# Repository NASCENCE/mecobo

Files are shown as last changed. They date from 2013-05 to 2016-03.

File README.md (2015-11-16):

# mecobo

Mecobo is an open source experimental platform made for the EU-funded NASCENCE project.

It consists of a custom produced PCB, communicating with a host computer using
a USB 2.0 interface. The host computer runs a Thrift Server that exposes the features of the board through a Thrift Interface.

### The most recent branch is Mecobo_v4.1.

What follows is a short description of each of the subfolders.

## host
This contains the implementation of the Thrift server that uses the board as
it's backend. Also contains makefile for linux based systems.

## fpga
This contains the HDL of the hardware that runs on the FPGA on the Mecobo
motherboard.

## uc 
This contains the firmware that runs on the microcontroller of the Mecobo
motherboard. This is the unit that exposes the USB interface to the host
computer.

## interface_hardware
This contains the Altium schematics and also preproduced Gerber files that you
can use to produce your own version of the board.

## winbuild
This contains a Visual Studio project which you can use to build the Thrift
server to run on a windows machine.

## EMServer
Contains a 'dummy' implementation of the Thrift server to be used for testing, and various support software to be used on the client side. 

# Misc

### specifications

Daughterboards has 16 pins. Each daughterboard has max 8 analogue inputs and 8
analogue outputs, along with potentially 16 digital channels througout the
entire stack.

With 1 daughterboard connected, there is a maximum samplerate of about 200K
samples/second output for each of the analoge output pins. For analogue input, a
maxium rate of 75K samples/second. These rates are divided by 8 for each
stacked daughterboard. Note that these are absolute maximum ratings that can be
achieved, and that these numbers depend highly on the usage pattern of the stack.

With no daughterboard connected, each IO pin controlled by the fpga can toggle
at rates > 10MHz.

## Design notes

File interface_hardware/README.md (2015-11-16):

# Hardware interface files

These directories contain ALTIUM project files and schematic files for
producing your own version of the NASCENCE interface hardware. 

### mecobo_motherboard

This is the "motherboard", which we call "mecobo". It can connect to the material directly.

### mixed_signal_daughterboard

This is the mixed signal daughterboard, which is a daughterboard that connects to the mecobo motherboard.

### crossbar_NI_PCB

This is a special board created for the project that acts as a break-out board
for a National  Instruments cable.

## Gerber files

The directories also contain the subdirectory generated/. This contains the
gerber and NC drill files you need to make a PCB without going through Altium.
You should be able to zip up these files and send them to your favorite PCB
manufacturer for production.

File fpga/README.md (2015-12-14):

# FPGA design

What follows are a few brief comments about how the FPGA design is done.

The system is composed of the modules "digital pincontroller", "adc controller", "dac controller" and some FIFOs that receieve commands from the microcontroller and pushes collected samples to the microcontroller.

The EBI bus connects these modules to the microcontroller interface.

## EBI bus and ebi interface
20 bit address, 16 bit data word Interface bus. The EBI interface module takes
care of all requests to the physical interface. The microcontroller can read the
status register from address 0 and write 80-bit commands on addresses 1 through
5. After address 5 has been written, the command is pushed to the 'command
   FIFO', whose outputs are read by the 'scheduler' unit. This unit looks at the
   timestamp (the topmost 32 bits of the command) to decide if the command is to
   be scheduled. This process is controlled by a 1MHz clock, effectively giving
   a 1us scheduling granularity.

## Digital pin controller
Numerically Controlled Oscillator with a 32 bit phase accumulator-based design.

## ADC controller
Forwards commands from the EBI bus and shifts them out serially to the ADC via the SPI interface.
Also continuously shifts in sampling data from the ADC. User sets sampling rate which effectively discards the unused samples by setting an overflow register that counts the number of cycles between each wanted sample that's ready for harvest.

## DAC controller
Shifts out data to the DAC serially.

## Sample collector 
Programmed by appending the channels to a list. The list is iterated round-robin, and if a unit (ADC/Digital pin controller) has a new sample ready (based on the user's sample rate selection of the ADC/PC) a new sample is pushed to a FIFO that can be read from the EBI interface.

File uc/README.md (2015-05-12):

# Firmware

This contains the firmware that runs on the microcontroller (an EFM32GG990F1024
at 48MHz) on the Mecobo motherboard.

## Building

Running build.sh will attempt to: 
- download the dependency Energy Micro / Silicon Labs libraries, and unzip them in the current directory.
- download the Linaro ARM GCC Toolchain and unzip it in the current directory (might want to install this properly)
- build the firmware

If something fails, it shouldn't be too hard to discern what needs to be done by peeking at build.sh.

# NOR Flash
This version of the board contains a 256Mb NOR flash that holds
bitfiles. The first 512 bytes is reserved for a file allocation table
that holds information about the rest of the chip. The region is divided
into 512/16=32 fields, where each field is laid out as follows:

0 -  7: File identifier
8 - 11: File size
12 -15: Byte-offset of file in chip.

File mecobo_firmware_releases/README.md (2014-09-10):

= Firmware releases =
This folder contains firmware binary files that we from time to time compile. It contains two FPGA bitfiles, one for daughterboard attached, and one without. It also contains the ELF binary for the microcontroller.

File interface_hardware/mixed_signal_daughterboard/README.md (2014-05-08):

-Mixed signal daughterboard-

This folder contains the ALTIUM schematic files for the mixed signal
daughterboard that is compatible with the mecobo motherboard.

In the generated/ subfolder you will find:
 - Gerber files (*.G..)
 - PDF of schematics and PCB (daughterboard.pdf)

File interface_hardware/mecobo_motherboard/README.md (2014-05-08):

= INTERFACE HARDWARE =

This directory contains the ALTIUM Schematic documents, and PCB files for
the Mecobo Interface hardware.

In the generated/ subfolder you will find Gerber files and NC drill files
which you can use to create a version of the board if you want to. You
will also find mecobo3.pdf, which is a PDF version of the schematics and
the PCB files.

- Technical details - 
8 layer PCB, copper plated top and bottom. 0.2mm minimum clearance.

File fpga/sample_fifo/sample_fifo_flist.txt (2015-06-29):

# Output products list for <sample_fifo>
sample_fifo/doc/fifo_generator_v9_3_readme.txt
sample_fifo/doc/fifo_generator_v9_3_vinfo.html
sample_fifo/doc/pg057-fifo-generator.pdf
sample_fifo/example_design/sample_fifo_exdes.ucf
sample_fifo/example_design/sample_fifo_exdes.vhd
sample_fifo/fifo_generator_v9_3_readme.txt
sample_fifo/implement/implement.bat
sample_fifo/implement/implement.sh
sample_fifo/implement/implement_synplify.bat
sample_fifo/implement/implement_synplify.sh
sample_fifo/implement/planAhead_ise.bat
sample_fifo/implement/planAhead_ise.sh
sample_fifo/implement/planAhead_ise.tcl
sample_fifo/implement/xst.prj
sample_fifo/implement/xst.scr
sample_fifo/simulation/functional/simulate_isim.bat
sample_fifo/simulation/functional/simulate_isim.sh
sample_fifo/simulation/functional/simulate_mti.bat
sample_fifo/simulation/functional/simulate_mti.do
sample_fifo/simulation/functional/simulate_mti.sh
sample_fifo/simulation/functional/simulate_ncsim.sh
sample_fifo/simulation/functional/simulate_vcs.sh
sample_fifo/simulation/functional/ucli_commands.key
sample_fifo/simulation/functional/vcs_session.tcl
sample_fifo/simulation/functional/wave_isim.tcl
sample_fifo/simulation/functional/wave_mti.do
sample_fifo/simulation/functional/wave_ncsim.sv
sample_fifo/simulation/sample_fifo_dgen.vhd
sample_fifo/simulation/sample_fifo_dverif.vhd
sample_fifo/simulation/sample_fifo_pctrl.vhd
sample_fifo/simulation/sample_fifo_pkg.vhd
sample_fifo/simulation/sample_fifo_rng.vhd
sample_fifo/simulation/sample_fifo_synth.vhd
sample_fifo/simulation/sample_fifo_tb.vhd
sample_fifo/simulation/timing/simulate_isim.bat
sample_fifo/simulation/timing/simulate_isim.sh
sample_fifo/simulation/timing/simulate_mti.bat
sample_fifo/simulation/timing/simulate_mti.do
sample_fifo/simulation/timing/simulate_mti.sh
sample_fifo/simulation/timing/simulate_ncsim.sh
sample_fifo/simulation/timing/simulate_vcs.sh
sample_fifo/simulation/timing/ucli_commands.key
sample_fifo/simulation/timing/vcs_session.tcl
sample_fifo/simulation/timing/wave_isim.tcl
sample_fifo/simulation/timing/wave_mti.do
sample_fifo/simulation/timing/wave_ncsim.sv
sample_fifo.asy
sample_fifo.gise
sample_fifo.ngc
sample_fifo.v
sample_fifo.veo
sample_fifo.xco
sample_fifo.xise
sample_fifo_flist.txt
sample_fifo_xmdf.tcl

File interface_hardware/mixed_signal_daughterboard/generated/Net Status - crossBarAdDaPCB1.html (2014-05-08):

Altium customize

# Net Status Report

Date | : | 03.03.2014
Time | : | 17:36:52
Elapsed Time | : | 00:00:00
Filename | : | C:\Users\gunnart\Dropbox\InterfaceHW\PCB\crossBarAdDa\PCB_Project1 (06-02-2014 15-46-04)\crossBarAdDaPCB1.PcbDoc
Units | : | mmmils

Nets | Layer | Length
-12V | Signal Layers Only | 128.0226mm
12V | Signal Layers Only | 114.0559mm
AGND | Signal Layers Only | 168.261mm
CONNECT_0 | Signal Layers Only | 79.0628mm
CONNECT_1 | Signal Layers Only | 78.3524mm
CONNECT_10 | Signal Layers Only | 90.4802mm
CONNECT_11 | Signal Layers Only | 90.0555mm
CONNECT_12 | Signal Layers Only | 91.4366mm
CONNECT_13 | Signal Layers Only | 93.5986mm
CONNECT_14 | Signal Layers Only | 95.1107mm
CONNECT_15 | Signal Layers Only | 106.7727mm
CONNECT_2 | Signal Layers Only | 78.8532mm
CONNECT_3 | Signal Layers Only | 79.8531mm
CONNECT_4 | Signal Layers Only | 80.936mm
CONNECT_5 | Signal Layers Only | 81.8458mm
CONNECT_6 | Signal Layers Only | 82.405mm
CONNECT_7 | Signal Layers Only | 85.9289mm
CONNECT_8 | Signal Layers Only | 88.9035mm
CONNECT_9 | Signal Layers Only | 90.154mm
DIO0 | Signal Layers Only | 173.5972mm
DIO1 | Signal Layers Only | 171.2606mm
DIO10 | Signal Layers Only | 161.2825mm
DIO11 | Signal Layers Only | 159.9802mm
DIO12 | Signal Layers Only | 158.9654mm
DIO13 | Signal Layers Only | 157.1153mm
DIO14 | Signal Layers Only | 157.6435mm
DIO15 | Signal Layers Only | 159.6454mm
DIO2 | Signal Layers Only | 168.2809mm
DIO3 | Signal Layers Only | 168.4141mm
DIO4 | Signal Layers Only | 170.8003mm
DIO5 | Signal Layers Only | 168.801mm
DIO6 | Signal Layers Only | 166.8415mm
DIO7 | Signal Layers Only | 165.5094mm
DIO8 | Signal Layers Only | 164.4435mm
DIO9 | Signal Layers Only | 163.1128mm
GND | Signal Layers Only | 37.7343mm
Net*1_15 | Signal Layers Only | 33.1769mm
Net*1_16 | Signal Layers Only | 70.4425mm
Net*1_17 | Signal Layers Only | 47.7717mm
Net*1_18 | Signal Layers Only | 72.7822mm
Net*1_19 | Signal Layers Only | 58.9861mm
Net*1_20 | Signal Layers Only | 95.6486mm
Net*1_21 | Signal Layers Only | 60.9213mm
Net*1_22 | Signal Layers Only | 88.7957mm
Net*1_23 | Signal Layers Only | 41.3441mm
Net*1_24 | Signal Layers Only | 43.1173mm
Net*1_25 | Signal Layers Only | 45.8432mm
Net*1_26 | Signal Layers Only | 46.4241mm
Net*1_27 | Signal Layers Only | 42.7648mm
Net*1_28 | Signal Layers Only | 45.9637mm
Net*1_29 | Signal Layers Only | 51.0543mm
Net*1_30 | Signal Layers Only | 56.0322mm
Net*1_44 | Signal Layers Only | 40.515mm
NetC51_1 | Signal Layers Only | 16.1984mm
NetC55_1 | Signal Layers Only | 2.7982mm
NetP1_1 | Signal Layers Only | 17.2157mm
NetP1_3 | Signal Layers Only | 18.7141mm
NetP1_5 | Signal Layers Only | 20.5357mm
NetP1_7 | Signal Layers Only | 21.6133mm
NetP2_1 | Signal Layers Only | 11.4443mm
NetP2_2 | Signal Layers Only | 50.101mm
NetP2_3 | Signal Layers Only | 15.9292mm
NetP2_5 | Signal Layers Only | 20.3396mm
NetP2_7 | Signal Layers Only | 25.0476mm
NetP3_1 | Signal Layers Only | 11.2249mm
NetP3_3 | Signal Layers Only | 13.6469mm
NetP3_5 | Signal Layers Only | 14.8117mm
NetP3_7 | Signal Layers Only | 16.6024mm
NetP4_1 | Signal Layers Only | 9.9421mm
NetP4_2 | Signal Layers Only | 40.558mm
NetP4_3 | Signal Layers Only | 12.7797mm
NetP4_5 | Signal Layers Only | 17.7109mm
NetP4_7 | Signal Layers Only | 21.7929mm
NetP5_1 | Signal Layers Only | 6.1794mm
NetP5_3 | Signal Layers Only | 9.4251mm
NetP5_5 | Signal Layers Only | 13.5379mm
NetP5_7 | Signal Layers Only | 19.3619mm
NetP6_1 | Signal Layers Only | 14.0768mm
NetP6_2 | Signal Layers Only | 21.4842mm
NetP6_3 | Signal Layers Only | 15.8728mm
NetP6_5 | Signal Layers Only | 21.7584mm
NetP6_7 | Signal Layers Only | 23.0773mm
NetP7_1 | Signal Layers Only | 12.9864mm
NetP7_2 | Signal Layers Only | 117.0562mm
NetP7_3 | Signal Layers Only | 15.8765mm
NetP7_5 | Signal Layers Only | 21.6006mm
NetP7_7 | Signal Layers Only | 22.6038mm
NetP8_1 | Signal Layers Only | 11.9794mm
NetP8_2 | Signal Layers Only | 122.0288mm
NetP8_3 | Signal Layers Only | 15.5917mm
NetP8_5 | Signal Layers Only | 20.1637mm
NetP8_7 | Signal Layers Only | 21.6006mm
NetP9_1 | Signal Layers Only | 10.8056mm
NetP9_2 | Signal Layers Only | 133.4299mm
NetP9_3 | Signal Layers Only | 13.9099mm
NetP9_5 | Signal Layers Only | 18.9028mm
NetP9_7 | Signal Layers Only | 20.5447mm
NetPnorth1_2 | Signal Layers Only | 73.8369mm
NetPnorth1_4 | Signal Layers Only | 78.8482mm
NetR10_1 | Signal Layers Only | 8.6112mm
NetR13_1 | Signal Layers Only | 8.2302mm
NetR14_1 | Signal Layers Only | 8.2828mm
NetR17_1 | Signal Layers Only | 8.1552mm
NetR1_1 | Signal Layers Only | 7.7829mm
NetR20_1 | Signal Layers Only | 8.2865mm
NetR22_1 | Signal Layers Only | 7.6281mm
NetR24_1 | Signal Layers Only | 8.2647mm
NetR27_2 | Signal Layers Only | 3.2607mm
NetR2_1 | Signal Layers Only | 8.252mm
NetR5_1 | Signal Layers Only | 8.4316mm
NetR6_1 | Signal Layers Only | 8.4316mm
NetR9_1 | Signal Layers Only | 7.6986mm
NetU1_1 | Signal Layers Only | 0mm
NetU1_3 | Signal Layers Only | 44.6679mm
NetU2_1 | Signal Layers Only | 0mm
NetU2_3 | Signal Layers Only | 38.7336mm
NetU3_1 | Signal Layers Only | 0mm
NetU3_3 | Signal Layers Only | 26.9793mm
NetU4_1 | Signal Layers Only | 0mm
NetU4_3 | Signal Layers Only | 38.0461mm
NetU5_1 | Signal Layers Only | 0mm
NetU5_3 | Signal Layers Only | 26.8062mm
NetU6_1 | Signal Layers Only | 0mm
NetU6_3 | Signal Layers Only | 21.6926mm
NetU7_1 | Signal Layers Only | 0mm
NetU7_3 | Signal Layers Only | 16.7116mm
NetU8_1 | Signal Layers Only | 0mm
NetU8_3 | Signal Layers Only | 26.9256mm
PCKL_XBAR | Signal Layers Only | 123.3795mm
SCLK_XBAR | Signal Layers Only | 205.1017mm
SDATA_FROM_XBAR | Signal Layers Only | 121.6941mm
SDATA_TO_XBAR | Signal Layers Only | 85.9763mm
VA5+ | Signal Layers Only | 234.7269mm
VA5- | Signal Layers Only | 111.3096mm
VADRIVE+ | Signal Layers Only | 264.5179mm
VADRIVE- | Signal Layers Only | 249.2073mm
VANEG | Signal Layers Only | 307.8802mm
VAPOS | Signal Layers Only | 301.2715mm
VCC | Signal Layers Only | 164.1396mm
VDIG | Signal Layers Only | 157.2368mm
VREFDA | Signal Layers Only | 145.7971mm
XGND | Signal Layers Only | 5.7882mm

Back to top

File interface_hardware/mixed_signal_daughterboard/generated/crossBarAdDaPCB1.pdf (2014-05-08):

Comment | Description | Designator | Footprint | LibRef | Quantity
AD5308BRUZ | Octal 8-Bit Voltage Output Digital-to-Analog Converter, 2.5 to 5.5 V, -40 to +125 degC, RU-16, Pb-Free, Tube | U14 | RU-16_N | AD5308BRUZ | 1
AD7327BRUZ | Octal 12-Bit True Bipolar Input Plus Sign Analog-to-Digital Converter with Serial, SPI Interface, Software-Selectable, 500KSPS, -40 to +85 degC, RU-20, Pb-Free, Tube | U15 | RU-20_N | AD7327BRUZ | 1
Header 18X2 | Header, 18-Pin, Dual row | P10 | HDR2X18 | Header 18X2 | 1
Header 3X2 | Header, 3-Pin, Dual row | P13 | HDR2X3 | Header 3X2 | 1
Header 6 | Header, 6-Pin | P12 | HDR1X6 | Header 6 | 1
LT3080EST | Adjustable 1.1 A Single Resistor Low Dropout Regulator, 0.3 mA Isupply, 3-pin SOT223 (ST-3), -40 to 125 degC | U13 | LT-ST-3-SOT-223_N | LT3080EST | 1
REF19x Serie | | *3 | SOIC127P600-8M | REF19x Serie | 1
AD75019 | crosspoint 16x16 | *1, *2 | PLCC-44AL | Component_ 1 | 2
Ferrit | Resistor | R19, R26 | AXIAL-0.4 | Res2 | 2
Header 30X2 | Header, 30-Pin, Dual row | Pnorth1, Pwest1 | HDR2X30 | Header 30X2 | 2
LT1963AEQ | 1.5 A, Low Noise, Fast Transient Response LDO Regulator, 2.1 to 20 V Vin, Adjustable Vout, 5-pin DPAK (Q-5), -40 to 125 degC | U9, U11 | LT-Q-5_N | LT1963AEQ | 2
LT3015EQ#TRPBF | 1.5 A, Low Noise, Negative Linear Regulator with Precision Current Limit, -1.8 to -30 V Vin, Adjustable Vout, 5-pin DPAK (Q-5), -40 to 125 degC, Pb-Free, Tape and Reel | U10, U12 | LT-Q-5_N | LT3015EQ#TR PBF | 2
AD820BR | Single-Supply, Rail-to-Rail Low-Power FET-Input Operational Amplifier | U1, U2, U3, U4, U5, U6, U7, U8 | R-8D_N | AD820BR | 8
Header 4X2 | Header, 4-Pin, Dual row | P1, P2, P3, P4, P5, P6, P7, P8, P9 | HDR2X4 | Header 4X2 | 9
Res3 | Resistor | R17, R18, R20, R21, R22, R23, R24, R25, R27 | 14-1210 | Res3 | 9
Res1 | Resistor | R1, R2, R3, R4, R5, R6, R7, R8, R9, R10, R11, R12, R13, R14, R15, R16 | C1206 | Res1 | 16
Cap Semi | Capacitor (Semiconductor SIM MoC1, C 2, C3, C4, C5, C6, | | 1206 | Cap S em i | 55

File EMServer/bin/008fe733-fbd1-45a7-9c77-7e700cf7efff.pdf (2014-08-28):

# PIN15

# PIN14

# PIN13

# PIN12

# PIN11

# PIN10

# PIN09

# PIN08

# PIN07

# PIN06

# PIN05

# PIN04

# PIN02

# PIN01

# PIN00

CONSTANT 1V

CONSTANT 1V

CONSTANT 1V

CONSTANT 1V

CONSTANT 1V

CONSTANT 1V

CONSTANT 1V

CONSTANT 1V

CONSTANT 1V

CONSTANT 1V

CONSTANT 1V

CONSTANT 1V

CONSTANT 1V

CONSTANT 1V

CONSTANT 1V

CONSTANT 1V

CONSTANT 1V

CONSTANT 1V

CONSTANT 1V

CONSTANT 1V

CONSTANT 1V

CONSTANT 1V

CONSTANT 1V

CONSTANT 1V

CONSTANT 1V

CONSTANT 1V

CONSTANT 1V

CONSTANT 1V

CONSTANT 1V

CONSTANT 1V

CONSTANT 16V

CONSTANT 16V

CONSTANT 16V

CONSTANT 16V

CONSTANT 16V

CONSTANT 16V

CONSTANT 16V

CONSTANT 16V

CONSTANT 16V

CONSTANT 16V

CONSTANT 16V

CONSTANT 16V

CONSTANT 16V

CONSTANT 16V

CONSTANT 16V

CONSTANT 20V

CONSTANT 20V

CONSTANT 20V

CONSTANT 20V

CONSTANT 20V

CONSTANT 20V

CONSTANT 20V

CONSTANT 20V

CONSTANT 20V

CONSTANT 20V

CONSTANT 20V

CONSTANT 20V

CONSTANT 20V

CONSTANT 20V

CONSTANT 20V

CONSTANT 168V

CONSTANT 168V

CONSTANT 168V

CONSTANT 168V

CONSTANT 168V

CONSTANT 168V

CONSTANT 168V

CONSTANT 168V

CONSTANT 168V

CONSTANT 168V

CONSTANT 168V

CONSTANT 168V

CONSTANT 168V

CONSTANT 168V

CONSTANT 168V

CONSTANT 110V

CONSTANT 110V

CONSTANT 110V

CONSTANT 110V

CONSTANT 110V

CONSTANT 110V

CONSTANT 110V

CONSTANT 110V

CONSTANT 110V

CONSTANT 110V

CONSTANT 110V

CONSTANT 110V

CONSTANT 110V

CONSTANT 110V

CONSTANT 110V

CONSTANT 9V

CONSTANT 9V

CONSTANT 9V

CONSTANT 9V

CONSTANT 9V

CONSTANT 9V

CONSTANT 9V

CONSTANT 9V

CONSTANT 9V

CONSTANT 9V

CONSTANT 9V

CONSTANT 9V

CONSTANT 9V

CONSTANT 9V

CONSTANT 9V

RECORD

RECORD

RECORD

RECORD

RECORD

RECORD

RECORD

RECORD

RECORD

RECORD

RECORD

RECORD

RECORD

RECORD

RECORD

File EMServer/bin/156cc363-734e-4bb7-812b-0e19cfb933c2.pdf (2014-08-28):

# PIN15

# PIN14

# PIN13

# PIN12

# PIN11

# PIN10

# PIN09

# PIN07

# PIN06

# PIN05

# PIN04

# PIN02

# PIN01

# PIN00

CONSTANT 255V

CONSTANT 255V

CONSTANT 255V

CONSTANT 255V

CONSTANT 255V

CONSTANT 255V

CONSTANT 255V

CONSTANT 255V

CONSTANT 255V

CONSTANT 255V

CONSTANT 255V

CONSTANT 255V

CONSTANT 255V

CONSTANT 255V

CONSTANT 255V

CONSTANT 255V

CONSTANT 255V

CONSTANT 255V

CONSTANT 255V

CONSTANT 255V

CONSTANT 255V

CONSTANT 255V

CONSTANT 255V

CONSTANT 255V

CONSTANT 255V

CONSTANT 255V

CONSTANT 153V

CONSTANT 153V

CONSTANT 153V

CONSTANT 153V

CONSTANT 153V

CONSTANT 153V

CONSTANT 153V

CONSTANT 153V

CONSTANT 153V

CONSTANT 153V

CONSTANT 153V

CONSTANT 153V

CONSTANT 153V

CONSTANT 90V

CONSTANT 90V

CONSTANT 90V

CONSTANT 90V

CONSTANT 90V

CONSTANT 90V

CONSTANT 90V

CONSTANT 90V

CONSTANT 90V

CONSTANT 90V

CONSTANT 90V

CONSTANT 90V

CONSTANT 90V

CONSTANT 203V

CONSTANT 203V

CONSTANT 203V

CONSTANT 203V

CONSTANT 203V

CONSTANT 203V

CONSTANT 203V

CONSTANT 203V

CONSTANT 203V

CONSTANT 203V

CONSTANT 203V

CONSTANT 203V

CONSTANT 203V

CONSTANT 218V

CONSTANT 218V

CONSTANT 218V

CONSTANT 218V

CONSTANT 218V

CONSTANT 218V

CONSTANT 218V

CONSTANT 218V

CONSTANT 218V

CONSTANT 218V

CONSTANT 218V

CONSTANT 218V

CONSTANT 218V

CONSTANT 17V

CONSTANT 17V

CONSTANT 17V

CONSTANT 17V

CONSTANT 17V

CONSTANT 17V

CONSTANT 17V

CONSTANT 17V

CONSTANT 17V

CONSTANT 17V

CONSTANT 17V

CONSTANT 17V

CONSTANT 17V

RECORD

RECORD

RECORD

RECORD

RECORD

RECORD

RECORD

RECORD

RECORD

RECORD

RECORD

RECORD

RECORD

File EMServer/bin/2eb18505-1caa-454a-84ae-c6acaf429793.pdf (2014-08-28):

# PIN15

# PIN14

# PIN13

# PIN12

# PIN11

# PIN10

# PIN09

# PIN08

# PIN07

# PIN06

# PIN05

# PIN04

# PIN02

# PIN01

# PIN00

CONSTANT 1V

CONSTANT 1V

CONSTANT 1V

CONSTANT 1V

CONSTANT 1V

CONSTANT 1V

CONSTANT 1V

CONSTANT 1V

CONSTANT 1V

CONSTANT 1V

CONSTANT 1V

CONSTANT 1V

CONSTANT 1V

CONSTANT 1V

CONSTANT 1V

CONSTANT 255V

CONSTANT 255V

CONSTANT 255V

CONSTANT 255V

CONSTANT 255V

CONSTANT 255V

CONSTANT 255V

CONSTANT 255V

CONSTANT 255V

CONSTANT 255V

CONSTANT 255V

CONSTANT 255V

CONSTANT 255V

CONSTANT 255V

CONSTANT 255V

CONSTANT 148V

CONSTANT 148V

CONSTANT 148V

CONSTANT 148V

CONSTANT 148V

CONSTANT 148V

CONSTANT 148V

CONSTANT 148V

CONSTANT 148V

CONSTANT 148V

CONSTANT 148V

CONSTANT 148V

CONSTANT 148V

CONSTANT 148V

CONSTANT 148V

CONSTANT 88V

CONSTANT 88V

CONSTANT 88V

CONSTANT 88V

CONSTANT 88V

CONSTANT 88V

CONSTANT 88V

CONSTANT 88V

CONSTANT 88V

CONSTANT 88V

CONSTANT 88V

CONSTANT 88V

CONSTANT 88V

CONSTANT 88V

CONSTANT 88V

CONSTANT 20V

CONSTANT 20V

CONSTANT 20V

CONSTANT 20V

CONSTANT 20V

CONSTANT 20V

CONSTANT 20V

CONSTANT 20V

CONSTANT 20V

CONSTANT 20V

CONSTANT 20V

CONSTANT 20V

CONSTANT 20V

CONSTANT 20V

CONSTANT 20V

CONSTANT 87V

CONSTANT 87V

CONSTANT 87V

CONSTANT 87V

CONSTANT 87V

CONSTANT 87V

CONSTANT 87V

CONSTANT 87V

CONSTANT 87V

CONSTANT 87V

CONSTANT 87V

CONSTANT 87V

CONSTANT 87V

CONSTANT 87V

CONSTANT 87V

CONSTANT 247V

CONSTANT 247V

CONSTANT 247V

CONSTANT 247V

CONSTANT 247V

CONSTANT 247V

CONSTANT 247V

CONSTANT 247V

CONSTANT 247V

CONSTANT 247V

CONSTANT 247V

CONSTANT 247V

CONSTANT 247V

CONSTANT 247V

CONSTANT 247V

RECORD

RECORD

RECORD

RECORD

RECORD

RECORD

RECORD

RECORD

RECORD

RECORD

RECORD

RECORD

RECORD

RECORD

RECORD

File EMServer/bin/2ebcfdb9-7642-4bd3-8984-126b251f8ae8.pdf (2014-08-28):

# PIN15

# PIN14

# PIN13

# PIN12

# PIN11

# PIN10

# PIN09

# PIN08

# PIN07

# PIN06

# PIN05

# PIN04

# PIN02

# PIN01

# PIN00

CONSTANT 255V

CONSTANT 255V

CONSTANT 255V

CONSTANT 255V

CONSTANT 255V

CONSTANT 255V

CONSTANT 255V

CONSTANT 255V

CONSTANT 255V

CONSTANT 255V

CONSTANT 255V

CONSTANT 255V

CONSTANT 255V

CONSTANT 255V

CONSTANT 255V

CONSTANT 255V

CONSTANT 255V

CONSTANT 255V

CONSTANT 255V

CONSTANT 255V

CONSTANT 255V

CONSTANT 255V

CONSTANT 255V

CONSTANT 255V

CONSTANT 255V

CONSTANT 255V

CONSTANT 255V

CONSTANT 255V

CONSTANT 255V

CONSTANT 255V

CONSTANT 60V

CONSTANT 60V

CONSTANT 60V

CONSTANT 60V

CONSTANT 60V

CONSTANT 60V

CONSTANT 60V

CONSTANT 60V

CONSTANT 60V

CONSTANT 60V

CONSTANT 60V

CONSTANT 60V

CONSTANT 60V

CONSTANT 60V

CONSTANT 60V

CONSTANT 26V

CONSTANT 26V

CONSTANT 26V

CONSTANT 26V

CONSTANT 26V

CONSTANT 26V

CONSTANT 26V

CONSTANT 26V

CONSTANT 26V

CONSTANT 26V

CONSTANT 26V

CONSTANT 26V

CONSTANT 26V

CONSTANT 26V

CONSTANT 26V

CONSTANT 208V

CONSTANT 208V

CONSTANT 208V

CONSTANT 208V

CONSTANT 208V

CONSTANT 208V

CONSTANT 208V

CONSTANT 208V

CONSTANT 208V

CONSTANT 208V

CONSTANT 208V

CONSTANT 208V

CONSTANT 208V

CONSTANT 208V

CONSTANT 208V

CONSTANT 122V

CONSTANT 122V

CONSTANT 122V

CONSTANT 122V

CONSTANT 122V

CONSTANT 122V

CONSTANT 122V

CONSTANT 122V

CONSTANT 122V

CONSTANT 122V

CONSTANT 122V

CONSTANT 122V

CONSTANT 122V

CONSTANT 122V

CONSTANT 122V

CONSTANT 103V

CONSTANT 103V

CONSTANT 103V

CONSTANT 103V

CONSTANT 103V

CONSTANT 103V

CONSTANT 103V

CONSTANT 103V

CONSTANT 103V

CONSTANT 103V

CONSTANT 103V

CONSTANT 103V

CONSTANT 103V

CONSTANT 103V

CONSTANT 103V

RECORD

RECORD

RECORD

RECORD

RECORD

RECORD

RECORD

RECORD

RECORD

RECORD

RECORD

RECORD

RECORD

RECORD

RECORD

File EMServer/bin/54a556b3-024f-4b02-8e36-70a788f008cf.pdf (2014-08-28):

# PIN15

# PIN14

# PIN13

# PIN12

# PIN11

# PIN10

# PIN09

# PIN08

# PIN07

# PIN06

# PIN05

# PIN02

# PIN01

# PIN00

CONSTANT 1V

CONSTANT 1V

CONSTANT 1V

CONSTANT 1V

CONSTANT 1V

CONSTANT 1V

CONSTANT 1V

CONSTANT 1V

CONSTANT 1V

CONSTANT 1V

CONSTANT 1V

CONSTANT 1V

CONSTANT 1V

CONSTANT 255V

CONSTANT 255V

CONSTANT 255V

CONSTANT 255V

CONSTANT 255V

CONSTANT 255V

CONSTANT 255V

CONSTANT 255V

CONSTANT 255V

CONSTANT 255V

CONSTANT 255V

CONSTANT 255V

CONSTANT 255V

CONSTANT 105V

CONSTANT 105V

CONSTANT 105V

CONSTANT 105V

CONSTANT 105V

CONSTANT 105V

CONSTANT 105V

CONSTANT 105V

CONSTANT 105V

CONSTANT 105V

CONSTANT 105V

CONSTANT 105V

CONSTANT 105V

CONSTANT 226V

CONSTANT 226V

CONSTANT 226V

CONSTANT 226V

CONSTANT 226V

CONSTANT 226V

CONSTANT 226V

CONSTANT 226V

CONSTANT 226V

CONSTANT 226V

CONSTANT 226V

CONSTANT 226V

CONSTANT 226V

CONSTANT 222V

CONSTANT 222V

CONSTANT 222V

CONSTANT 222V

CONSTANT 222V

CONSTANT 222V

CONSTANT 222V

CONSTANT 222V

CONSTANT 222V

CONSTANT 222V

CONSTANT 222V

CONSTANT 222V

CONSTANT 222V

CONSTANT 171V

CONSTANT 171V

CONSTANT 171V

CONSTANT 171V

CONSTANT 171V

CONSTANT 171V

CONSTANT 171V

CONSTANT 171V

CONSTANT 171V

CONSTANT 171V

CONSTANT 171V

CONSTANT 171V

CONSTANT 171V

CONSTANT 96V

CONSTANT 96V

CONSTANT 96V

CONSTANT 96V

CONSTANT 96V

CONSTANT 96V

CONSTANT 96V

CONSTANT 96V

CONSTANT 96V

CONSTANT 96V

CONSTANT 96V

CONSTANT 96V

CONSTANT 96V

RECORD

RECORD

RECORD

RECORD

RECORD

RECORD

RECORD

RECORD

RECORD

RECORD

RECORD

RECORD

RECORD

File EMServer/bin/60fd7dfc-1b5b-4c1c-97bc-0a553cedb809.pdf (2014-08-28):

# PIN15

# PIN14

# PIN13

# PIN12

# PIN11

# PIN10

# PIN09

# PIN08

# PIN07

# PIN06

# PIN05

# PIN04

# PIN02

# PIN01

# PIN00

CONSTANT 255V

CONSTANT 255V

CONSTANT 255V

CONSTANT 255V

CONSTANT 255V

CONSTANT 255V

CONSTANT 255V

CONSTANT 255V

CONSTANT 255V

CONSTANT 255V

CONSTANT 255V

CONSTANT 255V

CONSTANT 255V

CONSTANT 255V

CONSTANT 255V

CONSTANT 255V

CONSTANT 255V

CONSTANT 255V

CONSTANT 255V

CONSTANT 255V

CONSTANT 255V

CONSTANT 255V

CONSTANT 255V

CONSTANT 255V

CONSTANT 255V

CONSTANT 255V

CONSTANT 255V

CONSTANT 255V

CONSTANT 255V

CONSTANT 255V

CONSTANT 217V

CONSTANT 217V

CONSTANT 217V

CONSTANT 217V

CONSTANT 217V

CONSTANT 217V

CONSTANT 217V

CONSTANT 217V

CONSTANT 217V

CONSTANT 217V

CONSTANT 217V

CONSTANT 217V

CONSTANT 217V

CONSTANT 217V

CONSTANT 217V

CONSTANT 22V

CONSTANT 22V

CONSTANT 22V

CONSTANT 22V

CONSTANT 22V

CONSTANT 22V

CONSTANT 22V

CONSTANT 22V

CONSTANT 22V

CONSTANT 22V

CONSTANT 22V

CONSTANT 22V

CONSTANT 22V

CONSTANT 22V

CONSTANT 22V

CONSTANT 47V

CONSTANT 47V

CONSTANT 47V

CONSTANT 47V

CONSTANT 47V

CONSTANT 47V

CONSTANT 47V

CONSTANT 47V

CONSTANT 47V

CONSTANT 47V

CONSTANT 47V

CONSTANT 47V

CONSTANT 47V

CONSTANT 47V

CONSTANT 47V

CONSTANT 242V

CONSTANT 242V

CONSTANT 242V

CONSTANT 242V

CONSTANT 242V

CONSTANT 242V

CONSTANT 242V

CONSTANT 242V

CONSTANT 242V

CONSTANT 242V

CONSTANT 242V

CONSTANT 242V

CONSTANT 242V

CONSTANT 242V

CONSTANT 242V

CONSTANT 156V

CONSTANT 156V

CONSTANT 156V

CONSTANT 156V

CONSTANT 156V

CONSTANT 156V

CONSTANT 156V

CONSTANT 156V

CONSTANT 156V

CONSTANT 156V

CONSTANT 156V

CONSTANT 156V

CONSTANT 156V

CONSTANT 156V

CONSTANT 156V

RECORD

RECORD

RECORD

RECORD

RECORD

RECORD

RECORD

RECORD

RECORD

RECORD

RECORD

RECORD

RECORD

RECORD

RECORD

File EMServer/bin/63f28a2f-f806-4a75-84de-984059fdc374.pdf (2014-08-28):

# PIN13

# PIN12

# PIN11

# PIN10

# PIN04

# PIN03

# PIN02

# PIN00

CONSTANT 1V

CONSTANT 1V

CONSTANT 1V

CONSTANT 1V

CONSTANT 255V

CONSTANT 255V

CONSTANT 255V

CONSTANT 255V

CONSTANT 35V

CONSTANT 35V

CONSTANT 35V

CONSTANT 35V

CONSTANT 173V

CONSTANT 173V

CONSTANT 173V

CONSTANT 173V

CONSTANT 175V

CONSTANT 175V

CONSTANT 175V

CONSTANT 175V

CONSTANT 188V

CONSTANT 188V

CONSTANT 188V

CONSTANT 188V

CONSTANT 206V

CONSTANT 206V

CONSTANT 206V

CONSTANT 206V

RECORD

RECORD

RECORD

RECORD

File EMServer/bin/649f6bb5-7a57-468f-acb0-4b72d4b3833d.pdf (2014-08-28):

# PIN15

# PIN14

# PIN12

# PIN09

# PIN07

# PIN03

# PIN01

# PIN00

CONSTANT 1V

CONSTANT 1V

CONSTANT 1V

CONSTANT 1V

CONSTANT 1V

CONSTANT 1V

CONSTANT 1V

CONSTANT 1V

CONSTANT 13V

CONSTANT 13V

CONSTANT 13V

CONSTANT 13V

CONSTANT 11V

CONSTANT 11V

CONSTANT 11V

CONSTANT 11V

CONSTANT 201V

CONSTANT 201V

CONSTANT 201V

CONSTANT 201V

CONSTANT 178V

CONSTANT 178V

CONSTANT 178V

CONSTANT 178V

CONSTANT 24V

CONSTANT 24V

CONSTANT 24V

CONSTANT 24V

RECORD

RECORD

RECORD

RECORD

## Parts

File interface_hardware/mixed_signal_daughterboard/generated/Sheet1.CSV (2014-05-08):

Bill of Material for
On 13/01/2014 at 14:21:59
Comment | Pattern | Quantity | Components
AD5308BRUZ | RU-16_N | 1 | U? | Octal 8-Bit Voltage Output Digital-to-Analog Converter, 2.5 to 5.5 V, -40 to +125 degC, RU-16, Pb-Free, Tube
AD7327BRUZ | RU-20_N | 1 | U? | Octal 12-Bit True Bipolar Input Plus Sign Analog-to-Digital Converter with Serial, SPI Interface, Software-Selectable, 500KSPS, -40 to +85 degC, RU-20, Pb-Free, Tube
AD75019 | P-44A_L | 2 | *, * | crosspoint 16x16
AD820BR | R-8D_N | 8 | U?, U?, U?, U?, U?, U?, U?, U? | Single-Supply, Rail-to-Rail Low-Power FET-Input Operational Amplifier
Cap Semi | C1206 | 55 | C?, C?, C?, C?, C?, C?, C?, C?, C?, C?, C?, C?, C?, C?, C?, C?, C?, C?, C?, C?, C?, C?, C?, C?, C?, C?, C?, C?, C?, C?, C?, C?, C?, C?, C?, C?, C?, C?, C?, C?, C?, C?, C?, C?, C?, C?, C?, C?, C?, C?, C?, C?, C?, C?, C? | Capacitor (Semiconductor SIM Model)
Ferrit | AXIAL-0.4 | 2 | R?, R? | Resistor
Header 18X2 | HDR2X18 | 1 | P? | Header, 18-Pin, Dual row
Header 24X2H | HDR2X24H | 1 | P? | Header, 24-Pin, Dual row, Right Angle
Header 30X2 | HDR2X30 | 2 | Pnorth, Pwest | Header, 30-Pin, Dual row
Header 3X2 | HDR2X3 | 1 | P? | Header, 3-Pin, Dual row
Header 4X2 | HDR2X4 | 9 | P?, P?, P?, P?, P?, P?, P?, P?, P? | Header, 4-Pin, Dual row
Header 6 | HDR1X6 | 1 | P? | Header, 6-Pin
LT1963AEQ | LT-Q-5_N | 2 | U?, U? | 1.5 A, Low Noise, Fast Transient Response LDO Regulator, 2.1 to 20 V Vin, Adjustable Vout, 5-pin DPAK (Q-5), -40 to 125 degC
LT3015EQ#TRPBF | LT-Q-5_N | 2 | U?, U? | 1.5 A, Low Noise, Negative Linear Regulator with Precision Current Limit, -1.8 to -30 V Vin, Adjustable Vout, 5-pin DPAK (Q-5), -40 to 125 degC, Pb-Free, Tape and Reel
LT3080EST | LT-ST-3-SOT-223_N | 1 | U? | Adjustable 1.1 A Single Resistor Low Dropout Regulator, 0.3 mA Isupply, 3-pin SOT223 (ST-3), -40 to 125 degC
REF19x Serie | SOIC | 1 | *
Res1 | AXIAL-0.3 | 16 | R?, R?, R?, R?, R?, R?, R?, R?, R?, R?, R?, R?, R?, R?, R?, R? | Resistor
Res3 | 14-1210 | 9 | R?, R?, R?, R?, R?, R?, R?, R?, R? | Resistor

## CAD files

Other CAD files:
winbuild/libusb-win32-src-1.2.6.0/libusb-win32-src-1.2.6.0/projects/additional/libwdi/helper/embedder/embedder.obj

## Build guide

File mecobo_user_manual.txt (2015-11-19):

Mecobo user manual

- At a glance - 
The system consists of three units; the thrift server, the thrift client and
the board. The server runs on a host computer that has the board connected to
it, and the client communicates with the server via an internet socket.

Usage is as simple as:
1 - Plug in the board. Any recent linux kernel has a ACM driver compiled in. As
such you can simply plug in a powered-on (and preconfigured) board. On Windows
you will have to use the provided .ini file and install that as a driver to
enable communication.
2 - Start the Thrift server binary.
3 - Connect to the Thrift server with a Thrift client and send commands to it
using the Thrift interface.

There is a section below on setting up the thrift server; and you can of course
recompile and modify it as you see fit-- however the current implementation should
suffice for simple stuff.

========================================================================================
- USER GUIDE -
========================================================================================

Current version of the board only supports the following modes of operation:

1. Digital output square waves with 50% duty cycle:

Example:
    it = emSequenceItem();
    it.pin = [0];
    it.startTime = 1;
    it.endTime = 1000;
    it.frequency = 500;
    it.operationType = emSequenceOperationType::type::DIGITAL;

2. Digital recording of a pin:

Example:
    rec = emSequenceItem();
    rec.pin = [10];
    rec.starttime = 0;
    rec.endTime = 1000;
    rec.frequency = 5000;
    rec.waveformType = emWaveFormType::PWM; //magic line for digital sampling
    rec.operationType = emSequenceOperationType::type::RECORD;

3. Constant 0 (connect to ground) or 3.3V output on pin

Example:
    it = emSequenceItem();
    it.pin = [4];
    it.starttime = 0;
    it.endTime = 1000;
    it.frequency = 1;   //or 0 for grounding
    it.cycleTime = 100;  //required as well.
    it.operationType = emSequenceOperationType::type::DIGITAL;

4. Analog recording of a pin:

Example:
    rec = emSequenceItem();
    rec.pin = [10];
    rec.starttime = 0;
    rec.endTime = 1000;
    rec.frequency = 5000;  //max total sum of sample rates is 500KHz
    rec.operationType = emSequenceOperationType::type::RECORD;

5. Analog output of voltage:

Example:
    it = emSequenceItem();
    it.pin = [10];
    it.starttime = 0;
    it.endTime = 1000;
    it.amplitude = 242;   //-5 to 5V is scaled between 0 and 255.
    it.operationType = emSequenceOperationType::type::CONSTANT;

=======================================================================================
USER GUIDE WITH MORE WORDS
=======================================================================================

To start the server, place yourself in the directory of the server binary
(usually called winHost), and run it from the command line with:

~> winHost.exe

Now that the server is running on a computer that has the board connected to
it, talking to the board consists of calling the functions described in the
thrift interface description file, NascenseAPI_v01e.thrift. You also need to
generate the code that talks to the server. This is done with the thrift tool.

As an example, here is how you create a client in python:

oddrune @ crabcatcher:~$ thrift --gen py NascenseAPI_v01e.thrift

This gives me a directory called gen-py, that again contains a subdirectory NascenseAPI_v01e.
My python client looks like this:

--
import sys
sys.path.append('gen-py/NascenseAPI_v01e/')
import emEvolvableMotherboard
from ttypes import *

try:
  transport = TSocket.TSocket('dmlab02.idi.ntnu.no', 9090)
  transport = TTransport.TBufferedTransport(transport)

  prot = TBinaryProtocol.TBinaryProtocol(transport)
  cli = emEvolvableMotherboard.Client(prot);
  transport.open();

  cli.ping();

  transport.close();

except Thrift.TException, tx:
  print tx

That's all there is to it. It's similar in most languages and the apache thrift
wiki has more examples. 

- Using the Nascence interface -
Note that all of the examples here are done using python; but it's analogous to
other languages such as C#, C++, perl, ... 

The idea behind the interface is that of a sequencer. Using the function
appendSequenceAction(emSequenceItem) you append an item that performs a certain action.
The emSequenceItem is defined in the interface as well.

Example:
----------------------------------------------------------
it = emSequenceItem()
it.pin = 12;
it.startTime = 42;
it.endTime = 100;
it.amplitude = 0;
it.operationType = emSequenceOperationType().CONSTANT;
client.appendSequenceAction(it)
----------------------------------------------------------

This example creates a sequnce item and appends it to the sequence queue. The output will be -5 Volts on pin 12, if the daughterboard is connected.

Calling client.runSequences() initiates this sequence, and starts the clock at
time = 0. All times referred to in the emSequenceItems are relative to this t,
and time is measured in ms. 

Remember to call client.joinSequences() when you are done so that the board
blocks until it is done.

Another frequenctly used operationType is RECORD:

----------------------------------------------------------
rec = emSequenceItem();
rec.pin = 10;
rec.starttime = 0;
rec.endTime = 1000;
rec.frequency = 5000;
rec.operationType = emSequenceOperationType().RECORD;
client.appendSequenceAction(rec)
----------------------------------------------------------

This will set up pin 10 as a recording pin, which will start recording at t=0, and end at t=1000 at a 
sample frequency of 5Khz.  Doing:

----------------------------------------------------------
recording = cli.getRecording(recordPin);
----------------------------------------------------------

will get you a buffer of the sampled data of about 5000 elements.

If you in addition the above specify 

rec.waveformType = emWaveFormType::PWM 

you will get a digital recording pin,
which only returns a buffer consisting of 1 or 0, depending on if the sampled
signal crossed the threshold for the FPGA input buffer, usually around 2.5V. 

- Other operationTypes - 

DIGITAL
----------------------------------------------------------
it = emSequenceItem();
it.pin = 0;
it.startTime = 1;
it.endTime = 1000;
it.frequency = 500;
it.operationType = emSequenceOperationType::type::DIGITAL;
----------------------------------------------------------

This will set up pin 0 to play a square wave with a cycle time of (1/500)s, of
wich 25% of the cycle will have the pin set to logical 1, for 1 second starting
at t=1.

CONSTANT_FROM_REGISTER:
----------------------------------------------------------
it = emSequenceItem();
it.pin = 0;
it.startTime = 1;
it.endTime = -1;
it.regNr = 3
it.operationType = emSequenceOperationType::type::CONSTANT_FROM_REGISTER;
----------------------------------------------------------

This sets up a sequence item that will not until the board is reset (endtime
-1), and whose output depends on the value one writes with the command
client.setRegister(register, value). 

- Without the daughterboards connected -
There are 45 digital channels that can be programmed individually on header WEST.

- With the analogue daughterboard connected -
If you have the daughterboard plugged in, it's good to let the server know this by adding a -d <number of daughterboards in the stack> to the server startup command. This will enable the DAC and ADC channels, and also redefine the pinouts somewhat. 

Each daughterboard has 16 pins. The daughterboards are stackable, and the name/number (used in the sequence item) is counted from the pin designated as 1 on the board towards pin 47, from 0 to 15. For board two this is pin 16 to 31, and so on.

For each group of 16 daugherboard pins the following restrictions apply (mecobo will let you know when you break them, but it's healthier for your code if you don't)
 - Max 8 analogue inputs.
 - Max 8 analogue outputs.

In addition, you can mix in 16 digital channels throughout the stack.

For one daughterboard this is a valid config 

0    1.2V
1    RA(record analogue)
2    4.5V
3    RA
4    3.3V
5   ...
6
7
8
9
10
11
12
13
14
15

- Getting the Thrift server running -
The thrift server implements a high-level interface, described in
NascenseAPI_v01d.thrift which you can find in the API folder of our shared
Dropbox (same directory as this file). The thrift tool (which you get when you
install the thrift-package in linux or Windows) reads this interface
description and generates a skeleton server file that we have implemented. This
particular implementation of the server talks to the "Mecobo" motherboard. You
simply run this server, and it will start a service that listens for incoming
socket connections on port 9090.

- Upgrading the platform (i.e. when Odd Rune gives you a new mecobo_uc_vXX.bin) -
There are unfortunately still a few prerequisites when it comes to upgrading the platform.

Instructions for windows:
You’ll need to download Simplicity Studio:
 
	http://www.silabs.com/Support%20Documents/Software/simplicity-studio.exe

Once downloaded, run it (I believe this might require Administrator privileges, which may 
or may not be a problem for computers administrated by a certain IT dept.). You’ll only need to
install the ‘Energy Aware Commander’, or eAcommander as it is also called. 
Sometimes eCommander does not install properly. Press update button of simplicity studio for latest update.

Download and install device driver from website.

After you’ve installed the application, it’s time to open up the black box and connect a mini-USB cable
from your PC to the smaller of the two boards inside of the box. Note that there are two possible connection 
points. Use the one on the short side of the board, marked with DEBUG.

Power on the box.

Launch eAcommander from within simplicity studio. Make sure «J-Link device» is set to S/N <some number>. 

Hit ‘Connect’ in the top left corner. 

Select Debug Mode: «out».

On the leftmost column, select «Flash».

Once there, select «Browse» and navigate to the mecobo_uc_vXX.bin file you with to apply. Make sure «Reset EFM32 after flashing» is checked, and then hit «Flash EFM32».

Then disconnect recently connecte cables and connect back old one.

Turn off the board, restart the server (make sure the FPGA gets programmed) and start running experiments again!

- Technical description -
Mecobo consists of one EFM32GG990 microcontroller which acts as a ACM USB slave
device, and one Spartan6 FPGA that controls the digital outputs on the pin
headers.

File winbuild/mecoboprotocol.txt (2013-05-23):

This is a description of the protocol that Mecobo understands.

The packet that goes across the USB interface is structured like this:

-----------------------------------
| Field name		  | Bytes | 
===================================
| Mecobo Packet ID	  | 4	  |
-----------------------------------
| Size of data field 	  | 4	  |
-----------------------------------
| Command 		  | 4     | 
-----------------------------------
| Data			  | 4     |
-----------------------------------
| Padding (32b boundry)   | ?	  |
===================================

The intent is that one of these packets corresponds to one 'tick' of the
sequencer that is used to control the higher-level waves that are applied to
Mecobo. Mecobo recieves and buffers these packets, and will consume 1 packet on
each tick. Likewise, it will store 1 of these packets in a return queue, which
should be read from the host before the buffer is full.

= The Command Field =
Possible values: 
NOOP 		(0x1)
PINCONFIG 	(0x2)
PINDATA 	(0X3)
PINVALUES	(0x4)
STATUS		(0x5)

= Data fields =
The format of the data field depends on the command field.

- NOOP -
Data field is size 0. Do nothing. 

- PINCONFIG -
Consists of one 4-bit field per pin, giving how the pins are to be set up. The
possible values are:
0: digital input
1: digital output
2: DAC output (the pin is used to control an external DAC)
3: ADC input (the pin is used to control an ADC)

When a pin has been set to a function, this function will be used to parse the
data field of a PINDATA command packet.

- PINDATA - 
Consists of nOutput (digital output + DAC output) fields, linearly ordered such that field 0 corresponds to pin 0, 1 to 1, etc.

Each field is 12 bits. Attempting to set a value of not 0 or 1 to a pin typed
as digital output will result in error.

- PINVALUES -
Consists of nInput (digital input + ADC input) fields, linearly ordered as PINDATA.

Each field is 12 bits.

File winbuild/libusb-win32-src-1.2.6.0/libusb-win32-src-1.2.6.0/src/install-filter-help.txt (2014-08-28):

WARNING:
  Improper use of libusb-win32 install-filter can cause devices to
  malfunction and in some cases complete system failure.

DISCLAIMER:
  THIS SOFTWARE IS PROVIDED IN AN "AS IS" CONDITION. NO WARRANTIES,
  WHETHER EXPRESS, IMPLIED OR STATUTORY, INCLUDING, BUT NOT LIMITED
  TO, IMPLIED WARRANTIES OF MERCHANTABILITY AND FITNESS FOR A
  PARTICULAR PURPOSE APPLY TO THIS SOFTWARE. THE ORGANIZATION SHALL
  NOT, IN ANY CIRCUMSTANCES, BE LIABLE FOR SPECIAL, INCIDENTAL OR
  CONSEQUENTIAL DAMAGES, FOR ANY REASON WHATSOEVER.

USAGE: install-filter [install|uninstall|list] <-ac> <-dc> <-ad> 
                                               <-c=> <-d=> <-f=>
                                               <-p=> <-w=>

Commands:             Compatible Switches:
  install   (i/-i)      <-ac> <-c=> <-d=> <-f=> <-p=> <-w=>
  uninstall (u/-u)      <-ac> <-c=> <-d=> <-f=> <-p=> <-w=> <-ad>
  list      (l/-l)      <-ac> <-dc> <-c=> <-p=> <-w=>

NOTE: 
  * If no switches are specified, the default class key list is used.
  * 64bit OSes must use the 64bit version of this application.

Switches For Class Filters:
  --all-classes         (-ac)
    install  : Adds libusb-win32 as an upper class filter for all
               classes in the USB enumerator. (Same as -dc in install mode)
    uninstall: Removes libusb-win32 as an upper class filter for all
               known classes.  This is a FULL class removal.
    list     : Displays all known classes.
    
  --device-classes      (-dc)
    install  : Adds libusb-win32 as an upper class filter for all
               classes in the USB enumerator.
    uninstall: Removes libusb-win32 as an upper class filter for all
               classes in the USB enumerator.
    list     : Displays all classes in the USB enumerator and the devices
               contained within them.
               
  --class=<nameOrGuid>  (-c=)
    install  : Adds libusb-win32 as an upper class filter for the
               specified class only.  Classes can be specified by name or
               guid.
    uninstall: Removes libusb-win32 as an upper class filter for the
               specified class only.  Classes can be specified by name or
               guid.
    list     : Displays information about the specified classes and the
               devices contained within them.

Switches For Device Filters:
  --device=<hwid>       (-d=)
    install  : Adds libusb-win32 as an upper device filter for the
               specified device.
    uninstall: Removes libusb-win32 as an upper device filter for the
               specified device.
    list     : <NA>
    
  --all-devices         (-ad)
  install
    install  : <NA>
    uninstall: Removes libusb-win32 device filters from all devices in the
               USB enumerator.
    list     : <NA>

Switches For INF Files:
 --inf=<your_file.inf> (-f=)
    install  : Installs usb device(s) from an inf file. 
    uninstall: Attempts to roll back a device driver installation. If 
               rollback fails or is unavailable, the device is removed and
               all root hubs are restarted.
    list     : <NA>

Common Switches:
 --prompt=<your_prompt_string> (-p=)
   Prompts the user with the specified string before running. To include
   spaces in the prompt string, place the entire switch in double quotes.
   Example: "-p=Are you sure?"
   
 --wait=<your_wait_string>     (-w=)
   After the operation completes, displays the specified string and waits for
   user input. To include spaces in the prompt string, place the entire
   switch in double quotes.
   Example: "-w=Press any key.."

Examples:
  install-filter install --device-classes
  install-filter uninstall --all-classes
  install-filter list --device-classes
  install-filter install --class={00000000-0000-0000-0000-000000000000}
  install-filter install "--device=USB\Vid_04d8&Pid_000c&Rev_0000"
  install-filter install --device=USB\Vid_04d8.Pid_000c.Rev_0000
  install-filter install --inf=your_file.inf

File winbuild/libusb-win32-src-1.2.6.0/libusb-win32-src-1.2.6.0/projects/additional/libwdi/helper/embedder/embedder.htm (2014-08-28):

Build Log

| | Rebuild started: Project: embedder, Configuration: Release|Win32

Command Lines

Build machine environment variables may not be correct.
Build machine environment variables may not be correct.
Build machine environment variables may not be correct.
Build machine environment variables may not be correct.
Build machine environment variables may not be correct.
Build machine environment variables may not be correct.
Build machine environment variables may not be correct.
Build machine environment variables may not be correct.
Build machine environment variables may not be correct.
Build machine environment variables may not be correct.
Build machine environment variables may not be correct.
Build machine environment variables may not be correct.
Build machine environment variables may not be correct.
Build machine environment variables may not be correct.
Creating temporary file "Z:\PROJECTS\libusb-win32-stage\projects\additional\libwdi\helper\embedder\RSP00001858209660.rsp" with contents
[
/O2 /Oi /GL /I "..\..\msvc" /D "_CRT_SECURE_NO_WARNINGS" /D "_UNICODE" /D "UNICODE" /FD /EHsc /MT /Gy /Fo"Z:\PROJECTS\libusb-win32-stage\projects\additional\libwdi\\\helper\embedder\\" /Fd"Z:\PROJECTS\libusb-win32-stage\projects\additional\libwdi\\\helper\embedder\vc90.pdb" /W3 /c /TC "..\embedder.c"
]
Creating command line "cl.exe @"Z:\PROJECTS\libusb-win32-stage\projects\additional\libwdi\helper\embedder\RSP00001858209660.rsp" /nologo /errorReport:prompt"
Build machine environment variables may not be correct.
Build machine environment variables may not be correct.
Creating temporary file "Z:\PROJECTS\libusb-win32-stage\projects\additional\libwdi\helper\embedder\RSP00001958209660.rsp" with contents
[
/OUT:"z:\PROJECTS\libusb-win32-stage\projects\additional\libwdi\libwdi\.msvc\\..\\embedder.exe" /MANIFEST /MANIFESTFILE:"Z:\PROJECTS\libusb-win32-stage\projects\additional\libwdi\\\helper\embedder\embedder.exe.intermediate.manifest" /MANIFESTUAC:"level='asInvoker' uiAccess='false'" /SUBSYSTEM:CONSOLE /OPT:REF /OPT:ICF /LTCG /DYNAMICBASE /NXCOMPAT /MACHINE:X86 kernel32.lib user32.lib gdi32.lib winspool.lib comdlg32.lib advapi32.lib shell32.lib ole32.lib oleaut32.lib uuid.lib odbc32.lib odbccp32.lib

"..\..\helper\embedder\embedder.obj"
]
Creating command line "link.exe @"Z:\PROJECTS\libusb-win32-stage\projects\additional\libwdi\helper\embedder\RSP00001958209660.rsp" /NOLOGO /ERRORREPORT:PROMPT"
Creating temporary file "Z:\PROJECTS\libusb-win32-stage\projects\additional\libwdi\helper\embedder\RSP00001A58209660.rsp" with contents
[
/outputresource:"..\embedder.exe;#1" /manifest

"..\..\helper\embedder\embedder.exe.intermediate.manifest"
]
Creating command line "mt.exe @"Z:\PROJECTS\libusb-win32-stage\projects\additional\libwdi\helper\embedder\RSP00001A58209660.rsp" /nologo"
Build machine environment variables may not be correct.
Build machine environment variables may not be correct.
Creating temporary file "Z:\PROJECTS\libusb-win32-stage\projects\additional\libwdi\helper\embedder\BAT00001B58209660.bat" with contents
[
@echo Manifest resource last updated at %TIME% on %DATE% > "..\..\helper\embedder\mt.dep"
]
Creating command line """Z:\PROJECTS\libusb-win32-stage\projects\additional\libwdi\helper\embedder\BAT00001B58209660.bat"""

Output Window

| | Compiling... embedder.c Linking... Generating code Finished generating code Embedding manifest... Project : warning PRJ0018 : The following environment variables were not found: $(Platform) $(Configuration)

Results

| | Build log was saved at "file://Z:\PROJECTS\libusb-win32-stage\projects\additional\libwdi\helper\embedder\embedder.htm" embedder - 0 error(s), 0 warning(s)

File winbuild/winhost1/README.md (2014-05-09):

# Building

The Makefile is very simplistic, but given the below dependencies it should
build on most modern linux systems, as of 2014. We have tested it on Fedora 20,
Debian and Mint.

## Prerequsit libraries
 - libusbX
 - Apache Thrift 
 - Boost

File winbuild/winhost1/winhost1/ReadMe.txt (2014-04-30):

========================================================================
    CONSOLE APPLICATION : winhost1 Project Overview
========================================================================

AppWizard has created this winhost1 application for you.

This file contains a summary of what you will find in each of the files that
make up your winhost1 application.

winhost1.vcxproj
    This is the main project file for VC++ projects generated using an Application Wizard.
    It contains information about the version of Visual C++ that generated the file, and
    information about the platforms, configurations, and project features selected with the
    Application Wizard.

winhost1.vcxproj.filters
    This is the filters file for VC++ projects generated using an Application Wizard. 
    It contains information about the association between the files in your project 
    and the filters. This association is used in the IDE to show grouping of files with
    similar extensions under a specific node (for e.g. ".cpp" files are associated with the
    "Source Files" filter).

winhost1.cpp
    This is the main application source file.

/////////////////////////////////////////////////////////////////////////////
Other standard files:

StdAfx.h, StdAfx.cpp
    These files are used to build a precompiled header (PCH) file
    named winhost1.pch and a precompiled types file named StdAfx.obj.

/////////////////////////////////////////////////////////////////////////////
Other notes:

AppWizard uses "TODO:" comments to indicate parts of the source code you
should add to or customize.

/////////////////////////////////////////////////////////////////////////////

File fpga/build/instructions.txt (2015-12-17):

s 0 0
h 400 400
w 1 0
w 2 0
w 3 1
w 4 8014
w 5 4004
w 1 0
w 2 0
w 3 1
w 4 8414
w 5 4004
w 1 0
w 2 0
w 3 1
w 4 8814
w 5 4004
w 1 0
w 2 0
w 3 1
w 4 8c14
w 5 4004
w 1 0
w 2 0
w 3 1
w 4 9014
w 5 4004
w 1 0
w 2 0
w 3 1
w 4 9414
w 5 4004
w 1 0
w 2 0
w 3 1
w 4 9814
w 5 4004
w 1 0
w 2 0
w 3 1
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
w 4 aaa0
w 5 4004
w 1 0
w 2 0
w 3 1
w 4 caa0
w 5 4004
w 1 0
w 2 0
w 3 1
w 4 8000
w 5 8000
w 1 0
w 2 0
w 3 1
w 4 a002
w 5 8000
w 7 beef
r d 0
w 7 beef
w 7 d00d
w 1 0
w 2 0
w 3 1
w 4 8000
w 5 8000
w 1 0
w 2 0
w 3 1
w 4 a002
w 5 8000
w 1 0
w 2 0
w 3 1
w 4 8014
w 5 4004
w 1 0
w 2 0
w 3 1
w 4 8414
w 5 4004
w 1 0
w 2 0
w 3 1
w 4 8814
w 5 4004
w 1 0
w 2 0
w 3 1
w 4 8c14
w 5 4004
w 1 0
w 2 0
w 3 1
w 4 9014
w 5 4004
w 1 0
w 2 0
w 3 1
w 4 9414
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
w 4 aaa0
w 5 4004
w 1 0
w 2 0
w 3 1
w 4 caa0
w 5 4004
w 7 beef
w 7 d00d
w 1 0
w 2 0
w 3 0
w 4 3
w 5 f205
w 1 0
w 2 0
w 3 0
w 4 1
w 5 f205
r b 0
w 7 beef
w 7 d00d
w 1 0
w 2 0
w 3 1
w 4 800
w 5 8000
w 1 0
w 2 0
w 3 1
w 4 1800
w 5 8000
w 1 0
w 2 0
w 3 1
w 4 2800
w 5 8000
w 1 0
w 2 0
w 3 1
w 4 3800
w 5 8000
w 1 0
w 2 0
w 3 1
w 4 4800
w 5 8000
w 1 0
w 2 0
w 3 1
w 4 5800
w 5 8000
w 1 0
w 2 0
w 3 1
w 4 6800
w 5 8000
w 1 0
w 2 0
w 3 1
w 4 7800
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
w 4 aaa0
w 5 4004
w 1 0
w 2 0
w 3 1
w 4 caa0
w 5 4004
w 7 beef
w 7 d00d
w 1 0
w 2 0
w 3 0
w 4 3
w 5 f205
w 1 0
w 2 0
w 3 0
w 4 1
w 5 f205
r b 0
w 1 0
w 2 0
w 3 0
w 4 0
w 5 f000
w 1 0
w 2 0
w 3 0
w 4 0
w 5 f001
w 1 0
w 2 0
w 3 0
w 4 0
w 5 f002
w 1 0
w 2 0
w 3 0
w 4 0
w 5 f003
w 1 0
w 2 0
w 3 0
w 4 0
w 5 f004
w 1 0
w 2 0
w 3 0
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
w 4 fc00
w 5 4204
w 1 0
w 2 0
w 3 1
w 4 8014
w 5 4204
w 1 0
w 2 0
w 3 0
w 4 43
w 5 f204
w 1 0
w 2 0
w 3 0
w 4 4
w 5 f206
w 1 0
w 2 0
w 3 0
w 4 177
w 5 430d
w 1 0
w 2 0
w 3 0
w 4 2711
w 5 4303
w 1 0
w 2 0
w 3 0
w 4 1
w 5 430c
w 1 0
w 2 0
w 3 1
w 4 fe00
w 5 4304
w 1 0
w 2 0
w 3 1
w 4 8014
w 5 4304
w 1 0
w 2 0
w 3 0
w 4 44
w 5 f204
w 1 0
w 2 0
w 3 0
w 4 5
w 5 f206
w 1 0
w 2 0
w 3 0
w 4 177
w 5 440d
w 1 0
w 2 0
w 3 0
w 4 2711
w 5 4403
w 1 0
w 2 0
w 3 0
w 4 1
w 5 440c
w 1 0
w 2 0
w 3 1
w 4 ff00
w 5 4404
w 1 0
w 2 0
w 3 1
w 4 8014
w 5 4404
w 1 0
w 2 0
w 3 0
w 4 45
w 5 f204
w 1 0
w 2 0
w 3 0
w 4 6
w 5 f206
w 1 0
w 2 0
w 3 0
w 4 177
w 5 450d
w 1 0
w 2 0
w 3 0
w 4 2711
w 5 4503
w 1 0
w 2 0
w 3 0
w 4 1
w 5 450c
w 1 0
w 2 0
w 3 1
w 4 ff80
w 5 4504
w 1 0
w 2 0
w 3 1
w 4 8014
w 5 4504
w 1 0
w 2 0
w 3 0
w 4 46
w 5 f204
w 1 0
w 2 0
w 3 0
w 4 7
w 5 f206
w 1 0
w 2 0
w 3 0
w 4 177
w 5 460d
w 1 0
w 2 0
w 3 0
w 4 2711
w 5 4603
w 1 0
w 2 0
w 3 0
w 4 1
w 5 460c
w 1 0
w 2 0
w 3 1
w 4 ffc0
w 5 4604
w 1 0
w 2 0
w 3 1
w 4 8014
w 5 4604
r b 0
r b 0
r d 0
w 1 0
w 2 1
w 3 1
w 4 de0
w 5 8000
r b 0
w 7 dead
h 10000 10000
r 6 201c
r 6 58d7
r 6 601b
r 6 801c
r 6 a01b
r 6 c01c
r 6 1c
r 6 6a14
r 6 8b56
r 6 abb5
r 6 c01c
r 6 1c
r 6 201c
r 6 58d7
r 6 cbcb
r 6 bd1
r 6 2bd3
r 6 58d7
r 6 6a14
r 6 8b56
r 6 abb5
r 6 58f0
r 6 6bd0
r 6 8bd2
r 6 abb5
r 6 cbcb
r 6 bd1
r b 218d
r 6 2bd3
r 6r b 23ec
 abd3
r 6 cbd2
r 6 bd1
r 6 2bd3
r 6 58f0
r 6 6bd0
r 6 8bd2
r 6 bd3
r 6 2bd3
r 6 589c
r 6 6bd0
r 6 8bd2
r 6 abd3
r 6 cbd2
r 6 6bd0
r 6 8bd3
r 6 abd2
r 6 cbd2
r 6 bd3
r 6 2bd3
r 6 589c
r 6 cbd3
r 6 bd2
r 6 2bd3
r 6 589c
r 6 6bd0
r 6 8bd3
r 6 abd2
r 6 5879
r 6 6bcf
r 6 8bd3
r 6 ar b 367a
b7a
r 6 cbr b 3679
d9
r 6 br b 3678
d78r 6 2bd3
r 6 8bd2
r 6 abd3
r 6 cbd3
r 6 bd2
r 6 2bd3
r 6 5879
r 6 6bcf
r 6 bd2
r 6 2bd4
r 6 586a
r 6 6bcf
r 6 8bd2
r 6 abd3
r 6 cbd3
r 6 6bd0
r 6 8bd2
r 6 abd2
r 6 cbd3
r 6 bd2
r 6 2bd4
r 6 586a
r 6 cbd3
r 6 bd2
r 6 2bd3
r 6 586a
r 6 6bd0
r 6 8bd2
r 6 abd2
r 6 2bd3
r 6r b 3659
 3659
r 6r b 3658
 3658
r 6 8br b 3657
d7
r 6 abd2
r 6 cbd3
r 6 bd2
r 6 8bd1
r 6 abd3
r 6 cbd2
r 6 bd2
r 6 2bd3
r 6 5865
r 6 6bd0
r 6 bd2
r 6 2bd2
r 6 5862
r 6 6bd0
r 6 8bd1
r 6 abd3
r 6 cbd2
r b 3646
r 6 6bd0
r 6 8bd1
r 6 abd2
r 6 cbd2
r 6 bd2
r 6 2bd2
r 6 5862
r 6 abd2
r 6 cbd1
r 6 bd3
r 6 2bd2
r 6 58r b 363a
6a
r 6 6bd0
r b 3639
rr b 3638
 b 3638
r 6 2bd3
r 6 5862
r 6 6bd0
r 6 8bd1
r 6 abd2
r 6 cbd1
r 6 bd3
r 6 8bd1
r 6 abd1
r 6 cbd3
r 6 bd3
r 6 2bd3
r 6 5862
r 6 6bd0
r 6 bd2
r 6 2bd3
r 6 5861
r 6 6bd0
r 6 8bd1
r 6 abd1
r 6 cbd3
r 6 5861
r 6 6bd0
r 6 8bd2
r 6 abd3
r 6 cbd3
r 6 bd2
r 6 2bd3
r 6 abd3
r r b 361a
6 36r b 361a
1a
r 6 r b 3619
b619r 6 2bd3
r 6 5861
r 6 6bd0
r 6 8bd2
r 6 2bd4
r 6 585f
r 6 6bd0
r 6 8bd2
r 6 abd3
r 6 cbd2
r 6 bd3
r 6 8bd2
r 6 abd3
r 6 cbd3
r 6 bd3
r 6 2bd4
r 6 585f
r 6 6bd0
r 6 cbd3
r 6 bd3
r 6 2bd3
r 6 5860
r 6 6bd0
r 6 8bd2
r 6 abd3
r 6 5860
r 6 6bd1
r 6 8bd0
r 6 abd3
r 6 cbd3
r 6 r b 35fa
bd3r b 35fa

r 6 2r b 35f9
bf9
r 6 abd4
r 6 cbd2
r 6 bd2
r 6 2bd3
r 6 5860
r 6 6bd1
r 6 8bd0
r 6 2bd3
r 6 5861
r 6 6bd0
r 6 8bd0
r 6 abd4
r 6 cbd2
r 6 bd2
r 6 6bd0
r 6 8bd2
r 6 abd2
r 6 cbd2
r 6 bd2
r 6 2bd3
r 6 5861
r 6 cbd2
r 6 bd3
r 6 2bd3
r 6 5861
r 6 6bd0
r 6 8bd2
r 6 abd2
r 6 5861
r 6r b 35db
 35r b 35db
db
r 6 8br b 35da
da
r 6 abd2
r 6 cbd2
r 6 bd3
r 6 2bd3
r 6 abd3
r 6 cbd3
r 6 bd3
r 6 2bd3
r 6 5861
r 6 6bd1
r 6 8bd1
r 6 bd3
r 6 2bd4
r 6 5860
r 6 6bcf
r 6 8bd1
r 6 abd3
r 6 cbd3
r 6 6bcf
r 6 8bd4
r 6 abd3
r 6 cbd1
r 6 bd3
r 6 2bd4
r 6 5860
r 6 cbd1
r 6 bd3
r 6 2bd3
r 6 5860
r 6 6bcr b 35bc
f
r 6 8bd4
r 6 abd3r b 35ba
rr 6 5860
r 6r b 35b8
 6bd0
r 6 8bd2
r 6 abd3
r 6 cbd1
r 6 bd3
r 6 2bd3
r 6 8bd2
r 6 abd1
r 6 cbd2
r 6 bd3
r 6 2bd3
r 6 5860
r 6 6bd0
r 6 bd3
r 6 2bd2
r 6 5861
r 6 6bd0
r 6 8bd2
r 6 abd1
r 6 cbd2
r 6 6bd0
r 6 8bd1
r 6 abd3
r 6 cbd2
r 6 bd3
r 6 2bd2
r 6 5861
r 6 cbd2
r 6 bd2
r 6 2bd4
r 6 5861
r 6 6bd0
r 6r b 3598
 3598
r 6r b 3597
 3597
r 6 2r b 3596
b96
r 6 5860
r 6 6bd0
r 6 8bd2
r 6 abd3
r 6 cbd2
r 6 bd2
r 6 8bd2
r 6 abd3
r 6 cbd2
r 6 bd4
r 6 2bd4
r 6 5860
r 6 6bd0
r 6 bd4
r 6 2bd2
r 6 5860
r 6 6bd0
r 6 8bd2
r 6 abd3
r 6 cbd2
r 6 6bd0
r 6 8bd2
r 6 abd2
r 6 cbd2
r 6 bd4
r 6 2bd2
r 6 5860
r 6 abd2
r 6 cbd1
r 6 bd3r b 3578

r 6 2bd3
r b 3576
r 6 5r b 3576
876
r 6 6bd0
r 6 8bd2
r 6 2bd3
r 6 5863
r 6 6bce
r 6 8bd2
r 6 abd2
r 6 cbd1
r 6 bd3
r 6 8bd2
r 6 abd2
r 6 cbd3
r 6 bd3
r 6 2bd3
r 6 5863
r 6 6bce
r 6 bd3
r 6 2bd3
r 6 5860
r 6 6bd0
r 6 8bd2
r 6 abd2
r 6 cbd3
r 6 5860
r 6 6bd0
r 6 8bd3
r 6 abd1
r 6 cbd3
r 6 bd3
r 6 2bd3
rr b 3557
 b 3557
r 6 r b 3556
c556
r 6r b 3555
rbd3
r 6 2bd3
r 6 5860
r 6 6bd0
r 6 8bd3
r 6 2bd3
r 6 5860
r 6 6bd1
r 6 8bd1
r 6 abd1
r 6 cbd4
r 6 bd3
r 6 8bd1
r 6 abd3
r 6 cbd3
r 6 bd3
r 6 2bd3
r 6 5860
r 6 6bd1
r 6 cbd3
r 6 bd3
r 6 2bd5
r 6 5861
r 6 6bd1
r 6 8bd1
r 6 abd3
r 6 5861
r 6 6bd0
r 6 8bd3
r 6 abd3
r 6 cbd3
r 6r b 3536
 3536r r b 3535
6 2bd5r b 3535

r 6 abd3
r 6 cbd3
r 6 bd3
r 6 2bd3
r 6 5861
r 6 6bd0
r 6 8bd3
r 6 2bd3
r 6 5860
r 6 6bd0
r 6 8bd1
r 6 abd3
r 6 cbd3
r 6 bd3
r 6 6bd0
r 6 8bd1
r 6 abd1
r 6 cbd3
r 6 bd3
r 6 2bd3
r 6 5860
r 6 cbd3
r 6 bd3
r 6 2bd3
r 6 5861
r 6 6bd0
r 6 8bd1
r 6 abd1
r 6 5861
r 6 6bd1
r 6r b 3516
 8bd2
r 6r b 3515
 3515
r b 3515
r 6 cbd3
r 6 bd3
r 6 2bd3
r 6 abd3
r 6 cbd1
r 6 bd3
r 6 2bd3
r 6 5861
r 6 6bd1
r 6 8bd2
r 6 bd3
r 6 2bd3
r 6 5860
r 6 6bd0
r 6 8bd2
r 6 abd3
r 6 cbd1
r 6 6bd0
r 6 8bd2
r 6 abd3
r 6 cbd1
r 6 bd3
r 6 2bd3
r 6 5860
r 6 cbd1
r 6 bd3
r 6 2bd2
r 6 5861
r 6 6bd0
r 6 8bd2
r 6 r b 34f6
a4f6
r 6 r b 34f5
54f5
r b 34f4
r 6 6bd0
r 6 8bd2
r 6 abd3
r 6 cbd1
r 6 bd3
r 6 2bd2
r 6 8bd2
r 6 abd3
r 6 cbd1
r 6 bd2
r 6 2bd2
r 6 5861
r 6 6bd0
r 6 bd2
r 6 2bd2
r 6 5861
r 6 6bcf
r 6 8bd3
r 6 abd3
r 6 cbd1
r 6 6bcf
r 6 8bd3
r 6 abd3
r 6 cbd3
r 6 bd2
r 6 2bd2
r 6 5861
r 6 cbd3
r 6 bd3
r 6 2bd2
r 6 586r b 34d6
0
r 6 6bcr b 34d5
f
r 6 8r b 34d4
bd4
r 6 abd3
r 6 2bd2
r 6 5860
r 6 6bd0
r 6 8bd2
r 6 abd2
r 6 cbd3
r 6 bd3
r 6 8bd2
r 6 abd2
r 6 cbd4
r 6 bd2
r 6 2bd3
r 6 5860
r 6 6bd0
r 6 bd2
r 6 2bd3
r 6 5861
r 6 6bd0
r 6 8bd2
r 6 abd2
r 6 cbd4
r 6 6bd0
r 6 8bd1
r 6 abd3
r 6 cbd1
r 6 bd2
r 6 2bd3
r 6 5861
r 6 r b 34b6
a4b6
r r b 34b5
r cbd1r b 34b5

r 6 bd2
r 6 2bd3
r 6 5860
r 6 6bd0
r 6 8bd1
r 6 2bd3
r 6 5860
r 6 6bcf
r 6 8bd2
r 6 abd1
r 6 cbd1
r 6 bd2
r 6 8bd2
r 6 abd1
r 6 cbd2
r 6 bd4
r 6 2bd2
r 6 5860
r 6 6bcf
r 6 bd4
r 6 2bd2
r 6 5860
r 6 6bd0
r 6 8bd2
r 6 abd1
r 6 cbd2
r 6 5860
r 6 6bd0
r 6 8bd1
r 6 abd3
r b 3497
r 6 cr b 3496
b96
r 6r b 3495
 bd4
r 6 2bd2
r 6 abd3
r 6 cbd3
r 6 bd2
r 6 2bd2
r 6 5861
r 6 6bd0
r 6 8bd1
r 6 2bd2
r 6 5861
r 6 6bd0
r 6 8bd2
r 6 abd3
r 6 cbd3
r 6 bd2
r 6 8bd2
r 6 abd3
r 6 cbd2
r 6 bd2
r 6 2bd2
r 6 5861
r 6 6bd0
r 6 cbd2
r 6 bd2
r 6 2bd3
r 6 5860
r 6 6bd0
r 6 8bd2
r 6 abd3
r 6 5860
r 6 r b 3476
6476
r 6 r b 3475
8475
r r b 3474
b 3474
r 6 cbd2
r 6 bd2
r 6 2bd3
r 6 abd2
r 6 cbd2
r 6 bd3
r 6 2bd3
r 6 5861
r 6 6bd0
r 6 8bd3
r 6 2bd3
r 6 5861
r 6 6bcf
r 6 8bd1
r 6 abd2
r 6 cbd2
r 6 bd3
r 6 6bcf
r 6 8bd1
r 6 abd2
r 6 cbd4
r 6 bd1
r 6 2bd3
r 6 5861
r 6 cbd4
r 6 bd1
r 6 2bd3
r 6 5861
r 6 6bd0
r 6 8bd1
r b 3455
r 6 abr b 3455
d5
r 6 5r b 3454
854
r 6 6bd0
r 6 8bd2
r 6 abd2
r 6 cbd2
r 6 bd1
r 6 2bd3
r 6 abd2
r 6 cbd2
r 6 bd2
r 6 2bd4
r 6 5860
r 6 6bd0
r 6 8bd2
r 6 bd2
r 6 2bd4
r 6 5860
r 6 6bd1
r 6 8bd2
r 6 abd2
r 6 cbd2
r 6 6bd1
r 6 8bd2
r 6 abd2
r 6 cbd3
r 6 bd2
r 6 2bd4
r 6 5860
r 6 cbd3
r 6 bd2
r 6 2bd3
r 6 5860
r b 3434
r 6 6bd1
rr b 3433
 b 3433
r r b 3432
6 abd2
r 6 5860
r 6 6bd1
r 6 8bd1
r 6 abd4
r 6 cbd2
r 6 bd2
r 6 2bd3
r 6 8bd1
r 6 abd4
r 6 cbd2
r 6 bd3
r 6 2bd3
r 6 5860
r 6 6bd1
r 6 bd3
r 6 2bd3
r 6 5860
r 6 6bcf
r 6 8bd2
r 6 abd4
r 6 cbd2
r 6 6bcf
r 6 8bd2
r 6 abd4
r 6 cbd2
r 6 bd4
r 6 2bd3
r 6 5860
r 6 cbd2
r 6 bd4
r 6 r b 3413
2bd3
r 6 r b 3412
5412
r 6 6r b 3411
b11
r 6 8bd2
r 6 abd4
r 6 2bd3
r 6 5860
r 6 6bd0
r 6 8bd3
r 6 abd3
r 6 cbd2
r 6 bd4
r 6 8bd3
r 6 abd3
r 6 cbd2
r 6 bd4
r 6 2bd1
r 6 5860
r 6 6bd0
r 6 bd4
r 6 2bd1
r 6 5861
r 6 6bcf
r 6 8bd2
r 6 abd3
r 6 cbd2
r 6 6bcf
r 6 8bd2
r 6 abd3
r 6 cbd2
r 6 bd3
r 6 2bd1
r 6 5861
r 6 abd3
r b 33f2
r 6 cbd2r b 33f1

r 6 bdr b 33f0
30r 6 2bd4
r 6 5862
r 6 6bce
r 6 8bd2
r 6 2bd4
r 6 5862
r 6 6bce
r 6 8bd3
r 6 abd3
r 6 cbd3
r 6 bd3
r 6 8bd3
r 6 abd3
r 6 cbd3
r 6 bd3
r 6 2bd3
r 6 5862
r 6 6bce
r 6 bd3
r 6 2bd3
r 6 5860
r 6 6bd0
r 6 8bd3
r 6 abd3
r 6 cbd3
r 6 5860
r 6 6bd0
r 6 8bd3
r 6 abd2
r 6 cbd3
r 6 bd3
r b 33d1
r 6 2br b 33d0
d0
r 6 ar b 33cf
bcf
r 6 cbd3
r 6 bd3
r 6 2bd3
r 6 5861
r 6 6bd0
r 6 8bd3
r 6 2bd3
r 6 5861
r 6 6bd0
r 6 8bd3
r 6 abd3
r 6 cbd3
r 6 bd3
r 6 8bd3
r 6 abd3
r 6 cbd3
r 6 bd2
r 6 2bd4
r 6 5861
r 6 6bd0
r 6 cbd3
r 6 bd2
r 6 2bd4
r 6 5860
r 6 6bd0
r 6 8bd1
r 6 abd3
r 6 5860
r 6 6bd0
r 6 8bdr b 33b1
1
r 6 abd2
r b 33af
r 6 cbd2r b 33af

r 6 bd3
r 6 2bd4
r 6 abd2
r 6 cbd2
r 6 bd3
r 6 2bd3
r 6 5860
r 6 6bd0
r 6 8bd1
r 6 2bd3
r 6 5860
r 6 6bd0
r 6 8bd2
r 6 abd3
r 6 cbd2
r 6 bd3
r 6 6bd0
r 6 8bd2
r 6 abd3
r 6 cbd3
r 6 bd2
r 6 2bd3
r 6 5860
r 6 cbd3
r 6 bd2
r 6 2bd3
r 6 5861
r 6 6bcf
r 6 8bd1
r 6 abd3
r 6 5861r b 3390

r 6 6bcf
r 6r b 338e
 338e
r 6 r b 338d
abd3
r 6 cbd1
r 6 bd2
r 6 2bd3
r 6 abd3
r 6 cbd1
r 6 bd2
r 6 2bd4
r 6 5860
r 6 6bcf
r 6 8bd1
r 6 bd2
r 6 2bd4
r 6 5860
r 6 6bd1
r 6 8bd1
r 6 abd3
r 6 cbd1
r 6 6bd1
r 6 8bd1
r 6 abd3
r 6 cbd2
r 6 bd3
r 6 2bd2
r 6 5860
r 6 cbd2
r 6 bd3
r 6 2bd2
r 6 5861
r 6 6bcf
r 6 8bd2
r 6 abd3r b 336e

r 6 58r b 336d
6d
r 6 6r b 336c
b6c
r 6 8bd2
r 6 abd3
r 6 cbd3
r 6 bd2
r 6 2bd2
r 6 8bd2
r 6 abd3
r 6 cbd3
r 6 bd2
r 6 2bd2
r 6 5861
r 6 6bcf
r 6 bd2
r 6 2bd2
r 6 5861
r 6 6bd0
r 6 8bd2
r 6 abd2
r 6 cbd3
r 6 6bd0
r 6 8bd2
r 6 abd2
r 6 cbd2
r 6 bd2
r 6 2bd3
r 6 5861
r 6 cbd2
r 6 bd2
r 6 2bd3
r 6 5860
r 6r b 334d
 6bd0
r 6r b 334c
 334c
r b 334b
r 6 abd2
r 6 2bd3
r 6 5860
r 6 6bd0
r 6 8bd2
r 6 abd1
r 6 cbd3
r 6 bd2
r 6 8bd2
r 6 abd1
r 6 cbd3
r 6 bd2
r 6 2bd4
r 6 5860
r 6 6bd0
r 6 bd2
r 6 2bd4
r 6 5860
r 6 6bd0
r 6 8bd2
r 6 abd3
r 6 cbd3
r 6 6bd0
r 6 8bd2
r 6 abd3
r 6 cbd3
r 6 bd3
r 6 2bd4
r 6 5860
r 6 abd3
r 6r b 332d
 cbd3
r 6 br b 332c
d2cr 6 2bd4r b 332b

r 6 5860
r 6 6bcf
r 6 8bd3
r 6 2bd4
r 6 5860
r 6 6bcf
r 6 8bd3
r 6 abd3
r 6 cbd2
r 6 bd3
r 6 8bd3
r 6 abd3
r 6 cbd2
r 6 bd2
r 6 2bd3
r 6 5860
r 6 6bcf
r 6 bd2
r 6 2bd3
r 6 5860
r 6 6bd1
r 6 8bd3
r 6 abd2
r 6 cbd2
r 6 5860
r 6 6bd1
r 6 8bd3
r 6 abd2
r 6 cbd2
r 6 bd2
r 6r b 330c
 2bd1
r 6 abd2r b 330b
rr 6 cr b 330a
b0a
r 6 bd2
r 6 2bd1
r 6 5860
r 6 6bd0
r 6 8bd3
r 6 2bd1
r 6 5860
r 6 6bd0
r 6 8bd1
r 6 abd1
r 6 cbd3
r 6 bd2
r 6 8bd1
r 6 abd1
r 6 cbd3
r 6 bd2
r 6 2bd3
r 6 5861
r 6 6bd0
r 6 cbd3
r 6 bd2
r 6 2bd3
r 6 5861
r 6 6bcf
r 6 8bd2
r 6 abd4
r 6 5861
r 6 6bcf
r 6 8bd2
r 6 abdr b 32ec
4
r 6 r b 32eb
c2eb
r 6 bd4r b 32ea

r 6 2bd3
r 6 abd4
r 6 cbd3
r 6 bd4
r 6 2bd3
r 6 5860
r 6 6bd1
r 6 8bd2
r 6 2bd3
r 6 5860
r 6 6bd1
r 6 8bd2
r 6 abd3
r 6 cbd2
r 6 bd4
r 6 6bd1
r 6 8bd2
r 6 abd3
r 6 cbd2
r 6 bd3
r 6 2bd3
r 6 5860
r 6 cbd2
r 6 bd3
r 6 2bd3
r 6 5860
r 6 6bd0
r 6 8bd1
r 6 abd3
r 6 586r b 32cc
0
r 6 6bdr b 32cb
0
r 6 8bdr b 32ca
1
r 6 abd3
r 6 cbd3
r 6 bd3
r 6 2bd3
r 6 abd3
r 6 cbd3
r 6 bd3
r 6 2bd2
r 6 5862
r 6 6bcf
r 6 8bd1
r 6 bd3
r 6 2bd2
r 6 5862
r 6 6bcf
r 6 8bd1
r 6 abd3
r 6 cbd1
r 6 6bcf
r 6 8bd1
r 6 abd3
r 6 cbd1
r 6 bd2
r 6 2bd2
r 6 5860
r 6 cbd1
r 6 bd2
r 6 2bd2
r 6 5860
r 6 6bd0
r 6r b 32ab
 32ab
r 6 r b 32aa
a2aa
r 6r b 32a9
 32a9
r 6 6bd0
r 6 8bd3
r 6 abd1
r 6 cbd3
r 6 bd3
r 6 2bd2
r 6 8bd3
r 6 abd1
r 6 cbd3
r 6 bd3
r 6 2bd2
r 6 5861
r 6 6bd0
r 6 bd3
r 6 2bd2
r 6 5861
r 6 6bd0
r 6 8bd2
r 6 abd3
r 6 cbd3
r 6 6bd0
r 6 8bd2
r 6 abd3
r 6 cbd3
r 6 bd3
r 6 2bd3
r 6 5861
r 6 cbd3
r 6 bd3
r 6 2bd3
r r b 328a
6 328a
r r b 3289
r 6bd0r b 3289

r 6 8bd2
r 6 abd3
r 6 2bd3
r 6 5861
r 6 6bd0
r 6 8bd2
r 6 abd2
r 6 cbd3
r 6 bd3
r 6 8bd2
r 6 abd2
r 6 cbd3
r 6 bd3
r 6 2bd3
r 6 5860
r 6 6bd0
r 6 bd3
r 6 2bd3
r 6 5860
r 6 6bd0
r 6 8bd2
r 6 abd2
r 6 cbd2
r 6 6bd0
r 6 8bd2
r 6 abd2
r 6 cbd2
r 6 bd2
r 6 2bd4
r 6 585e
r b 326a
r 6 abd2
r b 3269
r 6 cbd2
r b 3268
r 6 bd2
r 6 2bd4
r 6 585e
r 6 6bd1
r 6 8bd1
r 6 2bd4
r 6 585e
r 6 6bd1
r 6 8bd1
r 6 abd3
r 6 cbd3
r 6 bd3
r 6 8bd1
r 6 abd3
r 6 cbd3
r 6 bd3
r 6 2bd2
r 6 5861
r 6 6bd0
r 6 bd3
r 6 2bd2
r 6 5861
r 6 6bd0
r 6 8bd1
r 6 abd4
r 6 cbd1
r 6 5861
r 6 6bd0
r 6 8bd1
r 6 abd4
r 6 cr b 324a
b4a
r 6 br b 3249
d49r 6 2r b 3248
b48
r 6 abd4
r 6 cbd1
r 6 bd3
r 6 2bd3
r 6 5861
r 6 6bd1
r 6 8bd2
r 6 2bd3
r 6 5861
r 6 6bd1
r 6 8bd2
r 6 abd2
r 6 cbd1
r 6 bd3
r 6 8bd2
r 6 abd2
r 6 cbd1
r 6 bd3
r 6 2bd2
r 6 5860
r 6 6bd0
r 6 cbd3
r 6 bd3
r 6 2bd2
r 6 5860
r 6 6bd0
r 6 8bd2
r 6 abd2
r 6 5860
r 6 6bd0
r 6r b 3229
 3229
r 6 r b 3228
a228
r r b 3227
6 3227
r 6 bd3
r 6 2bd2
r 6 abd2
r 6 cbd3
r 6 bd3
r 6 2bd2
r 6 5861
r 6 6bd0
r 6 8bd2
r 6 2bd2
r 6 5861
r 6 6bd0
r 6 8bd2
r 6 abd3
r 6 cbd2
r 6 bd3
r 6 6bcf
r 6 8bd2
r 6 abd3
r 6 cbd2
r 6 bd3
r 6 2bd3
r 6 5861
r 6 cbd2
r 6 bd3
r 6 2bd3
r 6 5861
r 6 6bcf
r 6 8bd3
r 6 r b 3209
a209
r 6 586r b 3208
1
r 6 6bcf
r b 3206
r 6 8bd3
r 6 abd3
r 6 cbd2
r 6 bd3
r 6 2bd3
r 6 abd3
r 6 cbd2
r 6 bd3
r 6 2bd3
r 6 5861
r 6 6bd0
r 6 8bd3
r 6 bd1
r 6 2bd3
r 6 5861
r 6 6bd0
r 6 8bd3
r 6 abd1
r 6 cbd3
r 6 6bcf
r 6 8bd3
r 6 abd1
r 6 cbd3
r 6 bd1
r 6 2bd2
r 6 5861
r 6 cbd3
r 6 bd1
r 6 2bd2
r 6 5861
r 6 6bcfr b 31e8

r 6 8bdr b 31e7
2
r 6 abdr b 31e6
2
r 6 5861
r 6 6bcf
r 6 8bd2
r 6 abd2
r 6 cbd3
r 6 bd1
r 6 2bd2
r 6 8bd2
r 6 abd2
r 6 cbd3
r 6 bd1
r 6 2bd2
r 6 5860
r 6 6bd0
r 6 bd3
r 6 2bd2
r 6 5860
r 6 6bd0
r 6 8bd2
r 6 abd3
r 6 cbd2
r 6 6bd0
r 6 8bd2
r 6 abd3
r 6 cbd2
r 6 bd3
r 6 2bd3
r 6 5860
r 6 cbd2
r 6 bd3
r 6 r b 31c7
21c7
r 6 r b 31c6
51c6
r 6 6bd0r b 31c5
rr 6 8bd1
r 6 abd3
r 6 2bd3
r 6 5860
r 6 6bd0
r 6 8bd1
r 6 abd3
r 6 cbd2
r 6 bd3
r 6 8bd2
r 6 abd3
r 6 cbd2
r 6 bd3
r 6 2bd3
r 6 5861
r 6 6bd1
r 6 bd3
r 6 2bd3
r 6 5861
r 6 6bd1
r 6 8bd2
r 6 abd3
r 6 cbd2
r 6 6bd1
r 6 8bd2
r 6 abd3
r 6 cbd2
r 6 bd3
r 6 2bd3
r 6 5860
r 6 abr b 31a6
d6
r 6r b 31a5
 cbd2
r 6 br b 31a4
da4r 6 2bd3
r 6 5860
r 6 6bd0
r 6 8bd3
r 6 2bd3
r 6 5860
r 6 6bd0
r 6 8bd3
r 6 abd4
r 6 cbd1
r 6 bd4
r 6 8bd2
r 6 abd4
r 6 cbd1
r 6 bd4
r 6 2bd3
r 6 5860
r 6 6bd0
r 6 bd4
r 6 2bd3
r 6 5860
r 6 6bd0
r 6 8bd2
r 6 abd3
r 6 cbd2
r 6 5860
r 6 6bd0
r 6 8bd2
r 6 abd3
r 6 cbdr b 3186
2
r r b 3185
r bd4
r 6r b 3184
 2bd2
r 6 abd3
r 6 cbd2
r 6 bd4
r 6 2bd2
r 6 5860
r 6 6bd0
r 6 8bd3
r 6 2bd3
r 6 5860
r 6 6bd0
r 6 8bd3
r 6 abd3
r 6 cbd3
r 6 bd2
r 6 8bd2
r 6 abd3
r 6 cbd3
r 6 bd2
r 6 2bd3
r 6 5860
r 6 6bd0
r 6 cbd1
r 6 bd2
r 6 2bd3
r 6 5860
r 6 6bd0
r 6 8bd2
r 6 abd3
r 6 5861
r 6r b 3166
 316r b 3166
6
r 6 8r b 3165
b65
r 6 abd3
r 6 cbd1
r 6 bd2
r 6 2bd3
r 6 abd2
r 6 cbd1
r 6 bd2
r 6 2bd3
r 6 5861
r 6 6bd0
r 6 8bd2
r 6 2bd3
r 6 5861
r 6 6bd0
r 6 8bd2
r 6 abd2
r 6 cbd3
r 6 bd3
r 6 6bd1
r 6 8bd2
r 6 abd2
r 6 cbd3
r 6 bd3
r 6 2bd3
r 6 5861
r 6 cbd2
r 6 bd3
r 6 2bd3
r 6 5861
r 6 6bd1r b 3147

r 6 r b 3146
8bd2
r 6r b 3145
 abd2
r 6 5860
r 6 6bd1
r 6 8bd2
r 6 abd2
r 6 cbd2
r 6 bd3
r 6 2bd2
r 6 abd3
r 6 cbd2
r 6 bd3
r 6 2bd2
r 6 5860
r 6 6bd0
r 6 8bd2
r 6 bd3
r 6 2bd2
r 6 5860
r 6 6bd0
r 6 8bd2
r 6 abd3
r 6 cbd2
r 6 6bcf
r 6 8bd2
r 6 abd3
r 6 cbd2
r 6 bd3
r 6 2bd2
r 6 5861
r 6 cbd2
r r b 3127
b 312r b 3127
7r 6 2br b 3126
d6
r 6 5861
r 6 6bcf
r 6 8bd3
r 6 abd3
r 6 5860
r 6 6bcf
r 6 8bd3
r 6 abd3
r 6 cbd2
r 6 bd3
r 6 2bd3
r 6 8bd3
r 6 abd2
r 6 cbd2
r 6 bd3
r 6 2bd3
r 6 5860
r 6 6bd0
r 6 bd2
r 6 2bd3
r 6 5860
r 6 6bd0
r 6 8bd3
r 6 abd2
r 6 cbd3
r 6 6bd0
r 6 8bd3
r 6 abd2
r 6 cbd3
r 6 bd2r b 3108

r b 3107
r b 3107
r 6 5860r b 3106

r 6 cbd3
r 6 bd2
r 6 2bd3
r 6 5860
r 6 6bd0
r 6 8bd2
r 6 abd2
r 6 2bd3
r 6 5860
r 6 6bd0
r 6 8bd2
r 6 abd2
r 6 cbd3
r 6 bd2
r 6 8bd2
r 6 abd3
r 6 cbd3
r 6 bd2
r 6 2bd3
r 6 5860
r 6 6bcf
r 6 bd1
r 6 2bd3
r 6 5860
r 6 6bcf
r 6 8bd2
r 6 abd3
r 6 cbd2
r 6 6bd0
r 6 8bd2
r b 30e7
r 6 r b 30e7
abd3
r 6r b 30e6
 30e6
r 6 bd1
r 6 2bd4
r 6 5861
r 6 abd2
r 6 cbd3
r 6 bd1
r 6 2bd4
r 6 5861
r 6 6bd0
r 6 8bd3
r 6 2bd4
r 6 585f
r 6 6bd0
r 6 8bd3
r 6 abd2
r 6 cbd3
r 6 bd3
r 6 8bd2
r 6 abd2
r 6 cbd3
r 6 bd3
r 6 2bd4
r 6 585f
r 6 6bd1
r 6 bd2
r 6 2bd4
r 6 585f
r 6 6bd1
r 6 8bd2
r 6 ar b 30c8
bc8
r 6 cr b 30c7
bc7
r 6r b 30c6
 30c6
r 6 6bd1
r 6 8bd2
r 6 abd3
r 6 cbd3
r 6 bd2
r 6 2bd3
r 6 abd4
r 6 cbd2
r 6 bd2
r 6 2bd3
r 6 5860
r 6 6bd1
r 6 8bd0
r 6 2bd3
r 6 5860
r 6 6bd1
r 6 8bd0
r 6 abd4
r 6 cbd2
r 6 bd3
r 6 8bd1
r 6 abd4
r 6 cbd2
r 6 bd3
r 6 2bd3
r 6 5860
r 6 6bd0
r 6 cbd1
r 6 bd3
r 6 r b 30a8
20a8
r 6 5r b 30a7
8a7
r 6 r b 30a6
60a6
r 6 8bd1
r 6 abd3
r 6 5861
r 6 6bd1
r 6 8bd1
r 6 abd3
r 6 cbd1
r 6 bd3
r 6 2bd2
r 6 abd4
r 6 cbd2
r 6 bd3
r 6 2bd2
r 6 5861
r 6 6bd1
r 6 8bd2
r 6 2bd1
r 6 5861
r 6 6bd1
r 6 8bd2
r 6 abd4
r 6 cbd2
r 6 bd4
r 6 6bd0
r 6 8bd1
r 6 abd4
r 6 cbd2
r 6 bd4
r 6 2bd1
r 6 5860
r 6r b 3087
 3087
r b 3086
r b r b 3086
3086r 6 2bd1
r 6 5860
r 6 6bd0
r 6 8bd1
r 6 abd3
r 6 5861
r 6 6bcf
r 6 8bd1
r 6 abd3
r 6 cbd2
r 6 bd3
r 6 2bd2
r 6 abd4
r 6 cbd1
r 6 bd3
r 6 2bd2
r 6 5861
r 6 6bcf
r 6 8bd2
r 6 bd2
r 6 2bd3
r 6 5861
r 6 6bcf
r 6 8bd2
r 6 abd4
r 6 cbd1
r 6 6bcf
r 6 8bd2
r 6 abd4
r 6 cbr b 3068
d8
r 6 bdr b 3067
27r 6 2r b 3066
b66
r 6 5860
r 6 cbd3
r 6 bd3
r 6 2bd3
r 6 5860
r 6 6bcf
r 6 8bd2
r 6 abd3
r 6 5860
r 6 6bd0
r 6 8bd2
r 6 abd3
r 6 cbd3
r 6 bd3
r 6 2bd3
r 6 8bd1
r 6 abd2
r 6 cbd3
r 6 bd3
r 6 2bd3
r 6 5860
r 6 6bd0
r 6 bd3
r 6 2bd1
r 6 5860
r 6 6bd0
r 6 8bd1
r 6 abd2
r 6 cbd2
r 6 6br b 3048
d8
r b 3047
r 6 8bd1r b 3047

r 6 abd2
r 6 cbd2
r 6 bd3
r 6 2bd1
r 6 5860
r 6 cbd1
r 6 bd3
r 6 2bd1
r 6 5860
r 6 6bd0
r 6 8bd1
r 6 abd2
r 6 2bd2
r 6 5861
r 6 6bd0
r 6 8bd1
r 6 abd2
r 6 cbd1
r 6 bd3
r 6 8bd2
r 6 abd3
r 6 cbd1
r 6 bd3
r 6 2bd2
r 6 5861
r 6 6bd0
r 6 bd4
r 6 2bd2
r 6 5861
r 6 6bd0
r 6r b 3028
 3028
r 6r b 3027
 3027
r r b 3026
r cbd2
r 6 6bd0
r 6 8bd3
r 6 abd3
r 6 cbd2
r 6 bd4
r 6 2bd2
r 6 5861
r 6 abd2
r 6 cbd3
r 6 bd3
r 6 2bd2
r 6 5861
r 6 6bd0
r 6 8bd3
r 6 2bd3
r 6 5861
r 6 6bd0
r 6 8bd3
r 6 abd2
r 6 cbd3
r 6 bd3
r 6 8bd3
r 6 abd1
r 6 cbd3
r 6 bd3
r 6 2bd3
r 6 5861
r 6 6bd0
r 6 bd2
r 6 r b 3008
2008r b 3008

r 6 586r b 3007
1
r 6 6bd0
r 6 8bd3
r 6 abd1
r 6 cbd3
r 6 5861
r 6 6bd1
r 6 8bd2
r 6 abd1
r 6 cbd3
r 6 bd2
r 6 2bd2
r 6 abd4
r 6 cbd4
r 6 bd1
r 6 2bd2
r 6 5861
r 6 6bd1
r 6 8bd2
r 6 2bd4
r 6 5860
r 6 6bd1
r 6 8bd2
r 6 abd4
r 6 cbd4
r 6 bd1
r 6 8bd3
r 6 abd1
r 6 cbd4
r 6 bd1
r 6 2bd4
r 6 5r b 2fe8
8e8r b 2fe8

r 6 6bcr b 2fe7
f
r 6 cbd2
r 6 bd3
r 6 2bd3
r 6 5860
r 6 6bcf
r 6 8bd3
r 6 abd1
r 6 5860
r 6 6bd0
r 6 8bd3
r 6 abd1
r 6 cbd2
r 6 bd3
r 6 2bd3
r 6 abd2
r 6 cbd2
r 6 bd3
r 6 2bd3
r 6 5860
r 6 6bd0
r 6 8bd3
r 6 2bd3
r 6 5860
r 6 6bd0
r 6 8bd3
r 6 abd2
r 6 cbd2
r 6 bd3
r 6 6bd1
r 6 8bd3
r b 2fc9
r 6 abd3r b 2fc8

r 6 cbd2r b 2fc7

r 6 bd3
r 6 2bd3
r 6 5860
r 6 cbd3
r 6 bd3
r 6 2bd3
r 6 5860
r 6 6bd1
r 6 8bd3
r 6 abd3
r 6 5860
r 6 6bd0
r 6 8bd3
r 6 abd3
r 6 cbd3
r 6 bd3
r 6 2bd3
r 6 abd3
r 6 cbd2
r 6 bd3
r 6 2bd3
r 6 5860
r 6 6bd0
r 6 8bd3
r 6 bd3
r 6 2bd3
r 6 5860
r 6 6bd0
r 6 8bd3
r 6 abd3
r b 2fa8
r b 2fr b 2fa8
a8
r 6 r b 2fa7
6fa7
r 6 8bd4
r 6 abd2
r 6 cbd2
r 6 bd3
r 6 2bd3
r 6 5860
r 6 cbd2
r 6 bd2
r 6 2bd3
r 6 5860
r 6 6bd0
r 6 8bd4
r 6 abd2
r 6 5860
r 6 6bd0
r 6 8bd4
r 6 abd2
r 6 cbd2
r 6 bd2
r 6 2bd3
r 6 8bd1
r 6 abd3
r 6 cbd2
r 6 bd2
r 6 2bd3
r 6 5860
r 6 6bd0
r 6 bd3
r 6 2bd3
r 6 58r b 2f89
89
r 6 6br b 2f88
d8
r 6 r b 2f87
8f87
r 6 abd3
r 6 cbd2
r 6 6bd1
r 6 8bd1
r 6 abd3
r 6 cbd2
r 6 bd3
r 6 2bd3
r 6 5860
r 6 cbd3
r 6 bd3
r 6 2bd2
r 6 5860
r 6 6bd1
r 6 8bd1
r 6 abd3
r 6 2bd2
r 6 5860
r 6 6bd1
r 6 8bd1
r 6 abd3
r 6 cbd3
r 6 bd3
r 6 8bd1
r 6 abd3
r 6 cbd1
r 6 bd3
r 6 2bd2
r 6 5860
r 6 6br b 2f69
d9
r 6 r b 2f68
bf68r 6 2r b 2f67
b67
r 6 5860
r 6 6bd1
r 6 8bd1
r 6 abd3
r 6 cbd1
r 6 6bcf
r 6 8bd3
r 6 abd4
r 6 cbd1
r 6 bd3
r 6 2bd3
r 6 5860
r 6 abd4
r 6 cbd1
r 6 bd3
r 6 2bd3
r 6 5860
r 6 6bcf
r 6 8bd3
r 6 2bd2
r 6 5860
r 6 6bd0
r 6 8bd3
r 6 abd4
r 6 cbd1
r 6 bd3
r 6 8bd2
r 6 abd2
r 6 cbd2
r 6 bdr b 2f49
49r 6 2bd2r b 2f48

r 6 58r b 2f47
67
r 6 6bd0
r 6 bd3
r 6 2bd3
r 6 5860
r 6 6bd0
r 6 8bd2
r 6 abd2
r 6 cbd2
r 6 5860
r 6 6bd1
r 6 8bd3
r 6 abd3
r 6 cbd2
r 6 bd3
r 6 2bd3
r 6 abd3
r 6 cbd3
r 6 bd4
r 6 2bd3
r 6 5860
r 6 6bd1
r 6 8bd3
r 6 2bd4
r 6 5860
r 6 6bd1
r 6 8bd3
r 6 abd3
r 6 cbd3
r 6 bd4
r 6 8bd3
r 6 abd3
r b 2f27
r b 2f27
r b 2f26
r 6 bd4
r 6r b 2f25
 2f25
r 6 5860
r 6 6bd1
r 6 cbd2
r 6 bd3
r 6 2bd3
r 6 5860
r 6 6bd1
r 6 8bd3
r 6 abd3
r 6 5860
r 6 6bd0
r 6 8bd3
r 6 abd3
r 6 cbd2
r 6 bd3
r 6 2bd3
r 6 abd3
r 6 cbd2
r 6 bd3
r 6 2bd3
r 6 5860
r 6 6bd0
r 6 8bd3
r 6 2bd3
r 6 5860
r 6 6bd0
r 6 8bd3
r 6 abd3
r 6 cbd2
r 6 bd3
r 6 6bd0r b 2f06

r 6 8bd1r b 2f05

r 6 abd3r b 2f04

r 6 cbd2
r 6 bd3
r 6 2bd3
r 6 5860
r 6 cbd2
r 6 bd3
r 6 2bd2
r 6 5860
r 6 6bd0
r 6 8bd1
r 6 abd3
r 6 5860
r 6 6bd0
r 6 8bd1
r 6 abd3
r 6 cbd2
r 6 bd3
r 6 2bd2
r 6 abd3
r 6 cbd2
r 6 bd3
r 6 2bd2
r 6 5860
r 6 6bd0
r 6 8bd1
r 6 bd3
r 6 2bd3
r 6 5861
r 6 6bcf
r 6 8bd1
r 6 abd3
r r b 2ee4
6 2eer b 2ee4
4
r 6 r b 2ee3
6ee3
r 6 8bd2
r 6 abd3
r 6 cbd1
r 6 bd3
r 6 2bd3
r 6 5861
r 6 cbd1
r 6 bd3
r 6 2bd2
r 6 5861
r 6 6bcf
r 6 8bd2
r 6 abd3
r 6 5861
r 6 6bcf
r 6 8bd2
r 6 abd3
r 6 cbd1
r 6 bd3
r 6 2bd2
r 6 8bd2
r 6 abd3
r 6 cbd2
r 6 bd2
r 6 2bd2
r 6 5861
r 6 6bcf
r 6 bd2
r 6 2bd3
r 6 5860
r 6 6bdr b 2ec4
0
r 6 8bdr b 2ec3
2
r 6 abdr b 2ec2
3
r 6 cbd2
r 6 6bd0
r 6 8bd2
r 6 abd2
r 6 cbd2
r 6 bd2
r 6 2bd3
r 6 5860
r 6 cbd2
r 6 bd2
r 6 2bd2
r 6 5860
r 6 6bd0
r 6 8bd2
r 6 abd2
r 6 2bd2
r 6 5860
r 6 6bd0
r 6 8bd2
r 6 abd2
r 6 cbd2
r 6 bd2
r 6 8bd2
r 6 abd2
r 6 cbd2
r 6 bd2
r 6 2bd2
r 6 5860
r 6 6bd0
r 6 bd2
r 6 r b 2ea3
2ea3
r 6r b 2ea2
 2ea2
r 6r b 2ea1
 2ea1
r 6 8bd2
r 6 abd2
r 6 cbd2
r 6 6bd0
r 6 8bd1
r 6 abd3
r 6 cbd2
r 6 bd2
r 6 2bd3
r 6 5861
r 6 abd3
r 6 cbd2
r 6 bd3
r 6 2bd2
r 6 5861
r 6 6bd0
r 6 8bd1
r 6 2bd2
r 6 5861
r 6 6bd0
r 6 8bd2
r 6 abd3
r 6 cbd2
r 6 bd3
r 6 8bd2
r 6 abd1
r 6 cbd2
r 6 bd1
r 6 2bd2
r 6 5r b 2e83
883
r 6 6bd0r b 2e82

r 6 bd1
r b 2e81
r 6 2bd3
r 6 5860
r 6 6bd0
r 6 8bd2
r 6 abd1
r 6 cbd2
r 6 5860
r 6 6bd0
r 6 8bd2
r 6 abd3
r 6 cbd2
r 6 bd1
r 6 2bd3
r 6 abd3
r 6 cbd2
r 6 bd3
r 6 2bd3
r 6 5860
r 6 6bd0
r 6 8bd2
r 6 2bd3
r 6 5861
r 6 6bd1
r 6 8bd3
r 6 abd3
r 6 cbd2
r 6 bd3
r 6 8bd3
r 6 abd3
r 6 cbd2
r 6r b 2e62
 2e62r 6 2r b 2e61
b61
r 6 r b 2e60
5e60
r 6 6bd1
r 6 cbd2
r 6 bd3
r 6 2bd3
r 6 5861
r 6 6bd1
r 6 8bd3
r 6 abd3
r 6 5861
r 6 6bd0
r 6 8bd2
r 6 abd3
r 6 cbd2
r 6 bd3
r 6 2bd3
r 6 abd3
r 6 cbd3
r 6 bd2
r 6 2bd3
r 6 5861
r 6 6bd0
r 6 8bd2
r 6 2bd3
r 6 5860
r 6 6bd0
r 6 8bd3
r 6 abd3
r 6 cbd3
r 6 bd2
r 6 6br b 2e42
d2
r 6 8bdr b 2e41
3
r 6 r b 2e40
ae40
r 6 cbd2
r 6 bd3
r 6 2bd3
r 6 5860
r 6 cbd2
r 6 bd3
r 6 2bd3
r 6 5860
r 6 6bd0
r 6 8bd3
r 6 abd3
r 6 5860
r 6 6bd0
r 6 8bd2
r 6 abd2
r 6 cbd2
r 6 bd3
r 6 2bd3
r 6 abd2
r 6 cbd3
r 6 bd3
r 6 2bd3
r 6 5860
r 6 6bd0
r 6 8bd2
r 6 bd3
r 6 2bd3
r 6 5860
r 6 6bd1
r 6 8bd2
r b 2e22
r 6 abdr b 2e21
2
r 6 cbd3
r b 2e20
r 6 6bd1
r 6 8bd2
r 6 abd1
r 6 cbd2
r 6 bd3
r 6 2bd3
r 6 5860
r 6 cbd2
r 6 bd3
r 6 2bd2
r 6 5861
r 6 6bd1
r 6 8bd2
r 6 abd1
r 6 5861
r 6 6bd0
r 6 8bd3
r 6 abd1
r 6 cbd2
r 6 bd3
r 6 2bd2
r 6 8bd3
r 6 abd1
r 6 cbd3
r 6 bd2
r 6 2bd2
r 6 5861
r 6 6bd0
r 6 bd2
r 6 2bd2
r 6 58r b 2e01
61
r 6 6br b 2e00
d0
r 6 8bd2
r b 2dff
r 6 abd1
r 6 cbd3
r 6 6bd0
r 6 8bd2
r 6 abd3
r 6 cbd3
r 6 bd2
r 6 2bd2
r 6 5860
r 6 cbd3
r 6 bd2
r 6 2bd3
r 6 5861
r 6 6bd0
r 6 8bd2
r 6 abd3
r 6 2bd3
r 6 5861
r 6 6bd0
r 6 8bd2
r 6 abd2
r 6 cbd3
r 6 bd2
r 6 8bd2
r 6 abd2
r 6 cbd2
r 6 bd3
r 6 2bd3
r 6 5861
r 6 6bd0
r 6 bd3
r b 2ddf
r 6 2bd3r b 2ddf

r 6 58r b 2dde
6e
r 6 6bd1
r 6 8bd2
r 6 abd2
r 6 cbd2
r 6 6bd1
r 6 8bd2
r 6 abd3
r 6 cbd1
r 6 bd3
r 6 2bd3
r 6 5860
r 6 abd3
r 6 cbd1
r 6 bd3
r 6 2bd3
r 6 5861
r 6 6bd1
r 6 8bd2
r 6 2bd3
r 6 5861
r 6 6bd0
r 6 8bd2
r 6 abd2
r 6 cbd1
r 6 bd3
r 6 8bd2
r 6 abd2
r 6 cbd3
r 6 bd2
r 6 2bd3
r 6 5r b 2dbf
8bf
r 6 r b 2dbe
6dbe
r 6r b 2dbd
 2dbdr 6 2bd3
r 6 5861
r 6 6bd0
r 6 8bd2
r 6 abd2
r 6 cbd3
r 6 5861
r 6 6bd0
r 6 8bd2
r 6 abd2
r 6 cbd3
r 6 bd2
r 6 2bd3
r 6 abd2
r 6 cbd3
r 6 bd3
r 6 2bd3
r 6 5860
r 6 6bd0
r 6 8bd2
r 6 2bd3
r 6 5860
r 6 6bcf
r 6 8bd3
r 6 abd3
r 6 cbd3
r 6 bd3
r 6 8bd3
r 6 abd3
r 6 cbd3
r b 2d9f
r 6 bd3
r 6r b 2d9d
r2bd3
r 6 5r b 2d9c
89c
r 6 6bcf
r 6 cbd3
r 6 bd3
r 6 2bd4
r 6 5860
r 6 6bd0
r 6 8bd3
r 6 abd3
r 6 5860
r 6 6bd0
r 6 8bd1
r 6 abd3
r 6 cbd3
r 6 bd3
r 6 2bd4
r 6 abd3
r 6 cbd3
r 6 bd4
r 6 2bd3
r 6 5861
r 6 6bd0
r 6 8bd1
r 6 2bd3
r 6 5861
r 6 6bd0
r 6 8bd2
r 6 abd3
r 6 cbd3
r 6 bd4
r 6 6r b 2d7e
b7e
r 6 8bd2
r b 2d7c
r 6 abr b 2d7c
dc
r 6 cbd2
r 6 bd3
r 6 2bd3
r 6 5861
r 6 cbd2
r 6 bd3
r 6 2bd2
r 6 5861
r 6 6bd1
r 6 8bd2
r 6 abd3
r 6 5861
r 6 6bd1
r 6 8bd2
r 6 abd2
r 6 cbd3
r 6 bd3
r 6 2bd2
r 6 abd2
r 6 cbd3
r 6 bd2
r 6 2bd3
r 6 5860
r 6 6bd1
r 6 8bd2
r 6 bd2
r 6 2bd3
r 6 5860
r 6 6bd0
r 6 8bd3
r 6 abdr b 2d5d
2
r 6 r b 2d5c
cd5c
r 6r b 2d5b
 2d5b
r 6 8bd3
r 6 abd1
r 6 cbd2
r 6 bd3
r 6 2bd3
r 6 5860
r 6 cbd2
r 6 bd3
r 6 2bd3
r 6 5860
r 6 6bd0
r 6 8bd3
r 6 abd1
r 6 5860
r 6 6bd0
r 6 8bd1
r 6 abd3
r 6 cbd2
r 6 bd3
r 6 2bd3
r 6 8bd1
r 6 abd3
r 6 cbd2
r 6 bd2
r 6 2bd3
r 6 5860
r 6 6bd0
r 6 bd2
r 6 2bd3
r 6 5860
r b 2d3d
r 6r b 2d3c
 6bcf
r 6 8bd1
r b 2d3b
r 6 abd3
r 6 cbd2
r 6 6bcf
r 6 8bd1
r 6 abd3
r 6 cbd2
r 6 bd2
r 6 2bd3
r 6 5860
r 6 cbd2
r 6 bd2
r 6 2bd2
r 6 5860
r 6 6bd0
r 6 8bd1
r 6 abd3
r 6 2bd2
r 6 5860
r 6 6bd0
r 6 8bd1
r 6 abd2
r 6 cbd1
r 6 bd2
r 6 8bd1
r 6 abd2
r 6 cbd1
r 6 bd3
r 6 2bd4
r 6 5860
r 6 6bd0
r 6 r b 2d1c
bd3
r r b 2d1b
6 2bd4r b 2d1b

r 6 5860
r 6 6bd0
r 6 8bd1
r 6 abd2
r 6 cbd1
r 6 6bd0
r 6 8bd1
r 6 abd2
r 6 cbd2
r 6 bd3
r 6 2bd4
r 6 5860
r 6 abd2
r 6 cbd2
r 6 bd3
r 6 2bd3
r 6 5861
r 6 6bd1
r 6 8bd1
r 6 2bd3
r 6 5861
r 6 6bd1
r 6 8bd3
r 6 abd2
r 6 cbd2
r 6 bd3
r 6 8bd3
r 6 abd2
r 6 cbd2
r 6 bd2
r 6 2bdr b 2cfc
2
r 6 586r b 2cfb
1
r 6 6r b 2cfa
bfa
r 6 bd2
r 6 2bd2
r 6 5860
r 6 6bd0
r 6 8bd2
r 6 abd2
r 6 cbd2
r 6 5860
r 6 6bd0
r 6 8bd2
r 6 abd2
r 6 cbd2
r 6 bd2
r 6 2bd2
r 6 abd2
r 6 cbd2
r 6 bd2
r 6 2bd3
r 6 5860
r 6 6bd0
r 6 8bd2
r 6 2bd3
r 6 5860
r 6 6bd0
r 6 8bd2
r 6 abd1
r 6 cbd2
r 6 bd2
r 6 8bd2
r 6 abd1
r 6r b 2cdb
 2cdbr b 2cdb

r 6 bdr b 2cda
2ar 6 2bd4
r 6 5860
r 6 6bd0
r 6 cbd2
r 6 bd2
r 6 2bd4
r 6 5860
r 6 6bd0
r 6 8bd1
r 6 abd1
r 6 5860
r 6 6bd0
r 6 8bd1
r 6 abd3
r 6 cbd2
r 6 bd2
r 6 2bd4
r 6 abd3
r 6 cbd2
r 6 bd2
r 6 2bd2
r 6 5861
r 6 6bd1
r 6 8bd1
r 6 2bd2
r 6 5861
r 6 6bd1
r 6 8bd2
r 6 abd3
r 6 cbd2r b 2cbc

r 6 r b 2cbb
bd2
r b 2cba
r b 2cba
r 6 8bd2
r 6 abd3
r 6 cbd3
r 6 bd3
r 6 2bd2
r 6 5861
r 6 cbd3
r 6 bd3
r 6 2bd2
r 6 5861
r 6 6bd0
r 6 8bd2
r 6 abd3
r 6 5861
r 6 6bd0
r 6 8bd2
r 6 abd3
r 6 cbd2
r 6 bd2
r 6 2bd2
r 6 abd3
r 6 cbd2
r 6 bd2
r 6 2bd3
r 6 5861
r 6 6bd0
r 6 8bd2
r 6 bd2
r 6 2bd3
r b 2c9c
r 6 5861r b 2c9c

r 6 6bd0r b 2c9b

r 6 8bd3
r 6 abd3
r 6 cbd2
r 6 6bd0
r 6 8bd3
r 6 abd3
r 6 cbd3
r 6 bd3
r 6 2bd3
r 6 5861
r 6 cbd3
r 6 bd3
r 6 2bd3
r 6 5860
r 6 6bd1
r 6 8bd2
r 6 abd3
r 6 5860
r 6 6bd1
r 6 8bd2
r 6 abd3
r 6 cbd2
r 6 bd4
r 6 2bd3
r 6 8bd2
r 6 abd3
r 6 cbd2
r 6 bd4
r 6 2bd3
r 6 5860
r 6 6r b 2c7c
b7c
r 6 br b 2c7b
d7br 6 2r b 2c7a
b7a
r 6 5860
r 6 6bd0
r 6 8bd2
r 6 abd3
r 6 cbd2
r 6 6bd0
r 6 8bd2
r 6 abd3
r 6 cbd3
r 6 bd3
r 6 2bd4
r 6 5860
r 6 cbd3
r 6 bd3
r 6 2bd4
r 6 5861
r 6 6bd0
r 6 8bd3
r 6 abd3
r 6 2bd4
r 6 5861
r 6 6bd0
r 6 8bd3
r 6 abd3
r 6 cbd3
r 6 bd3
r 6 8bd3
r 6 abd3
r 6 cbd3
r 6 r b 2c5c
bc5cr b 2c5b
r 6 2bdr b 2c5b
4
r 6 5860
r 6 6bd0
r 6 bd2
r 6 2bd4
r 6 5860
r 6 6bd0
r 6 8bd3
r 6 abd2
r 6 cbd3
r 6 6bd0
r 6 8bd3
r 6 abd2
r 6 cbd2
r 6 bd2
r 6 2bd3
r 6 5860
r 6 abd2
r 6 cbd2
r 6 bd2
r 6 2bd3
r 6 5860
r 6 6bd1
r 6 8bd1
r 6 2bd3
r 6 5860
r 6 6bd1
r 6 8bd1
r 6 abd2
r 6 cbd3
r 6 bd2
r b 2c3d
r 6 8r b 2c3c
b3c
r 6 r b 2c3b
ac3b
r 6 cbd3
r 6 bd2
r 6 2bd2
r 6 5861
r 6 6bd1
r 6 bd2
r 6 2bd2
r 6 5861
r 6 6bd1
r 6 8bd2
r 6 abd2
r 6 cbd3
r 6 5861
r 6 6bd1
r 6 8bd2
r 6 abd2
r 6 cbd2
r 6 bd3
r 6 2bd3
r 6 abd2
r 6 cbd2
r 6 bd3
r 6 2bd3
r 6 5861
r 6 6bd1
r 6 8bd2
r 6 2bd3
r 6 5861
r 6 6bd1
r 6 r b 2c1d
8c1dr b 2c1d

r 6 abdr b 2c1c
2
r 6 cbd2
r 6 bd3
r 6 8bd2
r 6 abd2
r 6 cbd2
r 6 bd2
r 6 2bd2
r 6 5861
r 6 6bd1
r 6 cbd2
r 6 bd2
r 6 2bd2
r 6 5861
r 6 6bd0
r 6 8bd3
r 6 abd3
r 6 5861
r 6 6bd0
r 6 8bd3
r 6 abd3
r 6 cbd4
r 6 bd3
r 6 2bd3
r 6 abd3
r 6 cbd4
r 6 bd3
r 6 2bd3
r 6 5860
r 6 6bd0
r 6 8bd3
r r b 2bfd
r 2bd3
r r b 2bfc
6 5860
r b 2bfc
r 6 6bd0
r 6 8bd3
r 6 abd3
r 6 cbd2
r 6 bd3
r 6 6bd0
r 6 8bd3
r 6 abd3
r 6 cbd2
r 6 bd3
r 6 2bd2
r 6 5861
r 6 cbd2
r 6 bd3
r 6 2bd2
r 6 5861
r 6 6bd1
r 6 8bd2
r 6 abd3
r 6 5861
r 6 6bd1
r 6 8bd2
r 6 abd3
r 6 cbd3
r 6 bd2
r 6 2bd2
r 6 abd3
r 6 cbd3
r 6 bd2
r 6 2bd2
r 6 5861
r 6 6bcfr b 2bdc
rr 6r b 2bdb
 8bd2
r b 2bda
r 6 bd2
r 6 2bd2
r 6 5861
r 6 6bcf
r 6 8bd2
r 6 abd3
r 6 cbd2
r 6 6bcf
r 6 8bd2
r 6 abd3
r 6 cbd2
r 6 bd2
r 6 2bd3
r 6 5861
r 6 cbd2
r 6 bd2
r 6 2bd3
r 6 5861
r 6 6bd0
r 6 8bd1
r 6 abd2
r 6 5861
r 6 6bd0
r 6 8bd1
r 6 abd2
r 6 cbd3
r 6 bd3
r 6 2bd3
r 6 8bd1
r 6 abd2
r 6r b 2bbc
 cbr b 2bbc
d2br 6 r b 2bbb
bbbbr 6 2bd2
r 6 5861
r 6 6bcf
r 6 bd3
r 6 2bd2
r 6 5861
r 6 6bcf
r 6 8bd2
r 6 abd3
r 6 cbd4
r 6 6bcf
r 6 8bd2
r 6 abd3
r 6 cbd4
r 6 bd3
r 6 2bd3
r 6 5860
r 6 cbd4
r 6 bd3
r 6 2bd3
r 6 5860
r 6 6bd0
r 6 8bd3
r 6 abd3
r 6 2bd3
r 6 5860
r 6 6bd0
r 6 8bd3
r 6 abd2
r 6 cbr b 2b9d
dd
r b 2b9c
r 6 bd2
r r b 2b9b
r 8bd3
r 6 abd2
r 6 cbd3
r 6 bd2
r 6 2bd2
r 6 5860
r 6 6bd1
r 6 bd2
r 6 2bd2
r 6 5860
r 6 6bd1
r 6 8bd3
r 6 abd2
r 6 cbd3
r 6 6bd1
r 6 8bd3
r 6 abd2
r 6 cbd3
r 6 bd3
r 6 2bd3
r 6 5861
r 6 abd2
r 6 cbd3
r 6 bd3
r 6 2bd3
r 6 5861
r 6 6bd0
r 6 8bd1
r 6 2bd3
r 6 5861
r 6 r b 2b7d
2b7d
r 6 8r b 2b7c
b7c
r 6r b 2b7b
 2b7b
r 6 cbd2
r 6 bd2
r 6 8bd1
r 6 abd3
r 6 cbd2
r 6 bd2
r 6 2bd3
r 6 5860
r 6 6bcf
r 6 bd2
r 6 2bd3
r 6 5860
r 6 6bcf
r 6 8bd3
r 6 abd2
r 6 cbd2
r 6 5860
r 6 6bcf
r 6 8bd3
r 6 abd2
r 6 cbd2
r 6 bd3
r 6 2bd3
r 6 abd2
r 6 cbd2
r 6 bd3
r 6 2bd3
r 6 5861
r 6 6bd0
r 6 r b 2b5d
8b5dr b 2b5d

r 6 2bdr b 2b5c
3
r 6 5861
r 6 6bd0
r 6 8bd3
r 6 abd3
r 6 cbd3
r 6 bd4
r 6 8bd3
r 6 abd3
r 6 cbd3
r 6 bd4
r 6 2bd3
r 6 5860
r 6 6bd0
r 6 cbd3
r 6 bd4
r 6 2bd3
r 6 5860
r 6 6bd0
r 6 8bd2
r 6 abd3
r 6 5860
r 6 6bd0
r 6 8bd2
r 6 abd3
r 6 cbd3
r 6 bd3
r 6 2bd3
r 6 abd3
r 6 cbd3
r 6 bdr b 2b3e
3er b 2b3d
r b 2b3d
r 6 5861r b 2b3c

r 6 6bd0
r 6 8bd2
r 6 2bd3
r 6 5861
r 6 6bd0
r 6 8bd2
r 6 abd3
r 6 cbd1
r 6 bd2
r 6 6bd0
r 6 8bd2
r 6 abd3
r 6 cbd1
r 6 bd2
r 6 2bd3
r 6 5861
r 6 cbd1
r 6 bd2
r 6 2bd3
r 6 5861
r 6 6bd0
r 6 8bd2
r 6 abd3
r 6 5861
r 6 6bd0
r 6 8bd2
r 6 abd3
r 6 cbd3
r 6 bd4
r 6 2bd2
r 6 ar b 2b1d
b1d
r 6 cbr b 2b1c
dc
r 6r b 2b1b
 2b1br 6 2bd2
r 6 5860
r 6 6bd0
r 6 8bd3
r 6 bd3
r 6 2bd2
r 6 5860
r 6 6bd0
r 6 8bd3
r 6 abd2
r 6 cbd2
r 6 6bd0
r 6 8bd3
r 6 abd2
r 6 cbd2
r 6 bd3
r 6 2bd3
r 6 5861
r 6 cbd2
r 6 bd3
r 6 2bd3
r 6 5861
r 6 6bd0
r 6 8bd1
r 6 abd3
r 6 5861
r 6 6bd0
r 6 8bd1
r 6 abd3
r 6 r b 2afd
cafd
r 6 br b 2afc
dfcr 6 2br b 2afb
db
r 6 8bd2
r 6 abd3
r 6 cbd3
r 6 bd1
r 6 2bd3
r 6 5861
r 6 6bd0
r 6 bd3
r 6 2bd3
r 6 5861
r 6 6bd0
r 6 8bd2
r 6 abd4
r 6 cbd1
r 6 6bd0
r 6 8bd2
r 6 abd4
r 6 cbd1
r 6 bd3
r 6 2bd2
r 6 5860
r 6 cbd1
r 6 bd3
r 6 2bd2
r 6 5860
r 6 6bd0
r 6 8bd2
r 6 abd3
r 6 2bd2
r 6 5860
r 6 6r b 2adc
bdc
r 6 r b 2adb
8adb
r b 2ada
r 6 abd3
r 6 cbd1
r 6 bd3
r 6 8bd2
r 6 abd3
r 6 cbd1
r 6 bd3
r 6 2bd2
r 6 5860
r 6 6bd0
r 6 bd3
r 6 2bd2
r 6 5860
r 6 6bd0
r 6 8bd2
r 6 abd3
r 6 cbd2
r 6 6bd0
r 6 8bd2
r 6 abd3
r 6 cbd2
r 6 bd3
r 6 2bd2
r 6 5861
r 6 abd3
r 6 cbd2
r 6 bd3
r 6 2bd2
r 6 5861
r 6 6bd1
r 6 r b 2abc
8abc
r b 2abb
r 6 2r b 2abb
bbb
r 6 5861
r 6 6bd1
r 6 8bd3
r 6 abd3
r 6 cbd3
r 6 bd3
r 6 8bd1
r 6 abd3
r 6 cbd3
r 6 bd3
r 6 2bd3
r 6 5860
r 6 6bd0
r 6 bd3
r 6 2bd3
r 6 5860
r 6 6bd0
r 6 8bd1
r 6 abd2
r 6 cbd3
r 6 5860
r 6 6bd0
r 6 8bd1
r 6 abd2
r 6 cbd3
r 6 bd3
r 6 2bd2
r 6 abd3
r 6 cbd3
r 6 bd3
r 6 2br b 2a9c
dc
r 6 58r b 2a9b
6b
r 6 r b 2a9a
6a9a
r 6 8bd1
r 6 2bd3
r 6 5860
r 6 6bd0
r 6 8bd1
r 6 abd3
r 6 cbd2
r 6 bd3
r 6 8bd2
r 6 abd3
r 6 cbd2
r 6 bd3
r 6 2bd3
r 6 5861
r 6 6bcf
r 6 cbd2
r 6 bd3
r 6 2bd3
r 6 5861
r 6 6bcf
r 6 8bd2
r 6 abd3
r 6 5860
r 6 6bcf
r 6 8bd2
r 6 abd3
r 6 cbd2
r 6 bd2
r 6 2bd2
r 6r b 2a7c
 2a7c
r b 2a7c
r 6 cbr b 2a7b
db
r 6 bd2
r 6 2bd2
r 6 5860
r 6 6bcf
r 6 8bd3
r 6 2bd3
r 6 5860
r 6 6bcf
r 6 8bd3
r 6 abd2
r 6 cbd2
r 6 bd3
r 6 6bd0
r 6 8bd3
r 6 abd2
r 6 cbd2
r 6 bd3
r 6 2bd3
r 6 5860
r 6 cbd2
r 6 bd3
r 6 2bd3
r 6 5860
r 6 6bd0
r 6 8bd3
r 6 abd3
r 6 5860
r 6 6bd0
r 6 8bd3
r 6 abd3
r b 2a5d
r 6 cbd2r b 2a5c

r 6r b 2a5b
 bd2
r 6 2bd4
r 6 abd2
r 6 cbd2
r 6 bd2
r 6 2bd4
r 6 5860
r 6 6bd0
r 6 8bd1
r 6 bd2
r 6 2bd3
r 6 5860
r 6 6bd0
r 6 8bd1
r 6 abd2
r 6 cbd2
r 6 6bd0
r 6 8bd1
r 6 abd2
r 6 cbd2
r 6 bd2
r 6 2bd3
r 6 5861
r 6 cbd3
r 6 bd2
r 6 2bd3
r 6 5861
r 6 6bd0
r 6 8bd2
r 6 abd3
r 6 5r b 2a3d
83d
r 6 6r b 2a3c
b3c
r 6 r b 2a3b
8a3b
r 6 abd3
r 6 cbd3
r 6 bd2
r 6 2bd2
r 6 8bd2
r 6 abd3
r 6 cbd3
r 6 bd2
r 6 2bd2
r 6 5860
r 6 6bd0
r 6 bd2
r 6 2bd2
r 6 5860
r 6 6bd0
r 6 8bd2
r 6 abd3
r 6 cbd3
r 6 6bcf
r 6 8bd2
r 6 abd3
r 6 cbd3
r 6 bd2
r 6 2bd3
r 6 5861
r 6 cbd1
r 6 bd2
r 6 2bd3
r 6 5861
r 6 6bcf
r 6r b 2a1c
 2a1c
r 6 r b 2a1b
aa1b
r 6r b 2a1a
 2bd2
r 6 5860
r 6 6bcf
r 6 8bd2
r 6 abd3
r 6 cbd1
r 6 bd1
r 6 8bd3
r 6 abd2
r 6 cbd1
r 6 bd1
r 6 2bd2
r 6 5860
r 6 6bcf
r 6 bd3
r 6 2bd2
r 6 5860
r 6 6bcf
r 6 8bd3
r 6 abd2
r 6 cbd1
r 6 6bcf
r 6 8bd3
r 6 abd2
r 6 cbd1
r 6 bd3
r 6 2bd3
r 6 5860
r 6 abd3
r 6 cbd2
r 6 r b 29fc
b9fcr 6 2r b 29fb
bfb
r 6r b 29fa
 29fa
r 6 6bcf
r 6 8bd2
r 6 2bd3
r 6 5862
r 6 6bcf
r 6 8bd2
r 6 abd3
r 6 cbd2
r 6 bd2
r 6 8bd1
r 6 abd3
r 6 cbd2
r 6 bd2
r 6 2bd3
r 6 5862
r 6 6bcf
r 6 bd3
r 6 2bd3
r 6 5862
r 6 6bcf
r 6 8bd1
r 6 abd3
r 6 cbd3
r 6 5860
r 6 6bd0
r 6 8bd1
r 6 abd3
r 6 cbd3
r 6 bd3
r 6 2r b 29dc
bdcr b 29dc

r 6 abd2r b 29db

r 6 cbd2
r 6 bd3
r 6 2bd2
r 6 5860
r 6 6bd0
r 6 8bd3
r 6 2bd3
r 6 5860
r 6 6bd0
r 6 8bd3
r 6 abd2
r 6 cbd2
r 6 bd2
r 6 8bd2
r 6 abd2
r 6 cbd2
r 6 bd2
r 6 2bd3
r 6 5860
r 6 6bd0
r 6 cbd3
r 6 bd3
r 6 2bd3
r 6 5860
r 6 6bd0
r 6 8bd2
r 6 abd2
r 6 5861
r 6 6bd0
r 6 8bd2
r b 29bc
r 6 abd2
r b 29bc
r 6 cbd3r b 29bb

r 6 bd3
r 6 2bd2
r 6 abd2
r 6 cbd2
r 6 bd3
r 6 2bd2
r 6 5861
r 6 6bd0
r 6 8bd2
r 6 2bd2
r 6 5861
r 6 6bd0
r 6 8bd2
r 6 abd2
r 6 cbd2
r 6 bd2
r 6 6bd0
r 6 8bd1
r 6 abd2
r 6 cbd2
r 6 bd2
r 6 2bd2
r 6 5861
r 6 cbd2
r 6 bd2
r 6 2bd2
r 6 5861
r 6 6bd0
r 6 8bd1
r 6 abd3
r b 299d
r 6 5r b 299c
89c
r 6 6r b 299b
b9b
r 6 8bd1
r 6 abd3
r 6 cbd2
r 6 bd2
r 6 2bd3
r 6 abd2
r 6 cbd2
r 6 bd2
r 6 2bd3
r 6 5861
r 6 6bcf
r 6 8bd2
r 6 bd1
r 6 2bd3
r 6 5861
r 6 6bcf
r 6 8bd2
r 6 abd2
r 6 cbd2
r 6 6bcf
r 6 8bd1
r 6 abd2
r 6 cbd2
r 6 bd1
r 6 2bd3
r 6 5861
r 6 cbd3
r 6 bd3
r 6 2bd3
r 6 5r b 297d
87d
r b 297d
r 6 6bcf
r b 297c
r 6 8bd1
r 6 abd2
r 6 5861
r 6 6bcf
r 6 8bd1
r 6 abd2
r 6 cbd3
r 6 bd3
r 6 2bd2
r 6 8bd1
r 6 abd3
r 6 cbd3
r 6 bd3
r 6 2bd2
r 6 5861
r 6 6bcf
r 6 bd3
r 6 2bd3
r 6 5861
r 6 6bcf
r 6 8bd1
r 6 abd3
r 6 cbd1
r 6 6bd0
r 6 8bd2
r 6 abd3
r 6 cbd1
r 6 bd3
r 6 2bd3
r 6 5860
r 6r b 295d
 cbd2
r 6r b 295c
 bd4
r b 295b
r 6 2bd3
r 6 5860
r 6 6bd0
r 6 8bd2
r 6 abd2
r 6 2bd3
r 6 5861
r 6 6bd0
r 6 8bd2
r 6 abd2
r 6 cbd2
r 6 bd4
r 6 8bd1
r 6 abd3
r 6 cbd2
r 6 bd4
r 6 2bd3
r 6 5861
r 6 6bd0
r 6 bd3
r 6 2bd3
r 6 5861
r 6 6bd0
r 6 8bd1
r 6 abd3
r 6 cbd3
r 6 6bd1
r 6 8bd1
r 6 abd3
r 6 cbd3
r 6 bdr b 293d
3dr 6r b 293c
 2bd3
r b 293b
r 6 5860
r 6 abd2
r 6 cbd2
r 6 bd2
r 6 2bd3
r 6 5860
r 6 6bd1
r 6 8bd1
r 6 2bd2
r 6 5861
r 6 6bd1
r 6 8bd1
r 6 abd2
r 6 cbd2
r 6 bd2
r 6 8bd3
r 6 abd2
r 6 cbd2
r 6 bd2
r 6 2bd2
r 6 5861
r 6 6bd0
r 6 bd2
r 6 2bd3
r 6 5861
r 6 6bd0
r 6 8bd3
r 6 abd2
r 6 cbd3
r 6 5861
r 6r b 291d
 291r b 291d
d
r 6 8br b 291c
dc
r 6 abd2
r 6 cbd3
r 6 bd2
r 6 2bd3
r 6 abd2
r 6 cbd3
r 6 bd2
r 6 2bd3
r 6 5861
r 6 6bd1
r 6 8bd2
r 6 2bd4
r 6 5861
r 6 6bd1
r 6 8bd2
r 6 abd2
r 6 cbd3
r 6 bd2
r 6 8bd3
r 6 abd2
r 6 cbd3
r 6 bd2
r 6 2bd4
r 6 5861
r 6 6bd0
r 6 cbd2
r 6 bd3
r 6 2bd3
r 6 5861
r 6 6br b 28fe
de
r 6r b 28fd
 8bd3
r 6 abdr b 28fc
c
r 6 5861
r 6 6bcf
r 6 8bd1
r 6 abd2
r 6 cbd2
r 6 bd3
r 6 2bd3
r 6 abd2
r 6 cbd1
r 6 bd3
r 6 2bd3
r 6 5861
r 6 6bcf
r 6 8bd1
r 6 2bd3
r 6 5861
r 6 6bcf
r 6 8bd1
r 6 abd2
r 6 cbd1
r 6 bd2
r 6 6bd0
r 6 8bd2
r 6 abd3
r 6 cbd1
r 6 bd2
r 6 2bd3
r 6 5861
r 6 cbd3
r 6 bd3
r b 28de
r 6 2bd3
r b 28dc
r b 28dr b 28dc
c
r 6 6bd0
r 6 8bd2
r 6 abd3
r 6 5861
r 6 6bcf
r 6 8bd2
r 6 abd3
r 6 cbd3
r 6 bd3
r 6 2bd3
r 6 abd2
r 6 cbd2
r 6 bd3
r 6 2bd3
r 6 5861
r 6 6bcf
r 6 8bd2
r 6 bd3
r 6 2bd3
r 6 5860
r 6 6bcf
r 6 8bd2
r 6 abd2
r 6 cbd2
r 6 6bd0
r 6 8bd3
r 6 abd3
r 6 cbd2
r 6 bd3
r 6 2bd3
r b 28bd
r 6 5860
r b 28bd
r 6 cbr b 28bc
dc
r 6 bd3
r 6 2bd4
r 6 5860
r 6 6bd0
r 6 8bd3
r 6 abd3
r 6 5860
r 6 6bd1
r 6 8bd3
r 6 abd3
r 6 cbd2
r 6 bd3
r 6 2bd4
r 6 8bd2
r 6 abd2
r 6 cbd2
r 6 bd3
r 6 2bd4
r 6 5860
r 6 6bd1
r 6 bd3
r 6 2bd3
r 6 5860
r 6 6bd1
r 6 8bd2
r 6 abd2
r 6 cbd2
r 6 6bd0
r 6 8bd2
r 6 abd3
r 6 r b 289d
c89d
r b 289c
r 6 br b 289c
d9cr 6 2bd3
r 6 5860
r 6 cbd2
r 6 bd3
r 6 2bd3
r 6 5860
r 6 6bd0
r 6 8bd2
r 6 abd3
r 6 2bd3
r 6 5860
r 6 6bd0
r 6 8bd2
r 6 abd3
r 6 cbd2
r 6 bd3
r 6 8bd2
r 6 abd2
r 6 cbd2
r 6 bd3
r 6 2bd3
r 6 5860
r 6 6bd0
r 6 bd3
r 6 2bd3
r 6 5860
r 6 6bd0
r 6 8bd2
r 6 abd2
r 6 cbd2
r 6 6bd1
r 6 8bd2
r 6 abd2
r 6 cbdr b 287a
2
r 6 br b 2879
d79r 6 2r b 2878
b78
r 6 5860
r 6 abd2
r 6 cbd1
r 6 bd3
r 6 2bd3
r 6 5860
r 6 6bd1
r 6 8bd2
r 6 2bd2
r 6 5861
r 6 6bd1
r 6 8bd2
r 6 abd2
r 6 cbd1
r 6 bd3
r 6 8bd2
r 6 abd3
r 6 cbd3
r 6 bd3
r 6 2bd2
r 6 5861
r 6 6bd1
r 6 bd3
r 6 2bd3
r 6 5860
r 6 6bd1
r 6 8bd2
r 6 abd3
r 6 cbd3
r 6 58r b 285a
6a
r 6 6bd0r b 2859

r 6 r b 2858
r 6 r b 
r 6 abd3
r 6 cbd3
r 6 bd3
r 6 2bd3
r 6 abd3
r 6 cbd3
r 6 bd3
r 6 2bd3
r 6 5860
r 6 6bd0
r 6 8bd1
r 6 2bd3
r 6 5860
r 6 6bd0
r 6 8bd1
r 6 abd3
r 6 cbd3
r 6 bd3
r 6 8bd1
r 6 abd3
r 6 cbd2
r 6 bd3
r 6 2bd3
r 6 5860
r 6 6bd0
r 6 cbd2
r 6 bd3
r 6 2bd2
r 6 5860
r 6 6bd0r b 283a

r 6 8bd1
r 6r b 2838
rabd3
r b 2837
r 6 5860
r 6 6bd0
r 6 8bd1
r 6 abd3
r 6 cbd2
r 6 bd3
r 6 2bd2
r 6 abd1
r 6 cbd2
r 6 bd4
r 6 2bd2
r 6 5860
r 6 6bd0
r 6 8bd1
r 6 2bd3
r 6 5861
r 6 6bd0
r 6 8bd1
r 6 abd1
r 6 cbd2
r 6 bd4
r 6 6bd0
r 6 8bd2
r 6 abd3
r 6 cbd1
r 6 bd4
r 6 2bd3
r 6 5861
r 6 cbd1
r 6 bd3
r 6 2bd3
r b 2819
r 6 5861r b 2818

r 6 r b 2817
6817
r 6 8bd2
r 6 abd3
r 6 5861
r 6 6bd0
r 6 8bd2
r 6 abd3
r 6 cbd1
r 6 bd3
r 6 2bd3
r 6 abd2
r 6 cbd2
r 6 bd4
r 6 2bd3
r 6 5861
r 6 6bd0
r 6 8bd2
r 6 bd4
r 6 2bd3
r 6 5860
r 6 6bcf
r 6 8bd2
r 6 abd2
r 6 cbd2
r 6 6bcf
r 6 8bd2
r 6 abd1
r 6 cbd2
r 6 bd4
r 6 2bd3
r 6 5860
r 6 cbr b 27f8
d8
r 6 bd3
r b 27f7
r 6 2bd2
r 6 r b 27f5
5860
r 6 6bcf
r 6 8bd2
r 6 abd1
r 6 5861
r 6 6bd0
r 6 8bd3
r 6 abd1
r 6 cbd2
r 6 bd3
r 6 2bd2
r 6 8bd3
r 6 abd2
r 6 cbd2
r 6 bd2
r 6 2bd2
r 6 5861
r 6 6bd0
r 6 bd2
r 6 2bd3
r 6 5861
r 6 6bcf
r 6 8bd3
r 6 abd2
r 6 cbd2
r 6 6bcf
r 6 8bd2
r 6 abd3
r 6 cbd2
r 6 bd2
r 6 2bd3
r 6 5861r b 27d6
rr 6r b 27d5
rcbd2
r r b 27d4
r bd3
r 6 2bd2
r 6 5861
r 6 6bcf
r 6 8bd2
r 6 abd3
r 6 2bd2
r 6 5861
r 6 6bd0
r 6 8bd1
r 6 abd3
r 6 cbd2
r 6 bd3
r 6 8bd1
r 6 abd2
r 6 cbd2
r 6 bd3
r 6 2bd2
r 6 5861
r 6 6bd0
r 6 bd3
r 6 2bd3
r 6 5861
r 6 6bcf
r 6 8bd1
r 6 abd2
r 6 cbd2
r 6 6bcf
r 6 8bd1
r 6 abd2
r b 27b6
r b 27b6r b 27b6

r 6 br b 27b5
db5r 6 2bd3
r 6 5861
r 6 abd2
r 6 cbd1
r 6 bd2
r 6 2bd2
r 6 5861
r 6 6bcf
r 6 8bd1
r 6 2bd2
r 6 5861
r 6 6bd0
r 6 8bd0
r 6 abd2
r 6 cbd1
r 6 bd2
r 6 8bd0
r 6 abd2
r 6 cbd1
r 6 bd3
r 6 2bd2
r 6 5861
r 6 6bd0
r 6 bd3
r 6 2bd3
r 6 5860
r 6 6bd0
r 6 8bd0
r 6 abd2
r 6 cbd1
r b 2797
r 6 5860
r 6r b 2795
 6bd0
r 6r b 2794
 2794
r 6 abd3
r 6 cbd1
r 6 bd3
r 6 2bd3
r 6 abd3
r 6 cbd1
r 6 bd3
r 6 2bd3
r 6 5860
r 6 6bd0
r 6 8bd1
r 6 2bd3
r 6 5860
r 6 6bcf
r 6 8bd2
r 6 abd3
r 6 cbd1
r 6 bd3
r 6 8bd2
r 6 abd3
r 6 cbd3
r 6 bd2
r 6 2bd3
r 6 5860
r 6 6bcf
r 6 cbd3
r 6 bd2
r 6 2bd3
r 6 5860
r 6 6bcf
r 6r b 2775
 8bd2
r 6r b 2774
 2774
r 6r b 2773
 2773
r 6 6bd0
r 6 8bd1
r 6 abd2
r 6 cbd3
r 6 bd2
r 6 2bd3
r 6 abd2
r 6 cbd3
r 6 bd2
r 6 2bd3
r 6 5860
r 6 6bd0
r 6 8bd1
r 6 2bd3
r 6 5860
r 6 6bd0
r 6 8bd1
r 6 abd2
r 6 cbd3
r 6 bd2
r 6 6bd0
r 6 8bd1
r 6 abd2
r 6 cbd3
r 6 bd1
r 6 2bd3
r 6 5860
r 6 cbd3
r 6 bd1
r 6 2bd1
r 6 5861r b 2754

r 6 6bd0r b 2753

r 6 8r b 2752
b52
r 6 abd2
r 6 5861
r 6 6bd0
r 6 8bd2
r 6 abd2
r 6 cbd3
r 6 bd1
r 6 2bd1
r 6 abd2
r 6 cbd2
r 6 bd2
r 6 2bd3
r 6 5861
r 6 6bd0
r 6 8bd2
r 6 bd2
r 6 2bd3
r 6 5860
r 6 6bd0
r 6 8bd2
r 6 abd2
r 6 cbd2
r 6 6bd0
r 6 8bd2
r 6 abd1
r 6 cbd1
r 6 bd2
r 6 2bd3
r 6 5860
r 6 cbd1
r 6 bdr b 2733
43r 6 2bd3
r 6r b 2731
 2731
r 6 6br b 2730
d0
r 6 8bd2
r 6 abd1
r 6 5861
r 6 6bd0
r 6 8bd3
r 6 abd3
r 6 cbd1
r 6 bd4
r 6 2bd3
r 6 8bd3
r 6 abd3
r 6 cbd3
r 6 bd3
r 6 2bd3
r 6 5861
r 6 6bd0
r 6 bd3
r 6 2bd3
r 6 5861
r 6 6bd1
r 6 8bd2
r 6 abd3
r 6 cbd3
r 6 6bd1
r 6 8bd2
r 6 abd2
r 6 cbd1
r 6 bd3
r 6 2bd3
r 6 5861
r 6 cr b 2711
b11
r 6 r b 2710
b710r 6 r b 270f
270f
r 6 5860
r 6 6bd1
r 6 8bd2
r 6 abd2
r 6 2bd3
r 6 5860
r 6 6bd0
r 6 8bd3
r 6 abd4
r 6 cbd1
r 6 bd4
r 6 8bd3
r 6 abd4
r 6 cbd3
r 6 bd3
r 6 2bd2
r 6 5860
r 6 6bd0
r 6 bd3
r 6 2bd2
r 6 5860
r 6 6bd0
r 6 8bd3
r 6 abd4
r 6 cbd3
r 6 6bd0
r 6 8bd2
r 6 abd4
r 6 cbd2
r 6 bd3
r b 26f0
r 6 r b 26f0
26f0
r 6r b 26ef
 26ef
r 6 abd4
r 6 cbd2
r 6 bd3
r 6 2bd3
r 6 5862
r 6 6bd0
r 6 8bd2
r 6 2bd3
r 6 5862
r 6 6bd0
r 6 8bd1
r 6 abd2
r 6 cbd2
r 6 bd3
r 6 8bd1
r 6 abd2
r 6 cbd3
r 6 bd3
r 6 2bd3
r 6 5862
r 6 6bd0
r 6 bd3
r 6 2bd3
r 6 5861
r 6 6bd0
r 6 8bd1
r 6 abd2
r 6 cbd3
r 6 5861
r 6 6r b 26d1
6d1
r b 26d0
r 6 8bd2r b 26d0

r 6 abd2
r 6 cbd2
r 6 bd3
r 6 2bd3
r 6 abd2
r 6 cbd2
r 6 bd3
r 6 2bd3
r 6 5861
r 6 6bd0
r 6 8bd2
r 6 2bd3
r 6 5861
r 6 6bd0
r 6 8bd2
r 6 abd3
r 6 cbd2
r 6 bd3
r 6 8bd2
r 6 abd3
r 6 cbd2
r 6 bd2
r 6 2bd3
r 6 5861
r 6 6bd0
r 6 cbd2
r 6 bd2
r 6 2bd3
r 6 5860
r 6 6bd0
r 6 8r b 26b1
bb1
r 6 ar b 26b0
bb0
r 6 r b 26af
56af
r 6 6bd0
r 6 8bd1
r 6 abd3
r 6 cbd2
r 6 bd2
r 6 2bd3
r 6 abd3
r 6 cbd2
r 6 bd3
r 6 2bd2
r 6 5860
r 6 6bd0
r 6 8bd1
r 6 2bd2
r 6 5860
r 6 6bd0
r 6 8bd2
r 6 abd2
r 6 cbd2
r 6 bd3
r 6 6bd0
r 6 8bd2
r 6 abd2
r 6 cbd2
r 6 bd2
r 6 2bd2
r 6 5860
r 6 cbd2
r 6 bd2
r 6 r b 2691
2691
r 6 58r b 2690
60
r 6 6r b 268f
b8f
r 6 8bd2
r 6 abd2
r 6 5860
r 6 6bd0
r 6 8bd1
r 6 abd2
r 6 cbd2
r 6 bd2
r 6 2bd3
r 6 abd2
r 6 cbd2
r 6 bd3
r 6 2bd4
r 6 5860
r 6 6bd0
r 6 8bd1
r 6 bd3
r 6 2bd4
r 6 5860
r 6 6bcf
r 6 8bd2
r 6 abd2
r 6 cbd2
r 6 6bcf
r 6 8bd2
r 6 abd3
r 6 cbd2
r 6 bd3
r 6 2bd4
r 6 5860
r 6 r b 2670
c670
r 6 bdr b 266f
3fr 6 2bd3
r b 266e
r 6 5861
r 6 6bd0
r 6 8bd2
r 6 abd3
r 6 5861
r 6 6bd0
r 6 8bd1
r 6 abd2
r 6 cbd1
r 6 bd3
r 6 2bd3
r 6 8bd1
r 6 abd2
r 6 cbd1
r 6 bd3
r 6 2bd2
r 6 5860
r 6 6bd0
r 6 bd3
r 6 2bd2
r 6 5860
r 6 6bcf
r 6 8bd2
r 6 abd2
r 6 cbd1
r 6 6bcf
r 6 8bd2
r 6 abd3
r 6 cbd2
r 6 bd2
r 6 2bd2
r 6 58r b 264e
6e
r 6r b 264d
 264d
r 6 r b 264c
r 6
r 6 2bd3
r 6 5861
r 6 6bd0
r 6 8bd2
r 6 abd3
r 6 2bd3
r 6 5861
r 6 6bd0
r 6 8bd3
r 6 abd2
r 6 cbd2
r 6 bd2
r 6 8bd3
r 6 abd2
r 6 cbd2
r 6 bd3
r 6 2bd3
r 6 5861
r 6 6bd0
r 6 bd3
r 6 2bd3
r 6 5860
r 6 6bd0
r 6 8bd1
r 6 abd2
r 6 cbd2
r 6 6bd0
r 6 8bd1
r 6 abd2
r 6 cbd2
r 6r b 262d
 bd3
r 6r b 262c
 2bd3
r r b 262b
6 262b
r 6 abd2
r 6 cbd2
r 6 bd3
r 6 2bd3
r 6 5861
r 6 6bd0
r 6 8bd1
r 6 2bd3
r 6 5861
r 6 6bd0
r 6 8bd1
r 6 abd2
r 6 cbd2
r 6 bd3
r 6 8bd1
r 6 abd2
r 6 cbd2
r 6 bd4
r 6 2bd2
r 6 5861
r 6 6bd0
r 6 bd4
r 6 2bd2
r 6 5861
r 6 6bd0
r 6 8bd2
r 6 abd2
r 6 cbd2
r 6 5861
r 6r b 260d
 6bd0
r r b 260c
6 260c
r b 260b
r 6 abd2
r 6 cbd3
r 6 bd2
r 6 2bd2
r 6 abd2
r 6 cbd3
r 6 bd2
r 6 2bd2
r 6 5861
r 6 6bd0
r 6 8bd2
r 6 2bd2
r 6 5861
r 6 6bd0
r 6 8bd2
r 6 abd3
r 6 cbd3
r 6 bd2
r 6 8bd2
r 6 abd3
r 6 cbd3
r 6 bd3
r 6 2bd2
r 6 5861
r 6 6bd0
r 6 cbd3
r 6 bd3
r 6 2bd2
r 6 5861
r 6 6bd1
r 6 r b 25ed
85ed
r b 25ec
r b 25ec
r 6 5861
r b 25eb
r 6 6bd1
r 6 8bd1
r 6 abd3
r 6 cbd1
r 6 bd3
r 6 2bd2
r 6 abd3
r 6 cbd1
r 6 bd3
r 6 2bd2
r 6 5861
r 6 6bcf
r 6 8bd1
r 6 2bd2
r 6 5861
r 6 6bcf
r 6 8bd1
r 6 abd1
r 6 cbd1
r 6 bd3
r 6 6bcf
r 6 8bd1
r 6 abd1
r 6 cbd3
r 6 bd3
r 6 2bd2
r 6 5861
r 6 cbd3
r 6 bd3
r 6 2bd2
r b 25cc
r 6 5861
r 6 r b 25cb
r 6 r b 25cb

r 6 8bd2
r 6 abd1
r 6 5861
r 6 6bcf
r 6 8bd2
r 6 abd2
r 6 cbd2
r 6 bd3
r 6 2bd2
r 6 abd2
r 6 cbd2
r 6 bd3
r 6 2bd3
r 6 5861
r 6 6bcf
r 6 8bd2
r 6 bd3
r 6 2bd3
r 6 5861
r 6 6bd1
r 6 8bd2
r 6 abd2
r 6 cbd2
r 6 6bd1
r 6 8bd2
r 6 abd2
r 6 cbd2
r 6 bd3
r 6 2bd2
r 6 5861
r 6 cbr b 25ac
dc
r 6 bdr b 25ab
3br 6 2r b 25aa
baa
r 6 5861
r 6 6bd1
r 6 8bd2
r 6 abd2
r 6 5861
r 6 6bd1
r 6 8bd2
r 6 abd3
r 6 cbd1
r 6 bd2
r 6 2bd2
r 6 8bd2
r 6 abd3
r 6 cbd1
r 6 bd2
r 6 2bd3
r 6 5861
r 6 6bd1
r 6 bd2
r 6 2bd3
r 6 5861
r 6 6bd0
r 6 8bd2
r 6 abd4
r 6 cbd1
r 6 6bd0
r 6 8bd2
r 6 abd4
r 6 cbd3
r 6 bd3
r b 258c
r 6 2bd3r b 258b

r 6 5861
r b 2589
r 6 cbd3
r 6 bd3
r 6 2bd3
r 6 5860
r 6 6bcf
r 6 8bd2
r 6 abd4
r 6 2bd3
r 6 5860
r 6 6bcf
r 6 8bd2
r 6 abd1
r 6 cbd3
r 6 bd3
r 6 8bd2
r 6 abd1
r 6 cbd3
r 6 bd2
r 6 2bd3
r 6 5861
r 6 6bcf
r 6 bd2
r 6 2bd3
r 6 5861
r 6 6bd0
r 6 8bd3
r 6 abd2
r 6 cbd3
r 6 6bd0
r 6 8bd3
r 6 r b 256b
a56b
r 6r b 256a
 256a
r b 2569
r b 2569r 6 2bd3
r 6 5861
r 6 abd2
r 6 cbd1
r 6 bd3
r 6 2bd3
r 6 5861
r 6 6bcf
r 6 8bd1
r 6 2bd3
r 6 5861
r 6 6bcf
r 6 8bd1
r 6 abd3
r 6 cbd2
r 6 bd3
r 6 8bd1
r 6 abd3
r 6 cbd2
r 6 bd2
r 6 2bd3
r 6 5861
r 6 6bcf
r 6 bd2
r 6 2bd3
r 6 5861
r 6 6bcf
r 6 8bd3
r 6 abdr b 254c
2
r 6 cbd2r b 254b

r 6 58r b 254a
6a
r 6 6bcf
r 6 8bd3
r 6 abd2
r 6 cbd2
r 6 bd3
r 6 2bd3
r 6 abd2
r 6 cbd2
r 6 bd3
r 6 2bd3
r 6 5861
r 6 6bd0
r 6 8bd3
r 6 2bd3
r 6 5861
r 6 6bd0
r 6 8bd2
r 6 abd3
r 6 cbd1
r 6 bd3
r 6 8bd2
r 6 abd3
r 6 cbd1
r 6 bd2
r 6 2bd1
r 6 5860
r 6 6bd0
r 6 cbd1
r 6 bd2
r 6 2bd1r b 252c

r 6 586r b 252b
0
r 6 6r b 252a
b2a
r 6 8bd1
r 6 abd3
r 6 5860
r 6 6bd0
r 6 8bd1
r 6 abd3
r 6 cbd3
r 6 bd3
r 6 2bd3
r 6 abd3
r 6 cbd3
r 6 bd3
r 6 2bd3
r 6 5860
r 6 6bd0
r 6 8bd1
r 6 2bd3
r 6 5860
r 6 6bd0
r 6 8bd1
r 6 abd3
r 6 cbd3
r 6 bd3
r 6 6bd0
r 6 8bd1
r 6 abd3
r 6 cbd3
r 6 bd4
r 6 2bd3
r 6 5860
r b 250b
r 6 cbd3r b 250b

r 6 bdr b 250a
4ar 6 2bd3
r 6 5860
r 6 6bd1
r 6 8bd3
r 6 abd3
r 6 5860
r 6 6bd1
r 6 8bd3
r 6 abd3
r 6 cbd2
r 6 bd3
r 6 2bd3
r 6 abd3
r 6 cbd2
r 6 bd3
r 6 2bd2
r 6 5861
r 6 6bd0
r 6 8bd3
r 6 bd3
r 6 2bd2
r 6 5861
r 6 6bd0
r 6 8bd2
r 6 abd2
r 6 cbd3
r 6 6bd0
r 6 8bd2
r 6 abd2
r 6 cbd3r b 24ec

r 6 bd2
r 6r b 24ea
 2bd3
r b 24ea
r 6 5861
r 6 cbd3
r 6 bd2
r 6 2bd3
r 6 5861
r 6 6bcf
r 6 8bd3
r 6 abd2
r 6 5861
r 6 6bcf
r 6 8bd3
r 6 abd2
r 6 cbd3
r 6 bd3
r 6 2bd3
r 6 8bd3
r 6 abd2
r 6 cbd3
r 6 bd3
r 6 2bd2
r 6 5860
r 6 6bd0
r 6 bd3
r 6 2bd2
r 6 5860
r 6 6bd0
r 6 8bd1
r 6 abd2
r 6 cbd3
r 6 6bd0
r 6 r b 24cb
84cb
r 6r b 24ca
 24cr b 24ca
a
r 6 cbd3
r 6 bd3
r 6 2bd2
r 6 5861
r 6 cbd3
r 6 bd3
r 6 2bd2
r 6 5861
r 6 6bcf
r 6 8bd0
r 6 abd2
r 6 2bd2
r 6 5861
r 6 6bcf
r 6 8bd0
r 6 abd3
r 6 cbd1
r 6 bd3
r 6 8bd0
r 6 abd3
r 6 cbd1
r 6 bd3
r 6 2bd1
r 6 5861
r 6 6bd0
r 6 bd3
r 6 2bd1
r 6 5861
r 6 6bd0
r 6 8bd2
r b 24ac
r 6 ar b 24ab
bab
r 6r b 24aa
 cbd3
r 6 6bd0
r 6 8bd2
r 6 abd2
r 6 cbd3
r 6 bd2
r 6 2bd3
r 6 5860
r 6 abd2
r 6 cbd3
r 6 bd2
r 6 2bd3
r 6 5860
r 6 6bcf
r 6 8bd1
r 6 2bd3
r 6 5860
r 6 6bcf
r 6 8bd1
r 6 abd3
r 6 cbd2
r 6 bd3
r 6 8bd1
r 6 abd3
r 6 cbd2
r 6 bd3
r 6 2bd2
r 6 5861
r 6 6bd1
r 6 bd3
r 6 2bd2
r b 248c
r 6 58r b 248b
6b
r 6 6r b 248a
b8a
r 6 8bd1
r 6 abd1
r 6 cbd2
r 6 5861
r 6 6bd1
r 6 8bd1
r 6 abd1
r 6 cbd2
r 6 bd2
r 6 2bd3
r 6 abd1
r 6 cbd2
r 6 bd2
r 6 2bd3
r 6 5860
r 6 6bd0
r 6 8bd2
r 6 2bd3
r 6 5860
r 6 6bd0
r 6 8bd2
r 6 abd1
r 6 cbd3
r 6 bd3
r 6 8bd2
r 6 abd1
r 6 cbd3
r 6 bd3
r 6 2bd3
r 6 5861r b 246c

r 6 6br b 246b
db
r 6 r b 246a
c46a
r 6 bd3
r 6 2bd3
r 6 5861
r 6 6bd0
r 6 8bd3
r 6 abd2
r 6 5861
r 6 6bd0
r 6 8bd3
r 6 abd2
r 6 cbd2
r 6 bd2
r 6 2bd3
r 6 abd2
r 6 cbd2
r 6 bd2
r 6 2bd3
r 6 5861
r 6 6bd1
r 6 8bd2
r 6 2bd3
r 6 5861
r 6 6bd1
r 6 8bd2
r 6 abd2
r 6 cbd2
r 6 bd4
r 6 6bcf
r 6 8bd2
r 6 abd2
r 6r b 244b
 cbd2
r 6 bd4r b 244a

r 6 2bdr b 2449
1
r 6 5860
r 6 cbd2
r 6 bd4
r 6 2bd1
r 6 5860
r 6 6bcf
r 6 8bd1
r 6 abd3
r 6 5860
r 6 6bcf
r 6 8bd1
r 6 abd3
r 6 cbd2
r 6 bd3
r 6 2bd2
r 6 abd3
r 6 cbd2
r 6 bd3
r 6 2bd2
r 6 5860
r 6 6bd0
r 6 8bd1
r 6 bd2
r 6 2bd2
r 6 5860
r 6 6bd0
r 6 8bd1
r 6 abd3
r 6 cbd2
r 6 6bd1
r 6 8r b 242a
b2a
r 6 r b 2429
a429
r 6 r b 2428
c428
r 6 bd2
r 6 2bd2
r 6 5861
r 6 cbd2
r 6 bd2
r 6 2bd2
r 6 5861
r 6 6bd1
r 6 8bd1
r 6 abd3
r 6 5861
r 6 6bd1
r 6 8bd1
r 6 abd3
r 6 cbd3
r 6 bd2
r 6 2bd3
r 6 8bd2
r 6 abd3
r 6 cbd3
r 6 bd2
r 6 2bd3
r 6 5860
r 6 6bd0
r 6 bd2
r 6 2bd3
r 6 5860
r 6 6bd0
r 6 8bd2
r 6 abd3
r 6 cbdr b 2409
2
r 6 6bdr b 2408
0
r 6 8bd2
r b 2407
r 6 abd3
r 6 cbd2
r 6 bd2
r 6 2bd3
r 6 5860
r 6 cbd2
r 6 bd2
r 6 2bd3
r 6 5860
r 6 6bd0
r 6 8bd2
r 6 abd2
r 6 2bd4
r 6 5860
r 6 6bd0
r 6 8bd2
r 6 abd2
r 6 cbd2
r 6 bd2
r 6 8bd2
r 6 abd2
r 6 cbd2
r 6 bd2
r 6 2bd4
r 6 585f
r 6 6bd0
r 6 bd3
r 6 2bd4
r 6 585f
r 6 6bd0
r 6 8bd2
r b 23e7
r 6 abd2r b 23e7

r 6 cbd2r b 23e6

r 6 6bd0
r 6 8bd2
r 6 abd2
r 6 cbd2
r 6 bd3
r 6 2bd3
r 6 5860
r 6 abd3
r 6 cbd2
r 6 bd3
r 6 2bd3
r 6 5860
r 6 6bd0
r 6 8bd1
r 6 2bd2
r 6 5860
r 6 6bd0
r 6 8bd1
r 6 abd3
r 6 cbd3
r 6 bd3
r 6 8bd2
r 6 abd3
r 6 cbd3
r 6 bd3
r 6 2bd2
r 6 5861
r 6 6bcf
r 6 bd3
r 6 2bd2
r 6r b 23c7
 23c7
r 6r b 23c6
 23c6
r b 23c5
r 6 8bd2
r 6 abd3
r 6 cbd2
r 6 5860
r 6 6bcf
r 6 8bd2
r 6 abd3
r 6 cbd2
r 6 bd4
r 6 2bd3
r 6 abd3
r 6 cbd2
r 6 bd4
r 6 2bd3
r 6 5860
r 6 6bd0
r 6 8bd2
r 6 2bd3
r 6 5860
r 6 6bd0
r 6 8bd2
r 6 abd3
r 6 cbd2
r 6 bd3
r 6 8bd1
r 6 abd3
r 6 cbd2
r 6 bd3
r 6 2bd3
r 6 5860
r 6 r b 23a7
6bd1
r 6r b 23a6
 cbd1
r 6r b 23a5
 bd3
r 6 2bd3
r 6 5860
r 6 6bd1
r 6 8bd1
r 6 abd2
r 6 5860
r 6 6bd1
r 6 8bd1
r 6 abd2
r 6 cbd1
r 6 bd3
r 6 2bd3
r 6 abd1
r 6 cbd1
r 6 bd3
r 6 2bd3
r 6 5860
r 6 6bcf
r 6 8bd2
r 6 2bd3
r 6 5860
r 6 6bcf
r 6 8bd2
r 6 abd1
r 6 cbd2
r 6 bd1
r 6 6bd0
r 6 8bd2
r 6 abd1
r 6 cbr b 2387
d7
r 6 br b 2386
d86r b 2385
r 6 2bd3
r 6 5860
r 6 cbd2
r 6 bd1
r 6 2bd3
r 6 5860
r 6 6bd0
r 6 8bd1
r 6 abd2
r 6 5861
r 6 6bd0
r 6 8bd1
r 6 abd2
r 6 cbd2
r 6 bd3
r 6 2bd3
r 6 abd2
r 6 cbd2
r 6 bd3
r 6 2bd3
r 6 5861
r 6 6bd0
r 6 8bd2
r 6 bd3
r 6 2bd2
r 6 5861
r 6 6bd0
r 6 8bd2
r 6 abd2
r 6 cbd2
r 6r b 2367
 2367
r 6r b 2366
 2366
r 6r b 2365
 abd2
r 6 cbd2
r 6 bd3
r 6 2bd2
r 6 5861
r 6 cbd1
r 6 bd3
r 6 2bd2
r 6 5861
r 6 6bcf
r 6 8bd2
r 6 abd3
r 6 5860
r 6 6bcf
r 6 8bd2
r 6 abd3
r 6 cbd1
r 6 bd2
r 6 2bd3
r 6 8bd1
r 6 abd1
r 6 cbd1
r 6 bd2
r 6 2bd3
r 6 5860
r 6 6bd0
r 6 bd3
r 6 2bd3
r 6 5860
r 6 6bd0
r 6 8bd1
r b 2347
r 6 abd1
rr b 2345
 b 2345
r b 2345
r 6 6bd0
r 6 8bd1
r 6 abd1
r 6 cbd2
r 6 bd3
r 6 2bd2
r 6 5860
r 6 cbd1
r 6 bd3
r 6 2bd2
r 6 5860
r 6 6bd0
r 6 8bd2
r 6 abd3
r 6 2bd4
r 6 585f
r 6 6bd0
r 6 8bd2
r 6 abd3
r 6 cbd1
r 6 bd3
r 6 8bd2
r 6 abd2
r 6 cbd1
r 6 bd3
r 6 2bd4
r 6 585f
r 6 6bd0
r 6 bd2
r 6 2bd4
r 6r b 2326
 2326
r b 2325
r b 2325
r b 2324
r 6 8bd2
r 6 abd2
r 6 cbd3
r 6 6bd0
r 6 8bd2
r 6 abd2
r 6 cbd3
r 6 bd2
r 6 2bd3
r 6 5860
r 6 abd3
r 6 cbd3
r 6 bd2
r 6 2bd3
r 6 5860
r 6 6bd0
r 6 8bd2
r 6 2bd3
r 6 5860
r 6 6bd0
r 6 8bd2
r 6 abd3
r 6 cbd3
r 6 bd2
r 6 8bd3
r 6 abd3
r 6 cbd3
r 6 bd2
r 6 2bd3
r 6 5860
r r b 2306
6 23r b 2306
06
r 6 r b 2305
b305r 6 2bd3
r 6 5860
r 6 6bd0
r 6 8bd3
r 6 abd3
r 6 cbd2
r 6 5861
r 6 6bd0
r 6 8bd3
r 6 abd3
r 6 cbd2
r 6 bd3
r 6 2bd3
r 6 abd3
r 6 cbd2
r 6 bd3
r 6 2bd3
r 6 5861
r 6 6bd0
r 6 8bd1
r 6 2bd2
r 6 5860
r 6 6bd0
r 6 8bd1
r 6 abd3
r 6 cbd2
r 6 bd3
r 6 8bd2
r 6 abd3
r 6 cr b 22e7
be7
r 6 bd3
r r b 22e5
6 2bd2
r b 22e4
r 6 5860
r 6 6bcf
r 6 cbd2
r 6 bd3
r 6 2bd2
r 6 5860
r 6 6bcf
r 6 8bd2
r 6 abd3
r 6 5860
r 6 6bd0
r 6 8bd2
r 6 abd3
r 6 cbd2
r 6 bd3
r 6 2bd3
r 6 abd3
r 6 cbd1
r 6 bd3
r 6 2bd3
r 6 5860
r 6 6bd0
r 6 8bd2
r 6 2bd3
r 6 5860
r 6 6bd0
r 6 8bd2
r 6 abd3
r 6 cbd1
r 6 bd2
r 6 r b 22c6
62c6
r 6r b 22c5
 8bd1
r b 22c4
r 6 abd3
r 6 cbd1
r 6 bd2
r 6 2bd3
r 6 5861
r 6 cbd3
r 6 bd2
r 6 2bd3
r 6 5861
r 6 6bd0
r 6 8bd1
r 6 abd3
r 6 5861
r 6 6bd0
r 6 8bd1
r 6 abd3
r 6 cbd3
r 6 bd2
r 6 2bd3
r 6 abd2
r 6 cbd1
r 6 bd2
r 6 2bd3
r 6 5861
r 6 6bd0
r 6 8bd2
r 6 bd3
r 6 2bd2
r 6 5861
r 6 6bd0
r 6r b 22a6
 22ar b 22a6
6
r 6 ar b 22a5
ba5
r 6 cbd1
r 6 6bcf
r 6 8bd2
r 6 abd2
r 6 cbd1
r 6 bd3
r 6 2bd2
r 6 5861
r 6 cbd3
r 6 bd2
r 6 2bd2
r 6 5861
r 6 6bcf
r 6 8bd2
r 6 abd2
r 6 5861
r 6 6bcf
r 6 8bd2
r 6 abd2
r 6 cbd3
r 6 bd2
r 6 2bd3
r 6 8bd2
r 6 abd3
r 6 cbd3
r 6 bd2
r 6 2bd3
r 6 5861
r 6 6bcf
r 6 bd2
r b 2286
r 6 r b 2286
2286
r 6 5861r b 2285
rr 6 6bcf
r 6 8bd2
r 6 abd3
r 6 cbd2
r 6 6bd0
r 6 8bd2
r 6 abd3
r 6 cbd2
r 6 bd2
r 6 2bd3
r 6 5860
r 6 cbd2
r 6 bd3
r 6 2bd3
r 6 5860
r 6 6bd0
r 6 8bd2
r 6 abd2
r 6 2bd2
r 6 585f
r 6 6bd0
r 6 8bd2
r 6 abd2
r 6 cbd2
r 6 bd3
r 6 8bd2
r 6 abd3
r 6 cbd2
r 6 bd3
r 6 2bd2
r 6r b 2266
 585f
r b 2265
r 6 6bd0
r b 2264
r 6 bd3
r 6 2bd3
r 6 585f
r 6 6bd0
r 6 8bd2
r 6 abd3
r 6 cbd1
r 6 6bd0
r 6 8bd2
r 6 abd3
r 6 cbd1
r 6 bd3
r 6 2bd3
r 6 5860
r 6 abd2
r 6 cbd3
r 6 bd1
r 6 2bd3
r 6 5860
r 6 6bd0
r 6 8bd2
r 6 2bd3
r 6 5860
r 6 6bd0
r 6 8bd2
r 6 abd2
r 6 cbd3
r 6 bd1
r 6 8bd1
r 6 abd2
r 6r b 2246
 2246
r 6r b 2245
 bd1
r b 2244
r 6 2bd3
r 6 5860
r 6 6bd0
r 6 bd2
r 6 2bd2
r 6 5860
r 6 6bd0
r 6 8bd1
r 6 abd2
r 6 cbd1
r 6 5860
r 6 6bd0
r 6 8bd2
r 6 abd2
r 6 cbd1
r 6 bd2
r 6 2bd2
r 6 abd3
r 6 cbd2
r 6 bd3
r 6 2bd2
r 6 5860
r 6 6bd0
r 6 8bd2
r 6 2bd4
r 6 5860
r 6 6bd0
r 6 8bd2
r 6 abd3
r 6 cbd2
r 6 bd3
r b 2225
r 6 8bd2
r r b 2224
6 abd2
r b 2224
r 6 cbd2
r 6 bd3
r 6 2bd4
r 6 5860
r 6 6bcf
r 6 cbd2
r 6 bd3
r 6 2bd3
r 6 5860
r 6 6bcf
r 6 8bd2
r 6 abd2
r 6 5861
r 6 6bd0
r 6 8bd2
r 6 abd2
r 6 cbd2
r 6 bd3
r 6 2bd3
r 6 abd2
r 6 cbd1
r 6 bd3
r 6 2bd3
r 6 5861
r 6 6bd0
r 6 8bd2
r 6 2bd3
r 6 5861
r 6 6bd0
r 6 8bd2
r b 2205
r 6 abd2
r 6 r b 2204
c204
r 6 bd3r b 2203

r 6 6bd0
r 6 8bd2
r 6 abd2
r 6 cbd1
r 6 bd3
r 6 2bd3
r 6 5861
r 6 cbd2
r 6 bd3
r 6 2bd2
r 6 5861
r 6 6bd0
r 6 8bd2
r 6 abd2
r 6 5860
r 6 6bd0
r 6 8bd1
r 6 abd2
r 6 cbd2
r 6 bd3
r 6 2bd2
r 6 abd2
r 6 cbd2
r 6 bd3
r 6 2bd2
r 6 5860
r 6 6bd0
r 6 8bd1
r 6 bd2
r 6 2bd2
r 6 r b 21e4
51e4r b 21e4

r 6 6bdr b 21e3
0
r 6 8bd1
r 6 abd2
r 6 cbd2
r 6 6bd0
r 6 8bd2
r 6 abd3
r 6 cbd2
r 6 bd2
r 6 2bd2
r 6 5860
r 6 cbd3
r 6 bd2
r 6 2bd3
r 6 5860
r 6 6bd0
r 6 8bd2
r 6 abd3
r 6 5860
r 6 6bd0
r 6 8bd2
r 6 abd3
r 6 cbd3
r 6 bd2
r 6 2bd3
r 6 8bd3
r 6 abd2
r 6 cbd2
r 6 bd2
r 6 2bd3
r 6 5860
r 6 6r b 21c4
bc4
r 6 bdr b 21c3
23r 6 r b 21c2
21c2
r 6 5860
r 6 6bd0
r 6 8bd3
r 6 abd2
r 6 cbd2
r 6 6bd0
r 6 8bd2
r 6 abd2
r 6 cbd2
r 6 bd2
r 6 2bd3
r 6 5860
r 6 cbd2
r 6 bd2
r 6 2bd1
r 6 5860
r 6 6bd0
r 6 8bd2
r 6 abd2
r 6 2bd1
r 6 5861
r 6 6bd0
r 6 8bd2
r 6 abd2
r 6 cbd2
r 6 bd2
r 6 8bd1
r 6 abd2
r 6 cbd1
r 6 bd2
r 6 2bd1
r 6r b 21a2
 5861
r 6 6r b 21a1
ba1
r b 21a1
r 6 bd3
r 6 2bd3
r 6 5860
r 6 6bd0
r 6 8bd1
r 6 abd2
r 6 cbd1
r 6 6bd1
r 6 8bd2
r 6 abd2
r 6 cbd1
r 6 bd3
r 6 2bd3
r 6 5860
r 6 abd2
r 6 cbd2
r 6 bd2
r 6 2bd3
r 6 5860
r 6 6bd1
r 6 8bd2
r 6 2bd3
r 6 5860
r 6 6bd0
r 6 8bd2
r 6 abd2
r 6 cbd2
r 6 bd2
r 6 8bd2
r 6 abd2
r 6 cbd3
r 6 bdr b 2181
21r 6 2bd3r b 2180

r 6 r b 217f
517f
r 6 6bd0
r 6 bd2
r 6 2bd3
r 6 5860
r 6 6bd0
r 6 8bd2
r 6 abd2
r 6 cbd3
r 6 5860
r 6 6bd0
r 6 8bd2
r 6 abd3
r 6 cbd3
r 6 bd2
r 6 2bd3
r 6 abd3
r 6 cbd2
r 6 bd4
r 6 2bd3
r 6 5860
r 6 6bd0
r 6 8bd2
r 6 2bd2
r 6 5860
r 6 6bd1
r 6 8bd2
r 6 abd3
r 6 cbd2
r 6 bd4
r 6 8bd2
r 6 abd3r b 2160

r 6 cr b 215f
b5f
r 6 br b 215e
d5er 6 2bd2
r 6 5860
r 6 6bd1
r 6 cbd3
r 6 bd3
r 6 2bd3
r 6 5861
r 6 6bd1
r 6 8bd2
r 6 abd3
r 6 5861
r 6 6bcf
r 6 8bd1
r 6 abd3
r 6 cbd3
r 6 bd3
r 6 2bd3
r 6 abd2
r 6 cbd2
r 6 bd3
r 6 2bd3
r 6 5861
r 6 6bcf
r 6 8bd1
r 6 2bd3
r 6 5860
r 6 6bd1
r 6 8bd1
r 6 abd2
r 6 cbd2
r 6r b 213f
 213fr 6 6bd1r b 213e

r 6 8br b 213d
dd
r 6 abd3
r 6 cbd2
r 6 bd3
r 6 2bd3
r 6 5860
r 6 cbd2
r 6 bd1
r 6 2bd3
r 6 5860
r 6 6bd1
r 6 8bd1
r 6 abd3
r 6 5860
r 6 6bd0
r 6 8bd2
r 6 abd3
r 6 cbd2
r 6 bd1
r 6 2bd3
r 6 abd2
r 6 cbd3
r 6 bd3
r 6 2bd3
r 6 5860
r 6 6bd0
r 6 8bd2
r 6 bd3
r 6 2bd2
r 6 585f
r 6 6bd0
r 6r b 211e
 8bd2r b 211e

r 6 abdr b 211d
2
r 6 cbd3
r 6 6bd0
r 6 8bd2
r 6 abd3
r 6 cbd3
r 6 bd3
r 6 2bd2
r 6 585f
r 6 cbd3
r 6 bd2
r 6 2bd3
r 6 585f
r 6 6bd0
r 6 8bd2
r 6 abd3
r 6 5861
r 6 6bcf
r 6 8bd2
r 6 abd3
r 6 cbd3
r 6 bd2
r 6 2bd3
r 6 8bd2
r 6 abd3
r 6 cbd3
r 6 bd3
r 6 2bd3
r 6 5861
r 6 6bcf
r 6 bd3
r 6 2bd2
r b 20fd
r 6 5r b 20fd
8fd
r 6r b 20fc
 20fc
r 6 8bd2
r 6 abd3
r 6 cbd3
r 6 6bcf
r 6 8bd1
r 6 abd2
r 6 cbd2
r 6 bd3
r 6 2bd2
r 6 5860
r 6 cbd2
r 6 bd2
r 6 2bd2
r 6 5860
r 6 6bcf
r 6 8bd1
r 6 abd2
r 6 2bd2
r 6 5860
r 6 6bd0
r 6 8bd1
r 6 abd2
r 6 cbd2
r 6 bd2
r 6 8bd1
r 6 abd2
r 6 cbd2
r 6 bd3
r 6 2bd2
r 6 5r b 20de
8de
r 6 6bdr b 20dd
0
r 6 r b 20dc
b0dcr 6 2bd3
r 6 5860
r 6 6bd1
r 6 8bd1
r 6 abd2
r 6 cbd2
r 6 6bd1
r 6 8bd2
r 6 abd3
r 6 cbd2
r 6 bd3
r 6 2bd3
r 6 5860
r 6 abd3
r 6 cbd2
r 6 bd2
r 6 2bd3
r 6 5860
r 6 6bd1
r 6 8bd2
r 6 2bd3
r 6 5861
r 6 6bd0
r 6 8bd3
r 6 abd3
r 6 cbd2
r 6 bd2
r 6 8bd3
r 6 abd2
r 6 cr b 20be
bbe
r 6 br b 20bd
dbdr 6 2bdr b 20bc
3
r 6 5861
r 6 6bd0
r 6 bd2
r 6 2bd3
r 6 5860
r 6 6bd0
r 6 8bd3
r 6 abd2
r 6 cbd2
r 6 5860
r 6 6bd0
r 6 8bd3
r 6 abd3
r 6 cbd2
r 6 bd2
r 6 2bd3
r 6 abd3
r 6 cbd3
r 6 bd3
r 6 2bd2
r 6 5860
r 6 6bd0
r 6 8bd3
r 6 2bd2
r 6 5861
r 6 6bd1
r 6 8bd2
r 6 abd3
r 6 cbd3
r 6 bd3
r 6 r b 209d
809d
r 6 abr b 209c
dc
r 6r b 209b
 209b
r 6 bd4
r 6 2bd2
r 6 5861
r 6 6bd1
r 6 cbd2
r 6 bd4
r 6 2bd1
r 6 5860
r 6 6bd1
r 6 8bd2
r 6 abd2
r 6 5860
r 6 6bcf
r 6 8bd2
r 6 abd3
r 6 cbd2
r 6 bd4
r 6 2bd1
r 6 abd3
r 6 cbd3
r 6 bd3
r 6 2bd3
r 6 5860
r 6 6bcf
r 6 8bd2
r 6 2bd3
r 6 5860
r 6 6bd0
r 6 8bd1
r 6 abd3
r 6 cbd3r b 207c

r 6 bdr b 207b
3br 6 6br b 207a
da
r 6 8bd1
r 6 abd3
r 6 cbd2
r 6 bd2
r 6 2bd3
r 6 5860
r 6 cbd2
r 6 bd2
r 6 2bd3
r 6 5860
r 6 6bd0
r 6 8bd1
r 6 abd3
r 6 5860
r 6 6bd0
r 6 8bd1
r 6 abd2
r 6 cbd2
r 6 bd2
r 6 2bd3
r 6 abd2
r 6 cbd3
r 6 bd3
r 6 2bd3
r 6 5860
r 6 6bd0
r 6 8bd1
r 6 bd3
r 6 2bd3
r 6 58r b 205c
6c
r 6 r b 205b
6bd1
r b 205a
r 6 8bd2
r 6 abd2
r 6 cbd3
r 6 6bd1
r 6 8bd2
r 6 abd2
r 6 cbd2
r 6 bd3
r 6 2bd3
r 6 5860
r 6 cbd2
r 6 bd3
r 6 2bd4
r 6 5860
r 6 6bd1
r 6 8bd2
r 6 abd2
r 6 5860
r 6 6bd0
r 6 8bd3
r 6 abd3
r 6 cbd2
r 6 bd3
r 6 2bd4
r 6 8bd3
r 6 abd3
r 6 cbd1
r 6 bd3
r 6 2bd3
r 6 5860
r 6 6bd0
r r b 203b
6 203br 6 r b 203a
203a
r 6 5r b 2039
839
r 6 6bd0
r 6 8bd1
r 6 abd3
r 6 cbd1
r 6 6bd0
r 6 8bd1
r 6 abd2
r 6 cbd1
r 6 bd3
r 6 2bd3
r 6 5861
r 6 cbd1
r 6 bd2
r 6 2bd3
r 6 5861
r 6 6bd0
r 6 8bd1
r 6 abd2
r 6 2bd3
r 6 5861
r 6 6bd0
r 6 8bd1
r 6 abd2
r 6 cbd1
r 6 bd2
r 6 8bd1
r 6 abd2
r 6 cbd3
r 6 bd2
r 6 2bd4
r 6 5861
r 6 6bd0
r 6 bd2
r b 2017
r 6 2bd4
r b 2017
r 6 5860
r 6r b 2015
 2015
r 6 8bd1
r 6 abd2
r 6 cbd3
r 6 6bd0
r 6 8bd2
r 6 abd3
r 6 cbd1
r 6 bd2
r 6 2bd4
r 6 5860
r 6 abd3
r 6 cbd1
r 6 bd3
r 6 2bd3
r 6 5861
r 6 6bd0
r 6 8bd2
r 6 2bd3
r 6 5861
r 6 6bcf
r 6 8bd3
r 6 abd1
r 6 cbd1
r 6 bd3
r 6 8bd3
r 6 abd1
r 6 cbd2
r 6 bd2
r 6 2bd1
r 6 5861
r 6 6bcf
r 6 bd2
r 6 2r b 1ff4
bf4
r 6 586r b 1ff3
0
r 6 6bce
r b 1ff1
r 6 8bd3
r 6 abd1
r 6 cbd2
r 6 5860
r 6 6bce
r 6 8bd2
r 6 abd2
r 6 cbd2
r 6 bd2
r 6 2bd1
r 6 abd2
r 6 cbd2
r 6 bd3
r 6 2bd4
r 6 5860
r 6 6bce
r 6 8bd2
r 6 2bd4
r 6 5860
r 6 6bd0
r 6 8bd1
r 6 abd4
r 6 cbd2
r 6 bd3
r 6 8bd1
r 6 abd4
r 6 cbd2
r 6 bd3
r 6 2bd4
r 6 5860
r 6 6bd0
r 6 cbd2
r 6r b 1fd1
 1fd1r 6 2br b 1fd0
d0
r 6 5860
r r b 1fce
6 6bd0
r 6 8bd1
r 6 abd4
r 6 5860
r 6 6bd0
r 6 8bd1
r 6 abd1
r 6 cbd2
r 6 bd3
r 6 2bd3
r 6 abd1
r 6 cbd2
r 6 bd1
r 6 2bd3
r 6 5860
r 6 6bd0
r 6 8bd1
r 6 2bd3
r 6 5860
r 6 6bd0
r 6 8bd1
r 6 abd2
r 6 cbd2
r 6 bd1
r 6 6bd0
r 6 8bd1
r 6 abd2
r 6 cbd3
r 6 bd2
r 6 2bd3
r 6 5860
r 6 cbd3
r 6 bd2r b 1fae

r 6 2bd3r b 1fad

r 6 5861
r b 1fac
r 6 6bd0
r 6 8bd1
r 6 abd2
r 6 5861
r 6 6bd0
r 6 8bd2
r 6 abd2
r 6 cbd2
r 6 bd2
r 6 2bd3
r 6 abd2
r 6 cbd2
r 6 bd2
r 6 2bd2
r 6 5860
r 6 6bd0
r 6 8bd2
r 6 bd2
r 6 2bd2
r 6 5860
r 6 6bcf
r 6 8bd3
r 6 abd2
r 6 cbd2
r 6 6bcf
r 6 8bd3
r 6 abd3
r 6 cbd1
r 6 bd4
r 6 2bd2
r 6 5860
r 6 cbd1
r 6 bd4r b 1f8b

r 6 2r b 1f8a
b8a
r 6 5r b 1f89
889
r 6 6bd0
r 6 8bd3
r 6 abd3
r 6 5861
r 6 6bd0
r 6 8bd2
r 6 abd2
r 6 cbd2
r 6 bd4
r 6 2bd3
r 6 8bd2
r 6 abd2
r 6 cbd2
r 6 bd2
r 6 2bd3
r 6 5861
r 6 6bd0
r 6 bd2
r 6 2bd3
r 6 5861
r 6 6bd0
r 6 8bd2
r 6 abd2
r 6 cbd2
r 6 6bd0
r 6 8bd2
r 6 abd1
r 6 cbd2
r 6 bd1
r 6 2bd3
r 6 586r b 1f6a
1
r 6 cbdr b 1f69
2
r 6 br b 1f68
d68r 6 2bd3
r 6 5860
r 6 6bd0
r 6 8bd2
r 6 abd1
r 6 2bd3
r 6 5860
r 6 6bd0
r 6 8bd1
r 6 abd3
r 6 cbd2
r 6 bd1
r 6 8bd1
r 6 abd3
r 6 cbd2
r 6 bd2
r 6 2bd4
r 6 5860
r 6 6bd0
r 6 bd2
r 6 2bd4
r 6 5860
r 6 6bd0
r 6 8bd3
r 6 abd3
r 6 cbd2
r 6 6bd0
r 6 8bd3
r 6 abd3
r 6 cbdr b 1f4a
2
r 6 bd3
r r b 1f48
6 2bd4
r b 1f47
r b 1f47
r 6 abd3
r 6 cbd2
r 6 bd3
r 6 2bd2
r 6 5860
r 6 6bd0
r 6 8bd3
r 6 2bd2
r 6 5860
r 6 6bd0
r 6 8bd2
r 6 abd3
r 6 cbd2
r 6 bd3
r 6 8bd2
r 6 abd3
r 6 cbd2
r 6 bd3
r 6 2bd3
r 6 5860
r 6 6bd0
r 6 bd3
r 6 2bd3
r 6 5860
r 6 6bd1
r 6 8bd2
r 6 abd3
r 6 cbd2
r 6 5860
r 6 r b 1f29
6f29
r 6 r b 1f28
8f28
r 6r b 1f27
 1f27
r 6 cbd3
r 6 bd2
r 6 2bd3
r 6 abd3
r 6 cbd3
r 6 bd2
r 6 2bd4
r 6 5860
r 6 6bd0
r 6 8bd2
r 6 2bd4
r 6 5860
r 6 6bd0
r 6 8bd1
r 6 abd2
r 6 cbd3
r 6 bd2
r 6 8bd1
r 6 abd2
r 6 cbd1
r 6 bd2
r 6 2bd2
r 6 5860
r 6 6bd0
r 6 cbd1
r 6 bd2
r 6 2bd2
r 6 5861
r 6 6bd0
r 6 8bd3
r b 1f09
r 6 abd2
r b 1f08
r 6 5r b 1f07
807
r 6 6bd0
r 6 8bd3
r 6 abd1
r 6 cbd3
r 6 bd2
r 6 2bd2
r 6 abd1
r 6 cbd3
r 6 bd2
r 6 2bd3
r 6 5860
r 6 6bd0
r 6 8bd3
r 6 2bd3
r 6 5860
r 6 6bd0
r 6 8bd2
r 6 abd3
r 6 cbd3
r 6 bd2
r 6 6bd0
r 6 8bd2
r 6 abd3
r 6 cbd2
r 6 bd3
r 6 2bd2
r 6 5860
r 6 cbd2
r 6 bd3
r 6 2bd2
r 6r b 1ee8
 1ee8
r 6r b 1ee7
 1ee7
r 6r b 1ee6
 1ee6
r 6 abd3
r 6 5861
r 6 6bcf
r 6 8bd1
r 6 abd2
r 6 cbd1
r 6 bd2
r 6 2bd2
r 6 abd2
r 6 cbd1
r 6 bd2
r 6 2bd2
r 6 5860
r 6 6bcf
r 6 8bd1
r 6 bd2
r 6 2bd2
r 6 5860
r 6 6bd0
r 6 8bd2
r 6 abd3
r 6 cbd1
r 6 6bd0
r 6 8bd2
r 6 abd3
r 6 cbd3
r 6 bd3
r 6 2bd4
r 6 5860
r 6 cbd3
r b 1ec7
r 6 bd3
r 6 r b 1ec6
2bd4
r 6 5r b 1ec5
8c5
r 6 6bd0
r 6 8bd3
r 6 abd3
r 6 5860
r 6 6bd0
r 6 8bd3
r 6 abd3
r 6 cbd4
r 6 bd4
r 6 2bd4
r 6 8bd3
r 6 abd3
r 6 cbd4
r 6 bd4
r 6 2bd3
r 6 5861
r 6 6bd0
r 6 bd4
r 6 2bd3
r 6 5861
r 6 6bd0
r 6 8bd2
r 6 abd2
r 6 cbd4
r 6 6bd0
r 6 8bd2
r 6 abd2
r 6 cbd2
r 6 bd3
r 6 2bd3
r 6 58r b 1ea6
66
r 6 cbr b 1ea5
d5
r 6r b 1ea4
 1ea4r 6 2bd3
r 6 5861
r 6 6bd0
r 6 8bd2
r 6 abd2
r 6 2bd3
r 6 5861
r 6 6bd0
r 6 8bd2
r 6 abd3
r 6 cbd2
r 6 bd3
r 6 8bd2
r 6 abd3
r 6 cbd2
r 6 bd3
r 6 2bd3
r 6 5860
r 6 6bd0
r 6 bd3
r 6 2bd3
r 6 5860
r 6 6bd0
r 6 8bd2
r 6 abd3
r 6 cbd2
r 6 6bd0
r 6 8bd2
r 6 abd3
r 6 cr b 1e86
b86
r 6 bdr b 1e85
25r 6 2br b 1e84
d4
r 6 5860
r 6 abd3
r 6 cbd2
r 6 bd2
r 6 2bd3
r 6 5860
r 6 6bd0
r 6 8bd1
r 6 2bd3
r 6 5860
r 6 6bd0
r 6 8bd1
r 6 abd3
r 6 cbd3
r 6 bd2
r 6 8bd1
r 6 abd3
r 6 cbd3
r 6 bd1
r 6 2bd3
r 6 5860
r 6 6bd0
r 6 bd1
r 6 2bd3
r 6 5860
r 6 6bcf
r 6 8bd3
r 6 abd2
r 6 cbd3
r 6 5860
r 6 6bcf
r 6 8bd3
r b 1e64
r 6 abd2
r b 1e63
r 6 cbr b 1e62
d2
r 6 bd4
r 6 2bd3
r 6 abd2
r 6 cbd1
r 6 bd4
r 6 2bd3
r 6 5861
r 6 6bd0
r 6 8bd3
r 6 2bd3
r 6 5861
r 6 6bd0
r 6 8bd3
r 6 abd2
r 6 cbd2
r 6 bd4
r 6 8bd3
r 6 abd2
r 6 cbd2
r 6 bd3
r 6 2bd3
r 6 5861
r 6 6bd0
r 6 cbd2
r 6 bd3
r 6 2bd3
r 6 5861
r 6 6bd0
r 6 8bd2
r 6 abd3
r 6 5861
r r b 1e42
b 1e42r b 1e42

r 6 r b 1e41
8e41
r 6 abd3
r 6 cbd1
r 6 bd2
r 6 2bd2
r 6 abd3
r 6 cbd1
r 6 bd2
r 6 2bd2
r 6 5860
r 6 6bd1
r 6 8bd2
r 6 2bd2
r 6 5860
r 6 6bd1
r 6 8bd1
r 6 abd3
r 6 cbd2
r 6 bd2
r 6 6bd1
r 6 8bd1
r 6 abd3
r 6 cbd2
r 6 bd3
r 6 2bd3
r 6 5861
r 6 cbd2
r 6 bd3
r 6 2bd3
r 6 5861
r 6 6bd0
r 6 8br b 1e22
d2
r 6 abr b 1e21
d1
r 6 58r b 1e20
60
r 6 6bd0
r 6 8bd3
r 6 abd1
r 6 cbd3
r 6 bd3
r 6 2bd3
r 6 abd1
r 6 cbd3
r 6 bd3
r 6 2bd3
r 6 5861
r 6 6bcf
r 6 8bd3
r 6 bd3
r 6 2bd3
r 6 5861
r 6 6bcf
r 6 8bd3
r 6 abd2
r 6 cbd2
r 6 6bcf
r 6 8bd3
r 6 abd2
r 6 cbd2
r 6 bd3
r 6 2bd3
r 6 5860
r 6 cbd2
r 6 bd3
r 6 2bd3
r 6 5860r b 1e01

r 6 6bd0
r 6r b 1dff
 1dfr b 1dff
f
r 6 abd3
r 6 5860
r 6 6bd0
r 6 8bd2
r 6 abd3
r 6 cbd3
r 6 bd4
r 6 2bd3
r 6 8bd2
r 6 abd3
r 6 cbd3
r 6 bd4
r 6 2bd3
r 6 5860
r 6 6bd0
r 6 bd4
r 6 2bd3
r 6 5860
r 6 6bd0
r 6 8bd2
r 6 abd3
r 6 cbd2
r 6 6bd0
r 6 8bd2
r 6 abd3
r 6 cbd2
r 6 bd1
r 6 2bd3
r 6 5860
r 6 cbd2
r 6 bd1r b 1de0

r 6 2r b 1ddf
bdf
r 6r b 1dde
 1dde
r 6 6bd0
r 6 8bd2
r 6 abd3
r 6 2bd3
r 6 5860
r 6 6bd0
r 6 8bd2
r 6 abd1
r 6 cbd2
r 6 bd2
r 6 8bd2
r 6 abd1
r 6 cbd2
r 6 bd2
r 6 2bd3
r 6 5860
r 6 6bd0
r 6 bd2
r 6 2bd3
r 6 5860
r 6 6bd0
r 6 8bd2
r 6 abd1
r 6 cbd2
r 6 6bd0
r 6 8bd2
r 6 abd1
r 6 cbd2
r 6 bd2
r 6 2bd3
r 6r b 1dbf
 1dbf
r 6 r b 1dbe
adbe
r 6r b 1dbd
 1dbd
r 6 bd2
r 6 2bd3
r 6 5860
r 6 6bcf
r 6 8bd2
r 6 2bd3
r 6 5860
r 6 6bcf
r 6 8bd2
r 6 abd2
r 6 cbd2
r 6 bd4
r 6 8bd2
r 6 abd2
r 6 cbd2
r 6 bd4
r 6 2bd3
r 6 5860
r 6 6bd1
r 6 bd4
r 6 2bd3
r 6 5860
r 6 6bd1
r 6 8bd3
r 6 abd3
r 6 cbd3
r 6 5860
r 6 6bd1
r 6 8bd3
r 6 abd3
r 6r b 1d9e
 1d9e
r 6r b 1d9d
 bd3
r 6r b 1d9c
 2bd3
r 6 abd3
r 6 cbd3
r 6 bd3
r 6 2bd3
r 6 5860
r 6 6bd0
r 6 8bd2
r 6 2bd3
r 6 5860
r 6 6bd0
r 6 8bd2
r 6 abd3
r 6 cbd2
r 6 bd2
r 6 8bd2
r 6 abd3
r 6 cbd2
r 6 bd2
r 6 2bd3
r 6 5860
r 6 6bd0
r 6 cbd3
r 6 bd2
r 6 2bd3
r 6 5860
r 6 6bd0
r 6 8bd2
r 6 abd2
r 6 5860
r 6 r b 1d7e
6d7e
r 6 8bdr b 1d7d
2
r 6 abd2
r 6 r b 1d7b
cbd3
r 6 bd3
r 6 2bd2
r 6 abd2
r 6 cbd3
r 6 bd3
r 6 2bd2
r 6 5861
r 6 6bcf
r 6 8bd3
r 6 2bd2
r 6 5861
r 6 6bcf
r 6 8bd3
r 6 abd2
r 6 cbd3
r 6 bd3
r 6 6bd1
r 6 8bd3
r 6 abd2
r 6 cbd3
r 6 bd3
r 6 2bd2
r 6 5861
r 6 cbd3
r 6 bd3
r 6 2bd2
r 6 5861
r 6 6bd1
r 6 8bd2
r 6 abd2
r 6 r b 1d5c
5d5c
r 6 6r b 1d5b
b5b
r 6r b 1d5a
 1d5a
r 6 abd2
r 6 cbd2
r 6 bd2
r 6 2bd3
r 6 abd2
r 6 cbd2
r 6 bd2
r 6 2bd3
r 6 5861
r 6 6bd0
r 6 8bd1
r 6 bd1
r 6 2bd3
r 6 5861
r 6 6bd0
r 6 8bd1
r 6 abd2
r 6 cbd2
r 6 6bd0
r 6 8bd1
r 6 abd2
r 6 cbd2
r 6 bd1
r 6 2bd3
r 6 5861
r 6 cbd2
r 6 bd1
r 6 2bd3
r 6 5861
r 6 6bd0
r b 1d3b
r 6 8bd3
r b 1d3b
r 6 abd3
r b 1d3a
r 6 5861
r 6 6bd0
r 6 8bd3
r 6 abd3
r 6 cbd3
r 6 bd2
r 6 2bd3
r 6 8bd1
r 6 abd3
r 6 cbd3
r 6 bd2
r 6 2bd3
r 6 5860
r 6 6bd0
r 6 bd3
r 6 2bd3
r 6 5860
r 6 6bd0
r 6 8bd1
r 6 abd2
r 6 cbd1
r 6 6bd0
r 6 8bd1
r 6 abd2
r 6 cbd1
r 6 bd3
r 6 2bd2
r 6 5860
r 6 cbd1
r 6 bd3
r r b 1d1b
6 1d1br b 1d1b

r 6 58r b 1d1a
1a
r 6 6bd0
r 6 8bd1
r 6 abd2
r 6 2bd3
r 6 5860
r 6 6bd0
r 6 8bd1
r 6 abd2
r 6 cbd3
r 6 bd3
r 6 8bd2
r 6 abd2
r 6 cbd3
r 6 bd3
r 6 2bd3
r 6 5861
r 6 6bd0
r 6 bd3
r 6 2bd3
r 6 5861
r 6 6bd0
r 6 8bd2
r 6 abd2
r 6 cbd2
r 6 6bd0
r 6 8bd2
r 6 abd2
r 6 cbd2
r 6 bd3
r 6 2bdr b 1cfc
4
r 6 5r b 1cfb
8fb
r 6 ar b 1cfa
bfa
r 6 cbd2
r 6 bd3
r 6 2bd4
r 6 5860
r 6 6bd1
r 6 8bd2
r 6 2bd2
r 6 5860
r 6 6bd1
r 6 8bd2
r 6 abd3
r 6 cbd2
r 6 bd3
r 6 8bd2
r 6 abd3
r 6 cbd2
r 6 bd3
r 6 2bd2
r 6 5860
r 6 6bcf
r 6 bd3
r 6 2bd2
r 6 5860
r 6 6bcf
r 6 8bd2
r 6 abd2
r 6 cbd1
r 6 5860
r 6 6bcf
r 6 8bd2
r 6 r b 1cdb
acdb
r 6r b 1cda
 cbd1
r 6r b 1cd9
 1cd9r 6 2bd2
r 6 abd2
r 6 cbd1
r 6 bd2
r 6 2bd2
r 6 5860
r 6 6bcf
r 6 8bd1
r 6 2bd3
r 6 5860
r 6 6bcf
r 6 8bd1
r 6 abd2
r 6 cbd2
r 6 bd3
r 6 8bd1
r 6 abd2
r 6 cbd2
r 6 bd3
r 6 2bd3
r 6 5861
r 6 6bd1
r 6 cbd2
r 6 bd3
r 6 2bd3
r 6 5861
r 6 6bd1
r 6 8bd1
r 6 abd3
r 6 58r b 1cbb
6b
r 6 6r b 1cba
bba
r 6r b 1cb9
 1cb9
r 6 abd3
r 6 cbd2
r 6 bd3
r 6 2bd2
r 6 abd2
r 6 cbd2
r 6 bd3
r 6 2bd2
r 6 5860
r 6 6bd0
r 6 8bd1
r 6 2bd3
r 6 5860
r 6 6bd0
r 6 8bd1
r 6 abd2
r 6 cbd2
r 6 bd3
r 6 6bd0
r 6 8bd1
r 6 abd2
r 6 cbd2
r 6 bd3
r 6 2bd3
r 6 5860
r 6 cbd3
r 6 bd3
r 6 2bd3
r 6 5860
r 6 r b 1c9b
6c9b
r b 1c9a
r 6 8bd1r b 1c9a

r 6 abd3
r 6 5860
r 6 6bd0
r 6 8bd1
r 6 abd3
r 6 cbd3
r 6 bd3
r 6 2bd1
r 6 abd2
r 6 cbd3
r 6 bd3
r 6 2bd1
r 6 5860
r 6 6bce
r 6 8bd2
r 6 bd3
r 6 2bd3
r 6 5860
r 6 6bce
r 6 8bd2
r 6 abd2
r 6 cbd2
r 6 6bd0
r 6 8bd2
r 6 abd2
r 6 cbd2
r 6 bd3
r 6 2bd3
r 6 5861
r 6 cbd2
r 6 bd3
r 6 2br b 1c7a
da
r 6r b 1c79
 1c79
r 6r b 1c78
 6bd0
r 6 8bd1
r 6 abd2
r 6 5860
r 6 6bd0
r 6 8bd1
r 6 abd2
r 6 cbd2
r 6 bd2
r 6 2bd3
r 6 8bd1
r 6 abd1
r 6 cbd2
r 6 bd2
r 6 2bd3
r 6 5860
r 6 6bd1
r 6 bd3
r 6 2bd3
r 6 5860
r 6 6bd1
r 6 8bd1
r 6 abd1
r 6 cbd2
r 6 6bd0
r 6 8bd1
r 6 abd1
r 6 cbd2
r 6 bd3
r 6 2bd2
r 6 5861
r r b 1c59
b 1c59
r 6r b 1c58
 bd3r b 1c58

r 6 2bd2
r 6 5861
r 6 6bd0
r 6 8bd2
r 6 abd2
r 6 2bd3
r 6 5861
r 6 6bd0
r 6 8bd2
r 6 abd2
r 6 cbd2
r 6 bd3
r 6 8bd1
r 6 abd3
r 6 cbd2
r 6 bd3
r 6 2bd3
r 6 5861
r 6 6bd0
r 6 bd4
r 6 2bd3
r 6 5861
r 6 6bd0
r 6 8bd1
r 6 abd3
r 6 cbd1
r 6 6bd0
r 6 8bd1
r 6 abd3
r 6 cbd1
r 6 bd4r b 1c39
rr 6 2bdr b 1c38
3
r 6 5r b 1c37
837
r 6 abd2
r 6 cbd3
r 6 bd4
r 6 2bd3
r 6 5861
r 6 6bd0
r 6 8bd2
r 6 2bd3
r 6 5860
r 6 6bd0
r 6 8bd2
r 6 abd2
r 6 cbd3
r 6 bd2
r 6 8bd1
r 6 abd2
r 6 cbd3
r 6 bd2
r 6 2bd3
r 6 5860
r 6 6bd0
r 6 bd2
r 6 2bd3
r 6 5860
r 6 6bd0
r 6 8bd1
r 6 abd2
r 6 cbd2
r 6 5861
r 6 6bd0r b 1c19

r 6 8bd1
r b 1c18
r 6 abd2r b 1c17

r 6 cbd2
r 6 bd2
r 6 2bd4
r 6 abd2
r 6 cbd2
r 6 bd2
r 6 2bd4
r 6 5861
r 6 6bd0
r 6 8bd0
r 6 2bd3
r 6 5862
r 6 6bd0
r 6 8bd0
r 6 abd2
r 6 cbd2
r 6 bd3
r 6 8bd3
r 6 abd2
r 6 cbd2
r 6 bd3
r 6 2bd3
r 6 5862
r 6 6bcf
r 6 cbd1
r 6 bd3
r 6 2bd3
r 6 5862
r 6 6bcf
r 6 8bd3
r 6 abd3
r 6 5860
r 6 6bdr b 1bf6
1
r 6 8bd3
r 6 abd3r b 1bf4

r 6 cbd1
r 6 bd3
r b 1bf2
r 6 2bd3
r 6 abd3
r 6 cbd1
r 6 bd3
r 6 2bd3
r 6 5860
r 6 6bd1
r 6 8bd1
r 6 2bd3
r 6 5860
r 6 6bd1
r 6 8bd1
r 6 abd3
r 6 cbd1
r 6 bd3
r 6 6bd0
r 6 8bd1
r 6 abd3
r 6 cbd1
r 6 bd3
r 6 2bd3
r 6 5860
r 6 cbd2
r 6 bd3
r 6 2bd3
r 6 5860
r 6 6bd0
r 6 8bd1
r 6 abd2
r 6 5861
r 6 6bd0
r 6 8bd1
r b 1bd1
r 6 abr b 1bd1
d1
r 6 cbr b 1bd0
d0
r 6 bd3
r 6 2bd4
r 6 abd2
r 6 cbd2
r 6 bd3
r 6 2bd4
r 6 5861
r 6 6bd0
r 6 8bd3
r 6 bd3
r 6 2bd1
r 6 5861
r 6 6bd0
r 6 8bd3
r 6 abd2
r 6 cbd2
r 6 6bd0
r 6 8bd1
r 6 abd2
r 6 cbd2
r 6 bd3
r 6 2bd1
r 6 5861
r 6 cbd2
r 6 bd3
r 6 2bd1
r 6 5861
r 6 6bd0
r 6 8bd1
r 6 abd3r b 1bb2

r 6 5861
r b 1bb0
r 6 6bd1
r 6 r b 1baf
8baf
r 6 abd3
r 6 cbd2
r 6 bd3
r 6 2bd2
r 6 8bd1
r 6 abd2
r 6 cbd2
r 6 bd3
r 6 2bd2
r 6 5861
r 6 6bd1
r 6 bd3
r 6 2bd3
r 6 5861
r 6 6bd1
r 6 8bd1
r 6 abd2
r 6 cbd2
r 6 6bd0
r 6 8bd1
r 6 abd2
r 6 cbd2
r 6 bd3
r 6 2bd3
r 6 5860
r 6 cbd2
r 6 bd2
r 6 2bd3
r 6 5860
r 6 6bd0
r 6 8bd1
r 6 abd3
r 6 r b 1b8e
2b8e
r 6 586r b 1b8d
0
r 6 r b 1b8c
6b8c
r 6 8bd1
r 6 abd3
r 6 cbd2
r 6 bd2
r 6 8bd2
r 6 abd2
r 6 cbd2
r 6 bd2
r 6 2bd2
r 6 5860
r 6 6bcf
r 6 bd4
r 6 2bd3
r 6 5860
r 6 6bcf
r 6 8bd2
r 6 abd2
r 6 cbd2
r 6 6bcf
r 6 8bd2
r 6 abd2
r 6 cbd2
r 6 bd4
r 6 2bd3
r 6 5861
r 6 abd3
r 6 cbd2
r 6 bd2
r 6 2bd3
r 6 5861
r 6 6bcf
r r b 1b6c
6 8bd2r b 1b6c

r 6 2bdr b 1b6b
3
r 6 5860
r 6 6bcf
r 6 8bd2
r 6 abd3
r 6 cbd2
r 6 bd2
r 6 8bd1
r 6 abd3
r 6 cbd2
r 6 bd2
r 6 2bd3
r 6 5860
r 6 6bd0
r 6 bd3
r 6 2bd3
r 6 5860
r 6 6bd0
r 6 8bd1
r 6 abd3
r 6 cbd3
r 6 5860
r 6 6bd1
r 6 8bd3
r 6 abd3
r 6 cbd3
r 6 bd3
r 6 2bd3
r 6 abd2
r 6 cbd2
r 6 bd2
r 6r b 1b4c
 2bd3
r b 1b4c
r 6 5860r b 1b4b

r 6 6bd1
r 6 8bd3
r 6 2bd3
r 6 5860
r 6 6bd1
r 6 8bd3
r 6 abd2
r 6 cbd2
r 6 bd2
r 6 8bd2
r 6 abd2
r 6 cbd2
r 6 bd2
r 6 2bd3
r 6 5860
r 6 6bd0
r 6 cbd2
r 6 bd2
r 6 2bd2
r 6 5860
r 6 6bd0
r 6 8bd2
r 6 abd2
r 6 5861
r 6 6bd0
r 6 8bd2
r 6 abd2
r 6 cbd2
r 6 bd2
r 6 2bd2r b 1b2d

r 6r b 1b2c
 abd1
r b 1b2b
r 6 cbd1
r 6 bd2
r 6 2bd2
r 6 5861
r 6 6bd0
r 6 8bd2
r 6 2bd3
r 6 5861
r 6 6bd0
r 6 8bd2
r 6 abd1
r 6 cbd1
r 6 bd3
r 6 6bd0
r 6 8bd1
r 6 abd2
r 6 cbd1
r 6 bd3
r 6 2bd3
r 6 5861
r 6 cbd1
r 6 bd3
r 6 2bd3
r 6 5861
r 6 6bd0
r 6 8bd1
r 6 abd2
r 6 5860
r 6 6bd0
r 6 8bd2
r 6r b 1b0d
 1b0d
r b 1b0c
r b r b 1b0c
1b0c
r 6 bd3
r 6 2bd3
r 6 abd2
r 6 cbd3
r 6 bd3
r 6 2bd3
r 6 5860
r 6 6bd0
r 6 8bd2
r 6 bd3
r 6 2bd2
r 6 5860
r 6 6bd0
r 6 8bd2
r 6 abd2
r 6 cbd3
r 6 6bd1
r 6 8bd2
r 6 abd3
r 6 cbd3
r 6 bd3
r 6 2bd2
r 6 5860
r 6 cbd3
r 6 bd3
r 6 2bd3
r 6 5860
r 6 6bd1
r 6 8bd2
r 6 abd3
r 6r b 1aed
 1aer b 1aed
d
r 6 6br b 1aec
cc
r 6 8bd2
r 6 abd3
r 6 cbd3
r 6 bd3
r 6 2bd3
r 6 8bd2
r 6 abd2
r 6 cbd2
r 6 bd3
r 6 2bd3
r 6 5861
r 6 6bcf
r 6 bd3
r 6 2bd3
r 6 5861
r 6 6bcf
r 6 8bd2
r 6 abd2
r 6 cbd2
r 6 6bd0
r 6 8bd2
r 6 abd3
r 6 cbd2
r 6 bd3
r 6 2bd3
r 6 5861
r 6 cbd2
r 6 bd2
r 6 2bd3
r 6 58r b 1ace
6e
r 6 6bd0r b 1acd

r 6 8r b 1acc
acc
r 6 abd3
r 6 2bd3
r 6 5860
r 6 6bcf
r 6 8bd2
r 6 abd3
r 6 cbd2
r 6 bd2
r 6 8bd1
r 6 abd2
r 6 cbd2
r 6 bd2
r 6 2bd3
r 6 5860
r 6 6bcf
r 6 bd3
r 6 2bd2
r 6 5861
r 6 6bcf
r 6 8bd1
r 6 abd2
r 6 cbd2
r 6 6bcf
r 6 8bd1
r 6 abd2
r 6 cbd2
r 6 bd3
r 6 2bd2
r 6 5861
r 6 abr b 1aae
de
r 6 cbdr b 1aad
2
r 6 br b 1aac
dacr 6 2bd2
r 6 5861
r 6 6bcf
r 6 8bd1
r 6 2bd2
r 6 5861
r 6 6bd0
r 6 8bd1
r 6 abd2
r 6 cbd2
r 6 bd2
r 6 8bd2
r 6 abd2
r 6 cbd2
r 6 bd2
r 6 2bd2
r 6 5861
r 6 6bd0
r 6 bd3
r 6 2bd3
r 6 5861
r 6 6bd0
r 6 8bd2
r 6 abd2
r 6 cbd2
r 6 5861
r 6 6bd0
r 6 8bd1
r 6 abd2
r 6 cbd2
r 6 bd3r b 1a8d

r 6 2bd3
r b 1a8b
r b 1a8b
r b 1a8a
r 6 cbd2
r 6 bd3
r 6 2bd3
r 6 5861
r 6 6bd0
r 6 8bd1
r 6 2bd3
r 6 5861
r 6 6bd0
r 6 8bd1
r 6 abd2
r 6 cbd2
r 6 bd3
r 6 8bd2
r 6 abd2
r 6 cbd1
r 6 bd3
r 6 2bd3
r 6 5861
r 6 6bd0
r 6 cbd1
r 6 bd3
r 6 2bd3
r 6 5861
r 6 6bd0
r 6 8bd2
r 6 abd2
r 6 5861
r 6 6bd0
r 6 8bd2
r 6 abd2
r 6 cbd1
r 6 r b 1a6a
ba6ar 6 2bd3r b 1a69

r 6 abd3
r r b 1a67
b 1a67
r 6 bd3
r 6 2bd3
r 6 5861
r 6 6bd0
r 6 8bd2
r 6 2bd3
r 6 5860
r 6 6bd1
r 6 8bd2
r 6 abd3
r 6 cbd1
r 6 bd3
r 6 6bd1
r 6 8bd2
r 6 abd2
r 6 cbd2
r 6 bd3
r 6 2bd3
r 6 5860
r 6 cbd2
r 6 bd1
r 6 2bd3
r 6 5860
r 6 6bd1
r 6 8bd2
r 6 abd2
r 6 5860
r 6 6bd1
r 6 8bd3
r 6 abd2
r 6 cbd2
r 6 r b 1a47
ba47r 6 r b 1a46
2a46
r r b 1a45
6 1a45
r 6 cbd3
r 6 bd3
r 6 2bd3
r 6 5860
r 6 6bd1
r 6 8bd3
r 6 bd3
r 6 2bd2
r 6 5861
r 6 6bd1
r 6 8bd3
r 6 abd2
r 6 cbd3
r 6 6bd1
r 6 8bd2
r 6 abd2
r 6 cbd2
r 6 bd3
r 6 2bd2
r 6 5861
r 6 cbd2
r 6 bd2
r 6 2bd2
r 6 5861
r 6 6bd1
r 6 8bd2
r 6 abd2
r 6 5860
r 6 6bcf
r 6 8bd1
r 6 r b 1a26
aa26
r b 1a25
r 6 cbd2
r b 1a25
r 6 bd2
r 6 2bd2
r 6 8bd1
r 6 abd3
r 6 cbd3
r 6 bd2
r 6 2bd2
r 6 5860
r 6 6bcf
r 6 bd2
r 6 2bd3
r 6 5861
r 6 6bd1
r 6 8bd1
r 6 abd3
r 6 cbd3
r 6 6bd1
r 6 8bd1
r 6 abd2
r 6 cbd2
r 6 bd2
r 6 2bd3
r 6 5861
r 6 cbd2
r 6 bd2
r 6 2bd3
r 6 5861
r 6 6bd1
r 6 8bd1
r 6 abd2
r 6 2r b 1a06
b06
r 6 58r b 1a05
65
r b 1a04
r 6 6bd0
r 6 8bd3
r 6 abd2
r 6 cbd2
r 6 bd2
r 6 8bd3
r 6 abd3
r 6 cbd2
r 6 bd3
r 6 2bd3
r 6 5861
r 6 6bd0
r 6 bd3
r 6 2bd2
r 6 5860
r 6 6bd0
r 6 8bd3
r 6 abd3
r 6 cbd2
r 6 6bd0
r 6 8bd2
r 6 abd2
r 6 cbd2
r 6 bd3
r 6 2bd2
r 6 5860
r 6 abd2
r 6 cbd1
r 6 bd4
r 6 2bd2
r 6 5860
r 6 6bd0
r 6 8bd2
r b 19e3
r 6 2bd2
r b 19e3
r 6 586r b 19e2
1
r 6 6bd0
r 6 8bd2
r 6 abd2
r 6 cbd1
r 6 bd4
r 6 8bd2
r 6 abd3
r 6 cbd3
r 6 bd3
r 6 2bd2
r 6 5861
r 6 6bd0
r 6 bd3
r 6 2bd4
r 6 5860
r 6 6bd0
r 6 8bd2
r 6 abd3
r 6 cbd3
r 6 5860
r 6 6bd0
r 6 8bd2
r 6 abd2
r 6 cbd3
r 6 bd3
r 6 2bd4
r 6 abd2
r 6 cbd2
r 6 bd2
r 6 2bd3
r 6 5860
r 6 6bd0r b 19c2

r 6 8bd2
r b 19c0
r 6 2bd3
r 6 5861r b 19bf

r 6 6bd0
r 6 8bd1
r 6 abd2
r 6 cbd2
r 6 bd2
r 6 8bd1
r 6 abd3
r 6 cbd1
r 6 bd3
r 6 2bd3
r 6 5861
r 6 6bd0
r 6 cbd1
r 6 bd3
r 6 2bd2
r 6 5861
r 6 6bd0
r 6 8bd1
r 6 abd3
r 6 5861
r 6 6bcf
r 6 8bd2
r 6 abd3
r 6 cbd1
r 6 bd3
r 6 2bd2
r 6 abd3
r 6 cbd3
r 6 bd4
r 6 2bd2
r 6 5861
r b 199f
r 6 6bcf
r b 199e
r 6 8bd2
r 6 r b 199d
299d
r 6 5860
r 6 6bd0
r 6 8bd1
r 6 abd3
r 6 cbd3
r 6 bd4
r 6 6bd0
r 6 8bd1
r 6 abd2
r 6 cbd2
r 6 bd2
r 6 2bd2
r 6 5860
r 6 cbd2
r 6 bd2
r 6 2bd2
r 6 5861
r 6 6bd0
r 6 8bd1
r 6 abd2
r 6 5861
r 6 6bd0
r 6 8bd1
r 6 abd1
r 6 cbd2
r 6 bd2
r 6 2bd2
r 6 abd1
r 6 cbd3
r 6 bd2
r 6 2bd2
r 6 5861
r 6 6br b 197c
dc
r 6 8br b 197b
db
r 6 r b 197a
b97ar 6 2bd2
r 6 5860
r 6 6bcf
r 6 8bd1
r 6 abd1
r 6 cbd3
r 6 6bcf
r 6 8bd1
r 6 abd2
r 6 cbd2
r 6 bd2
r 6 2bd2
r 6 5860
r 6 cbd2
r 6 bd1
r 6 2bd2
r 6 5861
r 6 6bcf
r 6 8bd1
r 6 abd2
r 6 5861
r 6 6bd0
r 6 8bd2
r 6 abd1
r 6 cbd2
r 6 bd1
r 6 2bd2
r 6 8bd2
r 6 abd1
r 6 cbd1
r 6 bd3
r 6r b 195a
 195ar b 195a

r 6 58r b 1959
69
r 6 6bd0
r 6 bd3
r 6 2bd3
r 6 5860
r 6 6bcf
r 6 8bd1
r 6 abd1
r 6 cbd1
r 6 6bcf
r 6 8bd1
r 6 abd3
r 6 cbd3
r 6 bd3
r 6 2bd3
r 6 5860
r 6 cbd3
r 6 bd3
r 6 2bd4
r 6 5861
r 6 6bcf
r 6 8bd1
r 6 abd3
r 6 2bd4
r 6 5861
r 6 6bd0
r 6 8bd2
r 6 abd2
r 6 cbd3
r 6 bd3
r 6 8bd2
r b 193b
r 6 abdr b 193a
2
r 6 cbdr b 1939
2
r 6 bd2
r 6 2bd1
r 6 5861
r 6 6bd0
r 6 bd2
r 6 2bd1
r 6 5861
r 6 6bd0
r 6 8bd2
r 6 abd2
r 6 cbd2
r 6 6bd0
r 6 8bd2
r 6 abd2
r 6 cbd2
r 6 bd2
r 6 2bd1
r 6 5861
r 6 abd2
r 6 cbd2
r 6 bd3
r 6 2bd3
r 6 5861
r 6 6bd0
r 6 8bd2
r 6 2bd3
r 6 5861
r 6 6bd0
r 6 8bd1
r 6 abd2
r 6 cbd2
r 6 bd3
r 6 8bdr b 1918
1
r 6 abd2r b 1917

r 6 cbd2r b 1916

r 6 bd2
r 6 2bd2
r 6 5861
r 6 6bd0
r 6 bd2
r 6 2bd2
r 6 5860
r 6 6bd0
r 6 8bd1
r 6 abd2
r 6 cbd2
r 6 5860
r 6 6bd0
r 6 8bd2
r 6 abd2
r 6 cbd2
r 6 bd2
r 6 2bd2
r 6 abd2
r 6 cbd2
r 6 bd2
r 6 2bd3
r 6 5860
r 6 6bd0
r 6 8bd2
r 6 2bd3
r 6 5860
r 6 6bd0
r 6 8bd2
r 6 abd3
r 6 cbd2
r 6r b 18f6
rbd2
r 6r b 18f5
 18fr b 18f5
5
r 6 abd3
r 6 cbd3
r 6 bd3
r 6 2bd3
r 6 5860
r 6 6bd0
r 6 cbd3
r 6 bd3
r 6 2bd2
r 6 5860
r 6 6bd0
r 6 8bd2
r 6 abd3
r 6 5860
r 6 6bd0
r 6 8bd3
r 6 abd3
r 6 cbd3
r 6 bd3
r 6 2bd2
r 6 abd3
r 6 cbd3
r 6 bd3
r 6 2bd2
r 6 5860
r 6 6bd0
r 6 8bd3
r 6 2bd2
r 6 5860
r 6 6bd0
r 6 8r b 18d6
bd6
r 6 abdr b 18d5
5
r 6 r b 18d4
c8d4
r 6 bd3
r 6 6bd0
r 6 8bd2
r 6 abd2
r 6 cbd1
r 6 bd1
r 6 2bd2
r 6 5860
r 6 cbd1
r 6 bd1
r 6 2bd3
r 6 5860
r 6 6bd0
r 6 8bd2
r 6 abd2
r 6 5860
r 6 6bd0
r 6 8bd2
r 6 abd2
r 6 cbd3
r 6 bd1
r 6 2bd3
r 6 abd2
r 6 cbd3
r 6 bd2
r 6 2bd3
r 6 5862
r 6 6bd0
r 6 8bd2
r 6 bd2
r 6 r b 18b5
28b5
r 6r b 18b4
 18b4
r 6r b 18b3
 18b3
r 6 8bd2
r 6 abd2
r 6 cbd3
r 6 6bcf
r 6 8bd2
r 6 abd2
r 6 cbd1
r 6 bd3
r 6 2bd3
r 6 5862
r 6 cbd1
r 6 bd3
r 6 2bd3
r 6 5861
r 6 6bd1
r 6 8bd2
r 6 abd2
r 6 5861
r 6 6bd1
r 6 8bd1
r 6 abd3
r 6 cbd2
r 6 bd3
r 6 2bd3
r 6 8bd1
r 6 abd3
r 6 cbd2
r 6 bd3
r 6 2bd3
r 6 5860
r 6 r b 1894
6894
r 6r b 1893
 bd3
r 6r b 1892
 2bd3
r 6 5860
r 6 6bd1
r 6 8bd3
r 6 abd3
r 6 cbd2
r 6 6bd1
r 6 8bd3
r 6 abd2
r 6 cbd3
r 6 bd3
r 6 2bd3
r 6 5860
r 6 cbd3
r 6 bd3
r 6 2bd3
r 6 5860
r 6 6bd0
r 6 8bd3
r 6 abd2
r 6 2bd3
r 6 5860
r 6 6bd0
r 6 8bd2
r 6 abd2
r 6 cbd2
r 6 bd3
r 6 8bd2
r 6 abd2
r 6 cbd2
r 6 bdr b 1874
34r 6 2bd2
r 6r b 1872
 5860
r 6 r b 1871
r 6 
r 6 bd3
r 6 2bd2
r 6 5860
r 6 6bcf
r 6 8bd1
r 6 abd2
r 6 cbd2
r 6 6bcf
r 6 8bd1
r 6 abd3
r 6 cbd2
r 6 bd3
r 6 2bd2
r 6 5860
r 6 abd3
r 6 cbd2
r 6 bd3
r 6 2bd1
r 6 5860
r 6 6bd0
r 6 8bd1
r 6 2bd1
r 6 5860
r 6 6bd0
r 6 8bd2
r 6 abd3
r 6 cbd2
r 6 bd3
r 6 8bd2
r 6 abd3
r 6 cbr b 1852
52
r 6 bd3
r b 1851
r 6 2br b 1850
d0
r 6 5860
r 6 6bd0
r 6 bd3
r 6 2bd3
r 6 5860
r 6 6bd1
r 6 8bd2
r 6 abd3
r 6 cbd2
r 6 5860
r 6 6bd1
r 6 8bd2
r 6 abd2
r 6 cbd3
r 6 bd3
r 6 2bd3
r 6 abd2
r 6 cbd3
r 6 bd3
r 6 2bd3
r 6 5862
r 6 6bcf
r 6 8bd2
r 6 2bd3
r 6 5862
r 6 6bcf
r 6 8bd3
r 6 abd2
r 6 cbd3
r 6 bd3
r 6 8bd3
r 6 r b 1830
a830
r r b 182f
6 cbd1
r 6 r b 182e
b82er 6 2bd2
r 6 5862
r 6 6bcf
r 6 cbd1
r 6 bd3
r 6 2bd2
r 6 5860
r 6 6bd0
r 6 8bd2
r 6 abd2
r 6 5860
r 6 6bd0
r 6 8bd2
r 6 abd3
r 6 cbd1
r 6 bd2
r 6 2bd2
r 6 abd3
r 6 cbd1
r 6 bd2
r 6 2bd2
r 6 5861
r 6 6bcf
r 6 8bd2
r 6 2bd2
r 6 5861
r 6 6bcf
r 6 8bd1
r 6 abd2
r 6 cbd1
r 6r b 180f
 180fr 6r b 180e
 180e
r r b 180d
6 180d
r 6 abd2
r 6 cbd3
r 6 bd2
r 6 2bd4
r 6 5861
r 6 cbd3
r 6 bd2
r 6 2bd4
r 6 5860
r 6 6bd0
r 6 8bd1
r 6 abd2
r 6 5860
r 6 6bd0
r 6 8bd1
r 6 abd2
r 6 cbd2
r 6 bd3
r 6 2bd4
r 6 abd2
r 6 cbd2
r 6 bd3
r 6 2bd2
r 6 5861
r 6 6bd0
r 6 8bd1
r 6 bd3
r 6 2bd2
r 6 5861
r 6 6bd0
r 6 8bd1r b 17ee

r 6 abd2r b 17ed

r 6 cbd2r b 17ec

r 6 6bd0
r 6 8bd1
r 6 abd2
r 6 cbd2
r 6 bd3
r 6 2bd3
r 6 5861
r 6 cbd2
r 6 bd3
r 6 2bd3
r 6 5860
r 6 6bd1
r 6 8bd1
r 6 abd2
r 6 5860
r 6 6bd1
r 6 8bd1
r 6 abd3
r 6 cbd1
r 6 bd3
r 6 2bd3
r 6 8bd1
r 6 abd3
r 6 cbd1
r 6 bd3
r 6 2bd3
r 6 5861
r 6 6bd1
r 6 bd3
r 6 2bd3
r 6 5861
r 6 r b 17cc
67cc
r 6 r b 17cb
87cb
r b 17cb
r 6 abd2
r 6 cbd1
r 6 6bd0
r 6 8bd1
r 6 abd2
r 6 cbd3
r 6 bd2
r 6 2bd4
r 6 5861
r 6 cbd3
r 6 bd2
r 6 2bd4
r 6 5861
r 6 6bcf
r 6 8bd3
r 6 abd2
r 6 2bd4
r 6 5861
r 6 6bcf
r 6 8bd3
r 6 abd2
r 6 cbd2
r 6 bd2
r 6 8bd3
r 6 abd2
r 6 cbd2
r 6 bd3
r 6 2bd3
r 6 5860
r 6 6bcf
r 6 bd3r b 17ac

r 6 2bdr b 17ab
3
r 6 5r b 17aa
8aa
r 6 6bd0
r 6 8bd1
r 6 abd3
r 6 cbd2
r 6 6bd0
r 6 8bd1
r 6 abd3
r 6 cbd2
r 6 bd3
r 6 2bd3
r 6 5860
r 6 abd3
r 6 cbd2
r 6 bd3
r 6 2bd3
r 6 5861
r 6 6bd0
r 6 8bd1
r 6 2bd3
r 6 5861
r 6 6bd0
r 6 8bd1
r 6 abd2
r 6 cbd2
r 6 bd3
r 6 8bd1
r 6 abd2
r 6 cbd2
r 6 bd3
r 6 2bd3
r 6 5r b 178b
88b
r b 178a
r br b 178a
 178a
r 6 bd3
r 6 2bd3
r 6 5860
r 6 6bd1
r 6 8bd3
r 6 abd3
r 6 cbd2
r 6 5860
r 6 6bd1
r 6 8bd3
r 6 abd3
r 6 cbd3
r 6 bd2
r 6 2bd2
r 6 abd3
r 6 cbd3
r 6 bd2
r 6 2bd2
r 6 5860
r 6 6bcf
r 6 8bd3
r 6 2bd2
r 6 5860
r 6 6bcf
r 6 8bd1
r 6 abd3
r 6 cbd3
r 6 bd2
r 6 8bd1
r 6 abd3
r 6 cbd3
r b 176a
r 6 bd1
r 6r b 1769
 1769
r 6r b 1768
 5860
r 6 6bcf
r 6 cbd3
r 6 bd1
r 6 2bd2
r 6 5860
r 6 6bd1
r 6 8bd1
r 6 abd3
r 6 5860
r 6 6bd1
r 6 8bd1
r 6 abd3
r 6 cbd2
r 6 bd4
r 6 2bd3
r 6 abd3
r 6 cbd2
r 6 bd4
r 6 2bd3
r 6 5861
r 6 6bd0
r 6 8bd1
r 6 2bd3
r 6 5861
r 6 6bd0
r 6 8bd1
r 6 abd2
r 6 cbd3
r 6 bd4
r 6 6bd0
r 6 8bd1
r 6 abd2r b 1748

r 6 cbd3
r 6 bd3r b 1746
rr 6 2bd3r b 1745

r 6 5861
r 6 cbd3
r 6 bd3
r 6 2bd3
r 6 5861
r 6 6bce
r 6 8bd2
r 6 abd3
r 6 5861
r 6 6bce
r 6 8bd2
r 6 abd3
r 6 cbd2
r 6 bd3
r 6 2bd3
r 6 abd3
r 6 cbd2
r 6 bd3
r 6 2bd3
r 6 5860
r 6 6bd1
r 6 8bd2
r 6 bd3
r 6 2bd3
r 6 5860
r 6 6bd1
r 6 8bd1
r 6 abd2
r 6 cbd2
r 6 6bd1
r 6 8bd1
r 6 abd2r b 1725

r 6 cbdr b 1724
2
r 6 br b 1723
d23r 6 2bd3
r 6 5860
r 6 cbd2
r 6 bd2
r 6 2bd3
r 6 5860
r 6 6bd1
r 6 8bd3
r 6 abd2
r 6 5860
r 6 6bd1
r 6 8bd3
r 6 abd2
r 6 cbd2
r 6 bd3
r 6 2bd3
r 6 8bd3
r 6 abd2
r 6 cbd2
r 6 bd3
r 6 2bd3
r 6 5860
r 6 6bcf
r 6 bd3
r 6 2bd3
r 6 5860
r 6 6bcf
r 6 8bd2
r 6 abd3
r 6 cbd3
r 6 6bcfr b 1704

r 6 8bd2
r 6r b 1702
 1702r b 1702

r 6 cbd3
r 6 bd4
r 6 2bd2
r 6 5861
r 6 cbd3
r 6 bd4
r 6 2bd2
r 6 5861
r 6 6bcf
r 6 8bd3
r 6 abd3
r 6 2bd2
r 6 5861
r 6 6bcf
r 6 8bd3
r 6 abd2
r 6 cbd2
r 6 bd2
r 6 8bd3
r 6 abd2
r 6 cbd2
r 6 bd2
r 6 2bd3
r 6 5860
r 6 6bd1
r 6 bd2
r 6 2bd3
r 6 5860
r 6 6bd1
r 6 8bd2
r 6 abr b 16e3
d3
r b 16e2
r 6 cbd3r b 16e2

r 6 6bd1
r 6 8bd2
r 6 abd3
r 6 cbd3
r 6 bd3
r 6 2bd4
r 6 5860
r 6 abd3
r 6 cbd3
r 6 bd3
r 6 2bd4
r 6 5860
r 6 6bcf
r 6 8bd2
r 6 2bd4
r 6 5860
r 6 6bcf
r 6 8bd2
r 6 abd2
r 6 cbd1
r 6 bd3
r 6 8bd2
r 6 abd2
r 6 cbd1
r 6 bd3
r 6 2bd2
r 6 5861
r 6 6bcf
r 6 bd3
r 6 2bd2
r 6 5r b 16c3
8c3
r 6 r b 16c2
66c2
r 6 8br b 16c1
d1
r 6 abd3
r 6 cbd3
r 6 5861
r 6 6bcf
r 6 8bd1
r 6 abd3
r 6 cbd3
r 6 bd4
r 6 2bd3
r 6 abd3
r 6 cbd3
r 6 bd4
r 6 2bd3
r 6 5860
r 6 6bd0
r 6 8bd1
r 6 2bd3
r 6 5860
r 6 6bd0
r 6 8bd1
r 6 abd2
r 6 cbd2
r 6 bd2
r 6 8bd1
r 6 abd2
r 6 cbd2
r 6 bd2
r 6 2bd3
r 6 5860
r 6 6bdr b 16a3
0
r 6 cbd2
r b 16a1
r 6 br b 16a1
da1r 6 2bd3
r 6 5860
r 6 6bd0
r 6 8bd3
r 6 abd1
r 6 5860
r 6 6bd0
r 6 8bd3
r 6 abd1
r 6 cbd2
r 6 bd3
r 6 2bd3
r 6 abd1
r 6 cbd2
r 6 bd3
r 6 2bd3
r 6 5860
r 6 6bd0
r 6 8bd1
r 6 2bd3
r 6 5860
r 6 6bd0
r 6 8bd1
r 6 abd2
r 6 cbd1
r 6 bd4
r 6 6bd0
r 6 8bd1
r 6 abd2
r 6 cbd1
r 6 bd4
r 6r b 1681
 2bd3
r b 1680
r 6 586r b 1680
1
r 6 cbd1
r 6 bd4
r 6 2bd3
r 6 5861
r 6 6bd0
r 6 8bd1
r 6 abd3
r 6 5861
r 6 6bd0
r 6 8bd1
r 6 abd3
r 6 cbd2
r 6 bd3
r 6 2bd3
r 6 abd3
r 6 cbd2
r 6 bd3
r 6 2bd3
r 6 5861
r 6 6bcf
r 6 8bd2
r 6 bd2
r 6 2bd3
r 6 5861
r 6 6bcf
r 6 8bd2
r 6 abd3
r 6 cbd2
r 6 6bcf
r 6 8bd2
r 6 abd3r b 1661
r 6 abr b 1661
d1
r 6 cbr b 1660
d0
r 6 bd2
r 6 2bd3
r 6 5861
r 6 cbd2
r 6 bd2
r 6 2bd3
r 6 5861
r 6 6bcf
r 6 8bd1
r 6 abd2
r 6 5861
r 6 6bcf
r 6 8bd1
r 6 abd2
r 6 cbd2
r 6 bd3
r 6 2bd3
r 6 8bd1
r 6 abd2
r 6 cbd2
r 6 bd3
r 6 2bd3
r 6 5860
r 6 6bd0
r 6 bd3
r 6 2bd3
r 6 5860
r 6 6bd0
r 6 8bd1
r 6 abd3
r 6 cbr b 1641
d1
r 6 6bdr b 1640
0
r 6r b 163f
 163f
r 6 abd3
r 6 cbd2
r 6 bd3
r 6 2bd3
r 6 5860
r 6 cbd2
r 6 bd3
r 6 2bd3
r 6 5860
r 6 6bd1
r 6 8bd2
r 6 abd2
r 6 2bd3
r 6 5860
r 6 6bd1
r 6 8bd2
r 6 abd2
r 6 cbd2
r 6 bd3
r 6 8bd3
r 6 abd2
r 6 cbd2
r 6 bd3
r 6 2bd3
r 6 5861
r 6 6bd1
r 6 bd3
r 6 2bd3
r 6 5861
r 6 6bd1
r 6 r b 1620
1620
rr b 161f
 b 161f
r b 161f
r 6 cbd3
r 6 6bd1
r 6 8bd3
r 6 abd2
r 6 cbd3
r 6 bd3
r 6 2bd3
r 6 5860
r 6 abd3
r 6 cbd3
r 6 bd3
r 6 2bd3
r 6 5860
r 6 6bd0
r 6 8bd1
r 6 2bd3
r 6 5860
r 6 6bd0
r 6 8bd1
r 6 abd3
r 6 cbd1
r 6 bd2
r 6 8bd2
r 6 abd3
r 6 cbd1
r 6 bd2
r 6 2bd3
r 6 5860
r 6 6bd0
r 6 bd2
r 6 2bd3
r 6 r b 15ff
55ff
r 6 6r b 15fe
bfe
r 6 8r b 15fd
bfd
r 6 abd3
r 6 cbd3
r 6 5860
r 6 6bd0
r 6 8bd2
r 6 abd3
r 6 cbd3
r 6 bd3
r 6 2bd2
r 6 abd1
r 6 cbd3
r 6 bd3
r 6 2bd2
r 6 5860
r 6 6bd0
r 6 8bd1
r 6 2bd2
r 6 5860
r 6 6bd0
r 6 8bd1
r 6 abd1
r 6 cbd2
r 6 bd3
r 6 8bd3
r 6 abd1
r 6 cbd2
r 6 bd3
r 6 2bd2
r 6 5860
r 6 6bd0
r 6 cbd2r b 15de

r 6 bd3r b 15dd

r 6 2bd2
r b 15dc
r 6 5860
r 6 6bd0
r 6 8bd3
r 6 abd2
r 6 5860
r 6 6bd0
r 6 8bd3
r 6 abd2
r 6 cbd2
r 6 bd3
r 6 2bd3
r 6 abd2
r 6 cbd2
r 6 bd3
r 6 2bd3
r 6 5860
r 6 6bd1
r 6 8bd1
r 6 2bd2
r 6 5860
r 6 6bd1
r 6 8bd1
r 6 abd2
r 6 cbd2
r 6 bd2
r 6 6bd0
r 6 8bd1
r 6 abd2
r 6 cbd2
r 6 bd2
r 6 2bd2
r 6r b 15bc
 5860r b 15bc

r 6 cbdr b 15bb
2
r 6 bd2
r 6 2bd2
r 6 5860
r 6 6bd0
r 6 8bd2
r 6 abd3
r 6 5861
r 6 6bd0
r 6 8bd2
r 6 abd3
r 6 cbd2
r 6 bd3
r 6 2bd3
r 6 abd2
r 6 cbd2
r 6 bd3
r 6 2bd3
r 6 5861
r 6 6bd0
r 6 8bd2
r 6 bd2
r 6 2bd3
r 6 5861
r 6 6bd0
r 6 8bd2
r 6 abd2
r 6 cbd1
r 6 6bcf
r 6 8bd2
r 6 abd2
r b 159c
r 6 cr b 159c
b9c
r 6r b 159b
 159br 6 2bd3
r 6 5860
r 6 cbd2
r 6 bd2
r 6 2bd3
r 6 5860
r 6 6bcf
r 6 8bd1
r 6 abd3
r 6 5860
r 6 6bcf
r 6 8bd1
r 6 abd3
r 6 cbd2
r 6 bd3
r 6 2bd3
r 6 8bd1
r 6 abd3
r 6 cbd2
r 6 bd3
r 6 2bd3
r 6 5860
r 6 6bd0
r 6 bd2
r 6 2bd3
r 6 5860
r 6 6bd0
r 6 8bd1
r 6 abd3
r 6 r b 157d
c57d
r 6 r b 157c
657r b 157c
c
r 6 8bd1
r 6 abd3
r 6 cbd2
r 6 bd2
r 6 2bd3
r 6 5860
r 6 cbd2
r 6 bd2
r 6 2bd3
r 6 5860
r 6 6bd1
r 6 8bd2
r 6 abd3
r 6 2bd3
r 6 5860
r 6 6bd1
r 6 8bd2
r 6 abd3
r 6 cbd2
r 6 bd3
r 6 8bd3
r 6 abd2
r 6 cbd2
r 6 bd3
r 6 2bd3
r 6 5860
r 6 6bd0
r 6 bd3
r 6 2bd3
r 6 5860
r b 155e
r 6 6bd0r b 155d

r 6 8bdr b 155c
3
r 6 abd2
r 6 cbd2
r 6 6bd0
r 6 8bd3
r 6 abd2
r 6 cbd2
r 6 bd3
r 6 2bd2
r 6 5860
r 6 abd3
r 6 cbd3
r 6 bd3
r 6 2bd2
r 6 5860
r 6 6bd0
r 6 8bd1
r 6 2bd3
r 6 5860
r 6 6bd0
r 6 8bd1
r 6 abd3
r 6 cbd3
r 6 bd3
r 6 8bd1
r 6 abd3
r 6 cbd3
r 6 bd3
r 6 2bd3
r 6 5860
r 6 6bd0
r b 153d
r 6 r b 153d
b53dr 6 2r b 153c
b3c
r 6 5860
r 6 6bd0
r 6 8bd1
r 6 abd3
r 6 cbd2
r 6 5861
r 6 6bcf
r 6 8bd1
r 6 abd3
r 6 cbd2
r 6 bd3
r 6 2bd3
r 6 abd3
r 6 cbd2
r 6 bd3
r 6 2bd3
r 6 5861
r 6 6bcf
r 6 8bd3
r 6 2bd2
r 6 5861
r 6 6bcf
r 6 8bd3
r 6 abd3
r 6 cbd2
r 6 bd3
r 6 8bd2
r 6 abd3
r 6 cbd2
r 6 br b 151e
d1er 6 2bdr b 151d
2
r b 151c
r b 151c
r 6 6bd0
r 6 cbd2
r 6 bd3
r 6 2bd2
r 6 5861
r 6 6bd0
r 6 8bd2
r 6 abd3
r 6 5861
r 6 6bd0
r 6 8bd2
r 6 abd3
r 6 cbd2
r 6 bd3
r 6 2bd1
r 6 abd2
r 6 cbd2
r 6 bd3
r 6 2bd1
r 6 5861
r 6 6bd0
r 6 8bd2
r 6 2bd3
r 6 5861
r 6 6bd0
r 6 8bd2
r 6 abd2
r 6 cbd2
r 6 bd1
r 6 r b 14fe
64fe
r 6r b 14fd
 14fd
r 6 abd2
r b 14fc
r 6 cbd2
r 6 bd1
r 6 2bd3
r 6 5861
r 6 cbd2
r 6 bd3
r 6 2bd3
r 6 5861
r 6 6bd0
r 6 8bd2
r 6 abd2
r 6 5861
r 6 6bcf
r 6 8bd2
r 6 abd2
r 6 cbd2
r 6 bd3
r 6 2bd2
r 6 abd3
r 6 cbd1
r 6 bd3
r 6 2bd2
r 6 5861
r 6 6bcf
r 6 8bd3
r 6 bd3
r 6 2bd3
r 6 5861
r 6 6bcf
r 6 8bd3
r 6r b 14dd
 14dd
r 6r b 14dc
 14dc
r 6r b 14db
 6bd0
r 6 8bd2
r 6 abd3
r 6 cbd1
r 6 bd3
r 6 2bd3
r 6 5860
r 6 cbd2
r 6 bd3
r 6 2bd3
r 6 5860
r 6 6bd0
r 6 8bd2
r 6 abd2
r 6 5860
r 6 6bd0
r 6 8bd2
r 6 abd2
r 6 cbd2
r 6 bd3
r 6 2bd4
r 6 8bd3
r 6 abd2
r 6 cbd2
r 6 bd3
r 6 2bd4
r 6 5860
r 6 6bd0
r 6 bd4
r 6 2bd3
r 6 5r b 14bd
8bd
r 6 6bdr b 14bc
0
r 6r b 14bb
 14bb
r 6 abd2
r 6 cbd3
r 6 6bcf
r 6 8bd3
r 6 abd2
r 6 cbd3
r 6 bd4
r 6 2bd3
r 6 5861
r 6 cbd1
r 6 bd3
r 6 2bd3
r 6 5861
r 6 6bcf
r 6 8bd3
r 6 abd2
r 6 2bd2
r 6 5861
r 6 6bcf
r 6 8bd3
r 6 abd2
r 6 cbd1
r 6 bd3
r 6 8bd1
r 6 abd3
r 6 cbd1
r 6 bd3
r 6 2bd2
r 6 5861
r 6 6bcf
r 6 bd3
r b 149c
r 6 2bdr b 149b
3
r 6 5r b 149a
89a
r 6 6bcf
r 6 8bd1
r 6 abd3
r 6 cbd1
r 6 6bd0
r 6 8bd2
r 6 abd3
r 6 cbd1
r 6 bd3
r 6 2bd3
r 6 5860
r 6 abd3
r 6 cbd2
r 6 bd2
r 6 2bd3
r 6 5860
r 6 6bd0
r 6 8bd2
r 6 2bd3
r 6 5860
r 6 6bd0
r 6 8bd2
r 6 abd3
r 6 cbd2
r 6 bd2
r 6 8bd3
r 6 abd2
r 6 cbd2
r 6 bd2
r 6 2br b 147c
dc
r 6r b 147b
 147br b 147b

r 6 6bd0
r 6 bd3
r 6 2bd2
r 6 5860
r 6 6bd0
r 6 8bd3
r 6 abd2
r 6 cbd1
r 6 5861
r 6 6bd0
r 6 8bd1
r 6 abd2
r 6 cbd1
r 6 bd3
r 6 2bd2
r 6 abd3
r 6 cbd2
r 6 bd3
r 6 2bd2
r 6 5861
r 6 6bd0
r 6 8bd1
r 6 2bd2
r 6 5860
r 6 6bd0
r 6 8bd1
r 6 abd3
r 6 cbd2
r 6 bd3
r 6 8bd2
r 6r b 145c
 abd3
r r b 145b
r r cbdr b 145b
b
r 6 bd3
r 6 2bd2
r 6 5860
r 6 6bcf
r 6 cbd3
r 6 bd2
r 6 2bd3
r 6 5860
r 6 6bcf
r 6 8bd2
r 6 abd3
r 6 5860
r 6 6bd0
r 6 8bd1
r 6 abd3
r 6 cbd3
r 6 bd2
r 6 2bd3
r 6 abd2
r 6 cbd3
r 6 bd2
r 6 2bd3
r 6 5860
r 6 6bd0
r 6 8bd1
r 6 2bd3
r 6 5860
r 6 6bd0
r 6 8bd1
r 6 abd2r b 143d

r 6 r b 143c
cbd3
r b 143b
r 6 bd2
r 6 6bd0
r 6 8bd2
r 6 abd2
r 6 cbd3
r 6 bd2
r 6 2bd3
r 6 5860
r 6 cbd2
r 6 bd3
r 6 2bd3
r 6 5860
r 6 6bd0
r 6 8bd2
r 6 abd2
r 6 5860
r 6 6bd0
r 6 8bd1
r 6 abd2
r 6 cbd2
r 6 bd3
r 6 2bd3
r 6 abd3
r 6 cbd1
r 6 bd3
r 6 2bd3
r 6 5860
r 6 6bd0
r 6 8bd1
r 6 bd3
r 6 r b 141d
241d
r b 141c
r 6 5860r b 141c

r 6 6bd0
r 6 8bd1
r 6 abd3
r 6 cbd1
r 6 6bd0
r 6 8bd2
r 6 abd3
r 6 cbd1
r 6 bd3
r 6 2bd2
r 6 5860
r 6 cbd2
r 6 bd2
r 6 2bd3
r 6 5860
r 6 6bd0
r 6 8bd2
r 6 abd3
r 6 5860
r 6 6bd0
r 6 8bd2
r 6 abd3
r 6 cbd2
r 6 bd2
r 6 2bd3
r 6 8bd2
r 6 abd3
r 6 cbd1
r 6 bd2
r 6 2bd3
r b 13fd
r 6 5860r b 13fd

r 6 6bdr b 13fc
0
r 6 bd2
r 6 2bd2
r 6 5861
r 6 6bd0
r 6 8bd2
r 6 abd3
r 6 cbd1
r 6 6bcf
r 6 8bd2
r 6 abd2
r 6 cbd1
r 6 bd2
r 6 2bd2
r 6 5861
r 6 cbd2
r 6 bd3
r 6 2bd2
r 6 5861
r 6 6bcf
r 6 8bd2
r 6 abd2
r 6 2bd2
r 6 5860
r 6 6bd0
r 6 8bd2
r 6 abd2
r 6 cbd2
r 6 bd3
r 6 8bd1
r 6 abd3
r 6 cbr b 13dd
dd
r 6 bd3r b 13dc
rr 6 2br b 13db
db
r 6 5860
r 6 6bd0
r 6 bd3
r 6 2bd2
r 6 5861
r 6 6bd0
r 6 8bd1
r 6 abd3
r 6 cbd3
r 6 6bd1
r 6 8bd3
r 6 abd2
r 6 cbd3
r 6 bd3
r 6 2bd2
r 6 5861
r 6 abd2
r 6 cbd3
r 6 bd2
r 6 2bd2
r 6 5861
r 6 6bd1
r 6 8bd3
r 6 2bd3
r 6 5860
r 6 6bd0
r 6 8bd3
r 6 abd2
r 6 cbd3
r 6 bd2
r 6r b 13bc
 13bc
r 6 abd3r b 13bb

r 6 cbd1r b 13ba

r 6 bd2
r 6 2bd3
r 6 5860
r 6 6bd0
r 6 bd3
r 6 2bd3
r 6 5861
r 6 6bd0
r 6 8bd3
r 6 abd3
r 6 cbd1
r 6 5861
r 6 6bd0
r 6 8bd1
r 6 abd3
r 6 cbd1
r 6 bd3
r 6 2bd3
r 6 abd3
r 6 cbd1
r 6 bd3
r 6 2bd3
r 6 5861
r 6 6bd0
r 6 8bd1
r 6 2bd1
r 6 5860
r 6 6bcf
r 6 8bd1
r 6 abd3
r 6 cr b 139b
b9br b 139b

r 6 bd3r b 139a

r 6 8bd2
r 6 abd2
r 6 cbd3
r 6 bd3
r 6 2bd1
r 6 5860
r 6 6bcf
r 6 cbd3
r 6 bd2
r 6 2bd3
r 6 5860
r 6 6bcf
r 6 8bd2
r 6 abd2
r 6 5860
r 6 6bd0
r 6 8bd2
r 6 abd2
r 6 cbd3
r 6 bd2
r 6 2bd3
r 6 abd1
r 6 cbd2
r 6 bd4
r 6 2bd3
r 6 5860
r 6 6bd0
r 6 8bd2
r 6 2bd3
r 6 5860
r b 137b
r 6 r b 137b
637b
rr b 137a
 b 137a
r 6 abd1
r 6 cbd2
r 6 bd4
r 6 6bcf
r 6 8bd2
r 6 abd2
r 6 cbd2
r 6 bd4
r 6 2bd3
r 6 5860
r 6 cbd2
r 6 bd3
r 6 2bd3
r 6 5860
r 6 6bcf
r 6 8bd2
r 6 abd2
r 6 5860
r 6 6bd0
r 6 8bd2
r 6 abd2
r 6 cbd2
r 6 bd3
r 6 2bd3
r 6 abd2
r 6 cbd2
r 6 bd2
r 6 2bd3
r 6 5860
r 6 6bd0r b 135c

r 6 8bd2
r b 135a
r 6 bd2r b 135a

r 6 2bd3
r 6 5860
r 6 6bd0
r 6 8bd2
r 6 abd2
r 6 cbd2
r 6 6bd0
r 6 8bd1
r 6 abd3
r 6 cbd2
r 6 bd2
r 6 2bd3
r 6 5860
r 6 cbd2
r 6 bd2
r 6 2bd3
r 6 5860
r 6 6bd0
r 6 8bd1
r 6 abd3
r 6 5861
r 6 6bd0
r 6 8bd3
r 6 abd3
r 6 cbd2
r 6 bd2
r 6 2bd3
r 6 8bd3
r 6 abd1
r 6 cbd3
r 6 bdr b 133b
3br 6 2r b 133a
b3a
r 6 5861
r b 1339
r 6 5861
r 6 6bd0
r 6 bd3
r 6 2bd3
r 6 5860
r 6 6bcf
r 6 8bd3
r 6 abd1
r 6 cbd3
r 6 6bcf
r 6 8bd3
r 6 abd3
r 6 cbd2
r 6 bd3
r 6 2bd3
r 6 5860
r 6 cbd2
r 6 bd3
r 6 2bd2
r 6 5860
r 6 6bcf
r 6 8bd3
r 6 abd3
r 6 2bd2
r 6 5861
r 6 6bd0
r 6 8bd1
r 6 abd3
r 6 cbd2
r 6 bd3
r 6r b 131b
 131b
r 6 ar b 131a
b1a
r 6 cbdr b 1319
3
r 6 bd3
r 6 2bd2
r 6 5861
r 6 6bd0
r 6 bd3
r 6 2bd3
r 6 5860
r 6 6bcf
r 6 8bd1
r 6 abd2
r 6 cbd3
r 6 6bcf
r 6 8bd2
r 6 abd2
r 6 cbd3
r 6 bd3
r 6 2bd3
r 6 5860
r 6 abd2
r 6 cbd2
r 6 bd3
r 6 2bd3
r 6 5860
r 6 6bcf
r 6 8bd2
r 6 2bd3
r 6 5861
r 6 6bd0
r 6 8bd3
r 6 abd2
r 6 cbd2
r b 12fa
r 6 bd3
r 6r b 12f8
 12fr b 12f8
8
r 6 abd2
r 6 cbd4
r 6 bd2
r 6 2bd3
r 6 5861
r 6 6bd0
r 6 bd2
r 6 2bd3
r 6 5861
r 6 6bd0
r 6 8bd3
r 6 abd2
r 6 cbd4
r 6 5861
r 6 6bd0
r 6 8bd2
r 6 abd3
r 6 cbd4
r 6 bd2
r 6 2bd3
r 6 abd3
r 6 cbd1
r 6 bd3
r 6 2bd3
r 6 5861
r 6 6bd0
r 6 8bd2
r 6 2bd3
r 6 5860
r 6 r b 12da
62da
r 6 r b 12d9
82d9
r 6r b 12d8
 12d8
r 6 cbd1
r 6 bd3
r 6 8bd1
r 6 abd3
r 6 cbd2
r 6 bd2
r 6 2bd3
r 6 5860
r 6 6bd1
r 6 cbd2
r 6 bd2
r 6 2bd3
r 6 5861
r 6 6bd1
r 6 8bd1
r 6 abd3
r 6 5861
r 6 6bd0
r 6 8bd3
r 6 abd2
r 6 cbd2
r 6 bd2
r 6 2bd3
r 6 abd2
r 6 cbd3
r 6 bd2
r 6 2bd4
r 6 5861
r 6 6bd0
r 6 8r b 12ba
bba
r 6 2r b 12b9
bb9
r 6r b 12b8
 12b8
r 6 6bd0
r 6 8bd1
r 6 abd2
r 6 cbd3
r 6 bd2
r 6 6bd0
r 6 8bd1
r 6 abd4
r 6 cbd1
r 6 bd3
r 6 2bd4
r 6 5861
r 6 cbd1
r 6 bd3
r 6 2bd2
r 6 5861
r 6 6bd0
r 6 8bd1
r 6 abd4
r 6 5861
r 6 6bcf
r 6 8bd1
r 6 abd3
r 6 cbd1
r 6 bd3
r 6 2bd2
r 6 abd3
r 6 cbd2
r 6 bd3
r 6 2bd3
r r b 1299
6 5861
r 6 r b 1298
6bcf
r b 1297
r 6 8bd1
r 6 bd3
r 6 2bd3
r 6 5860
r 6 6bd0
r 6 8bd2
r 6 abd3
r 6 cbd2
r 6 6bd0
r 6 8bd2
r 6 abd3
r 6 cbd3
r 6 bd3
r 6 2bd3
r 6 5860
r 6 cbd3
r 6 bd1
r 6 2bd3
r 6 5860
r 6 6bd0
r 6 8bd2
r 6 abd3
r 6 5860
r 6 6bce
r 6 8bd2
r 6 abd2
r 6 cbd3
r 6 bd1
r 6 2bd3
r 6 8bd2
r 6 abr b 1279
d9
r b 1278
r 6 cbd3r b 1278

r 6 bd3
r 6 2bd3
r 6 5860
r 6 6bce
r 6 bd3
r 6 2bd3
r 6 5861
r 6 6bcf
r 6 8bd1
r 6 abd2
r 6 cbd3
r 6 6bcf
r 6 8bd1
r 6 abd2
r 6 cbd1
r 6 bd3
r 6 2bd3
r 6 5861
r 6 cbd1
r 6 bd4
r 6 2bd2
r 6 5861
r 6 6bcf
r 6 8bd1
r 6 abd2
r 6 2bd2
r 6 5861
r 6 6bd1
r 6 8bd0
r 6r b 125a
 125r b 125a
a
r 6 cbdr b 1259
1
r 6 bd4
r 6 8bd0
r 6 abd3
r 6 cbd2
r 6 bd3
r 6 2bd4
r 6 5861
r 6 6bd1
r 6 bd3
r 6 2bd4
r 6 5860
r 6 6bd0
r 6 8bd0
r 6 abd3
r 6 cbd2
r 6 6bd0
r 6 8bd3
r 6 abd2
r 6 cbd1
r 6 bd3
r 6 2bd4
r 6 5860
r 6 abd2
r 6 cbd1
r 6 bd3
r 6 2bd3
r 6 5860
r 6 6bd0
r 6 8bd3
r 6 2bd3
r 6 5r b 123a
83a
r 6 r b 1239
6239
r 6r b 1238
 1238
r 6 abd3
r 6 cbd1
r 6 bd3
r 6 8bd3
r 6 abd3
r 6 cbd3
r 6 bd3
r 6 2bd2
r 6 5860
r 6 6bd1
r 6 bd3
r 6 2bd2
r 6 5860
r 6 6bd0
r 6 8bd3
r 6 abd3
r 6 cbd3
r 6 5860
r 6 6bd0
r 6 8bd2
r 6 abd2
r 6 cbd2
r 6 bd3
r 6 2bd2
r 6 abd2
r 6 cbd2
r 6 bd3
r 6 2bd3
r 6 5860
r b 121a
r 6 r b 121a
621a
r 6r b 1219
 1219
r 6 2bd3
r 6 5860
r 6 6bd1
r 6 8bd3
r 6 abd3
r 6 cbd2
r 6 bd3
r 6 8bd3
r 6 abd3
r 6 cbd3
r 6 bd2
r 6 2bd3
r 6 5860
r 6 6bd1
r 6 cbd3
r 6 bd2
r 6 2bd3
r 6 5860
r 6 6bd0
r 6 8bd3
r 6 abd3
r 6 5860
r 6 6bd0
r 6 8bd3
r 6 abd3
r 6 cbd2
r 6 bd2
r 6 2bd3
r 6 abd3
r 6 cbd2
r r b 11fa
6 11far 6 r b 11f9
21f9
r 6 r b 11f8
5860
r 6 6bd0
r 6 8bd3
r 6 2bd3
r 6 5860
r 6 6bcf
r 6 8bd3
r 6 abd2
r 6 cbd2
r 6 bd3
r 6 6bcf
r 6 8bd3
r 6 abd2
r 6 cbd2
r 6 bd3
r 6 2bd3
r 6 5860
r 6 cbd2
r 6 bd3
r 6 2bd3
r 6 5860
r 6 6bd0
r 6 8bd3
r 6 abd2
r 6 5860
r 6 6bd0
r 6 8bd1
r 6 abd3
r 6 cbd1
r 6 bd3
r 6 2bd3
r b 11d9
r 6 abd3
r 6r b 11d8
 cbd1
r b 11d8
r 6 bd3
r 6 2bd3
r 6 5860
r 6 6bd0
r 6 8bd1
r 6 bd3
r 6 2bd3
r 6 5860
r 6 6bd1
r 6 8bd2
r 6 abd3
r 6 cbd1
r 6 6bd1
r 6 8bd2
r 6 abd3
r 6 cbd2
r 6 bd3
r 6 2bd3
r 6 5860
r 6 cbd2
r 6 bd3
r 6 2bd3
r 6 5861
r 6 6bd1
r 6 8bd2
r 6 abd3
r 6 5861
r 6 6bd1
r 6 8bd2
r 6 abd2
r 6 cbdr b 11b9
3
r 6 bd3r b 11b8

r 6 2bdr b 11b7
3
r 6 8bd2
r 6 abd2
r 6 cbd3
r 6 bd2
r 6 2bd3
r 6 5860
r 6 6bd1
r 6 bd2
r 6 2bd3
r 6 5860
r 6 6bd0
r 6 8bd3
r 6 abd2
r 6 cbd3
r 6 6bd0
r 6 8bd3
r 6 abd4
r 6 cbd2
r 6 bd3
r 6 2bd3
r 6 5860
r 6 cbd2
r 6 bd3
r 6 2bd4
r 6 5860
r 6 6bd0
r 6 8bd3
r 6 abd4
r 6 2bd4
r 6 5860r b 1199

r 6 6bd0r b 1198

r 6 8br b 1197
d7
r 6 abd2
r 6 cbd1
r 6 bd3
r 6 8bd1
r 6 abd2
r 6 cbd1
r 6 bd2
r 6 2bd3
r 6 5860
r 6 6bd0
r 6 bd2
r 6 2bd3
r 6 5861
r 6 6bd0
r 6 8bd1
r 6 abd2
r 6 cbd1
r 6 6bd0
r 6 8bd1
r 6 abd2
r 6 cbd2
r 6 bd3
r 6 2bd3
r 6 5861
r 6 abd2
r 6 cbd2
r 6 bd3
r 6 2bd3
r 6 5860
r 6 6bcf
r 6 8bd1r b 1178

r 6 2br b 1177
d7
r 6 r b 1176
5176
r 6 6bcf
r 6 8bd2
r 6 abd2
r 6 cbd3
r 6 bd3
r 6 8bd2
r 6 abd2
r 6 cbd3
r 6 bd2
r 6 2bd3
r 6 5860
r 6 6bcf
r 6 bd2
r 6 2bd3
r 6 5861
r 6 6bcf
r 6 8bd3
r 6 abd2
r 6 cbd3
r 6 5861
r 6 6bcf
r 6 8bd3
r 6 abd1
r 6 cbd2
r 6 bd2
r 6 2bd3
r 6 abd1
r 6 cbd2
r 6 bd2
r 6 2r b 1158
b58
r 6 58r b 1157
67
r 6 r b 1156
6156
r 6 8bd3
r 6 2bd3
r 6 5860
r 6 6bcf
r 6 8bd1
r 6 abd2
r 6 cbd2
r 6 bd2
r 6 8bd1
r 6 abd2
r 6 cbd1
r 6 bd3
r 6 2bd3
r 6 5860
r 6 6bcf
r 6 cbd1
r 6 bd3
r 6 2bd3
r 6 5860
r 6 6bd1
r 6 8bd2
r 6 abd2
r 6 5860
r 6 6bd1
r 6 8bd2
r 6 abd2
r 6 cbd3
r 6 bd2
r 6 2bd3
r 6 abd2
r 6r b 1137
 1137
r 6 br b 1136
d36r 6 r b 1135
2135
r 6 5861
r 6 6bd0
r 6 8bd2
r 6 2bd3
r 6 5861
r 6 6bd0
r 6 8bd2
r 6 abd2
r 6 cbd3
r 6 bd2
r 6 6bd0
r 6 8bd2
r 6 abd2
r 6 cbd3
r 6 bd2
r 6 2bd4
r 6 5861
r 6 cbd3
r 6 bd2
r 6 2bd4
r 6 5861
r 6 6bd0
r 6 8bd1
r 6 abd2
r 6 5861
r 6 6bd0
r 6 8bd1
r 6 abd2
r 6 cbd1
r 6 bd3
r b 1116
r 6 2bd4
r b 1115
r 6 abd2
r b 1115
r 6 cbd1
r 6 bd3
r 6 2bd2
r 6 5861
r 6 6bd0
r 6 8bd1
r 6 bd3
r 6 2bd2
r 6 5861
r 6 6bcf
r 6 8bd2
r 6 abd2
r 6 cbd1
r 6 6bcf
r 6 8bd2
r 6 abd2
r 6 cbd2
r 6 bd3
r 6 2bd2
r 6 5861
r 6 cbd2
r 6 bd3
r 6 2bd2
r 6 5860
r 6 6bd0
r 6 8bd0
r 6 abd2
r 6 5860
r 6 6bd0
r 6 8bd0
r 6r b 10f6
 abd2
r 6r b 10f5
 10f5r b 10f5

r 6 bd3
r 6 2bd2
r 6 8bd0
r 6 abd2
r 6 cbd1
r 6 bd3
r 6 2bd3
r 6 5862
r 6 6bd0
r 6 bd3
r 6 2bd3
r 6 5862
r 6 6bd0
r 6 8bd3
r 6 abd1
r 6 cbd1
r 6 6bd0
r 6 8bd3
r 6 abd1
r 6 cbd2
r 6 bd2
r 6 2bd4
r 6 5862
r 6 cbd2
r 6 bd2
r 6 2bd4
r 6 5861
r 6 6bd0
r 6 8bd2
r 6 abd1
rr b 10d6
 b 10d6
r 6 58r b 10d5
65
r b 10d4
r 6 6bd0
r 6 8bd2
r 6 abd3
r 6 cbd2
r 6 bd2
r 6 8bd2
r 6 abd3
r 6 cbd2
r 6 bd3
r 6 2bd2
r 6 5861
r 6 6bd0
r 6 bd3
r 6 2bd2
r 6 5861
r 6 6bd0
r 6 8bd2
r 6 abd2
r 6 cbd2
r 6 6bd0
r 6 8bd2
r 6 abd2
r 6 cbd2
r 6 bd3
r 6 2bd3
r 6 5861
r 6 abd2
r 6 cbd2
r 6 bd3
r 6 2bd3
r 6 5860
r 6r b 10b5
 10b5
r 6r b 10b4
 8bdr b 10b4
20r 6 2bd3
r 6 5860
r 6 6bd0
r 6 8bd2
r 6 abd3
r 6 cbd3
r 6 bd3
r 6 8bd2
r 6 abd3
r 6 cbd3
r 6 bd2
r 6 2bd3
r 6 5860
r 6 6bd0
r 6 bd2
r 6 2bd3
r 6 5860
r 6 6bcf
r 6 8bd2
r 6 abd2
r 6 cbd3
r 6 5860
r 6 6bcf
r 6 8bd2
r 6 abd2
r 6 cbd2
r 6 bd3
r 6 2bd2
r 6 abd2
r 6 cbd2
r 6 bd3
r 6 2bd2
r 6r b 1093
r 6r5r b 1093
893
r 6 r b 1092
6092
r 6 8bd2
r 6 2bd2
r 6 5861
r 6 6bcf
r 6 8bd2
r 6 abd3
r 6 cbd2
r 6 bd3
r 6 8bd2
r 6 abd3
r 6 cbd2
r 6 bd1
r 6 2bd3
r 6 5861
r 6 6bcf
r 6 cbd2
r 6 bd1
r 6 2bd3
r 6 5861
r 6 6bd1
r 6 8bd1
r 6 abd2
r 6 5861
r 6 6bd1
r 6 8bd1
r 6 abd2
r 6 cbd2
r 6 bd3
r 6 2bd2
r 6 abr b 1074
d4
r 6 cbr b 1073
d3
r 6r b 1072
 1072r 6 2bd2
r 6 5860
r 6 6bcf
r 6 8bd1
r 6 2bd2
r 6 5860
r 6 6bcf
r 6 8bd3
r 6 abd2
r 6 cbd2
r 6 bd3
r 6 6bcf
r 6 8bd3
r 6 abd2
r 6 cbd2
r 6 bd3
r 6 2bd3
r 6 5860
r 6 cbd2
r 6 bd3
r 6 2bd3
r 6 5860
r 6 6bd0
r 6 8bd2
r 6 abd2
r 6 5860
r 6 6bd0
r 6 8bd2
r 6 abd2
r 6r b 1054
 1054r b 1054

r 6 bd3
r b 1053
r 6 2bd3
r 6 abd2
r 6 cbd3
r 6 bd3
r 6 2bd3
r 6 5860
r 6 6bd0
r 6 8bd2
r 6 bd3
r 6 2bd3
r 6 5860
r 6 6bd0
r 6 8bd2
r 6 abd2
r 6 cbd3
r 6 6bd0
r 6 8bd2
r 6 abd2
r 6 cbd3
r 6 bd3
r 6 2bd2
r 6 5860
r 6 cbd3
r 6 bd3
r 6 2bd2
r 6 5860
r 6 6bd1
r 6 8bd3
r 6 abd2
r 6 5860
r 6 6bd1r b 1034

r 6 8br b 1033
d3
r 6 r b 1032
a032
r 6 cbd2
r 6 bd3
r 6 2bd2
r 6 8bd3
r 6 abd2
r 6 cbd2
r 6 bd3
r 6 2bd3
r 6 5860
r 6 6bd0
r 6 bd3
r 6 2bd3
r 6 5860
r 6 6bd0
r 6 8bd2
r 6 abd3
r 6 cbd1
r 6 6bd0
r 6 8bd2
r 6 abd3
r 6 cbd1
r 6 bd3
r 6 2bd3
r 6 5861
r 6 cbd1
r 6 bd3
r 6 2bd3
r 6 5861
r 6 6bd0
r 6 8bd2
r 6 abd3r b 1013

r 6 2bd3
r b 1012
r 6 5861r b 1011

r 6 6bd0
r 6 8bd2
r 6 abd2
r 6 cbd3
r 6 bd2
r 6 8bd2
r 6 abd2
r 6 cbd3
r 6 bd2
r 6 2bd3
r 6 5861
r 6 6bd0
r 6 bd2
r 6 2bd3
r 6 5861
r 6 6bd0
r 6 8bd2
r 6 abd1
r 6 cbd1
r 6 6bd0
r 6 8bd2
r 6 abd1
r 6 cbd1
r 6 bd2
r 6 2bd2
r 6 5860
r 6 abd1
r 6 cbd1
r 6 bd2
r 6 2bdr b ff3
2
r 6 5r b ff2
82

r 6r b ff1
 ff1

r 6 8bd1
r 6 2bd2
r 6 5860
r 6 6bd0
r 6 8bd1
r 6 abd3
r 6 cbd2
r 6 bd3
r 6 8bd1
r 6 abd3
r 6 cbd2
r 6 bd3
r 6 2bd3
r 6 5860
r 6 6bcf
r 6 bd3
r 6 2bd3
r 6 5860
r 6 6bcf
r 6 8bd2
r 6 abd2
r 6 cbd2
r 6 5860
r 6 6bcf
r 6 8bd2
r 6 abd2
r 6 cbd2
r 6 bd2
r 6 2bd3
r 6 ar b fd3
b3

r 6r b fd2
 cbd2
r b fd1
r 6 bd2
r 6 2bd3
r 6 5860
r 6 6bd0
r 6 8bd2
r 6 2bd3
r 6 5860
r 6 6bd0
r 6 8bd2
r 6 abd3
r 6 cbd2
r 6 bd3
r 6 8bd2
r 6 abd3
r 6 cbd2
r 6 bd3
r 6 2bd3
r 6 5861
r 6 6bd0
r 6 cbd2
r 6 bd3
r 6 2bd3
r 6 5861
r 6 6bd0
r 6 8bd3
r 6 abd2
r 6 5861
r 6 6bd0
r 6 8bd3
r 6 abd2
r 6r b fb3
 fb3
r b fb3

r 6 bd3r b fb2

r 6 2bd2
r 6 abd2
r 6 cbd2
r 6 bd3
r 6 2bd2
r 6 5860
r 6 6bd0
r 6 8bd2
r 6 2bd2
r 6 5860
r 6 6bd0
r 6 8bd2
r 6 abd3
r 6 cbd1
r 6 bd4
r 6 6bd0
r 6 8bd2
r 6 abd3
r 6 cbd1
r 6 bd4
r 6 2bd2
r 6 5860
r 6 cbd1
r 6 bd4
r 6 2bd2
r 6 5860
r 6 6bd0
r 6 8bd1
r 6 abd4
r 6 5860
r 6r b f93
 f9r b f93
3

r r b f92
6 f92

r 6 abd4
r 6 cbd3
r 6 bd3
r 6 2bd2
r 6 abd4
r 6 cbd3
r 6 bd3
r 6 2bd2
r 6 5860
r 6 6bd0
r 6 8bd2
r 6 bd3
r 6 2bd2
r 6 5860
r 6 6bd0
r 6 8bd2
r 6 abd2
r 6 cbd1
r 6 6bd0
r 6 8bd2
r 6 abd2
r 6 cbd1
r 6 bd3
r 6 2bd3
r 6 5860
r 6 cbd1
r 6 bd3
r 6 2bd3
r 6 5860
r 6 6br b f74
d
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

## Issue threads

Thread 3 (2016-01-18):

Host warns of 0 samples even though it is expected.

atypic, 2016-01-18:
The host software will report 0 samples as a warning when it receives 0 samples from the microcontroller. The 0 sample is expected since it's the 'last fetch' and actually it is a part of the check-if-run-is-over. Suggested fix is to not display the warning when it is very much expected: calculate the number of expected samples and don't display the message if we are above this.

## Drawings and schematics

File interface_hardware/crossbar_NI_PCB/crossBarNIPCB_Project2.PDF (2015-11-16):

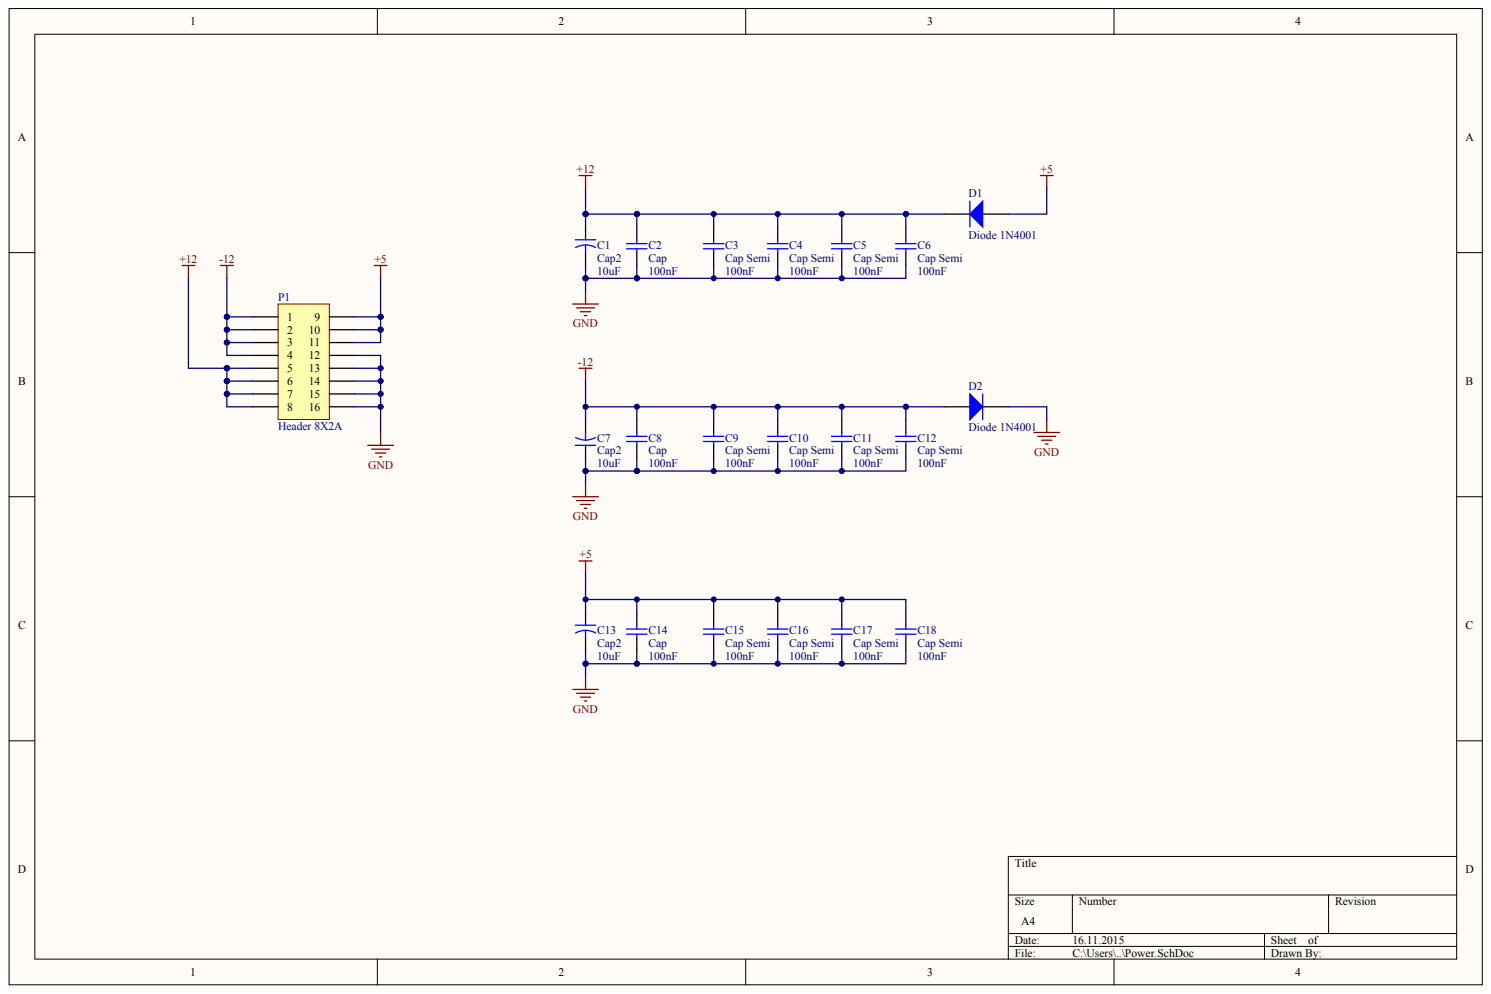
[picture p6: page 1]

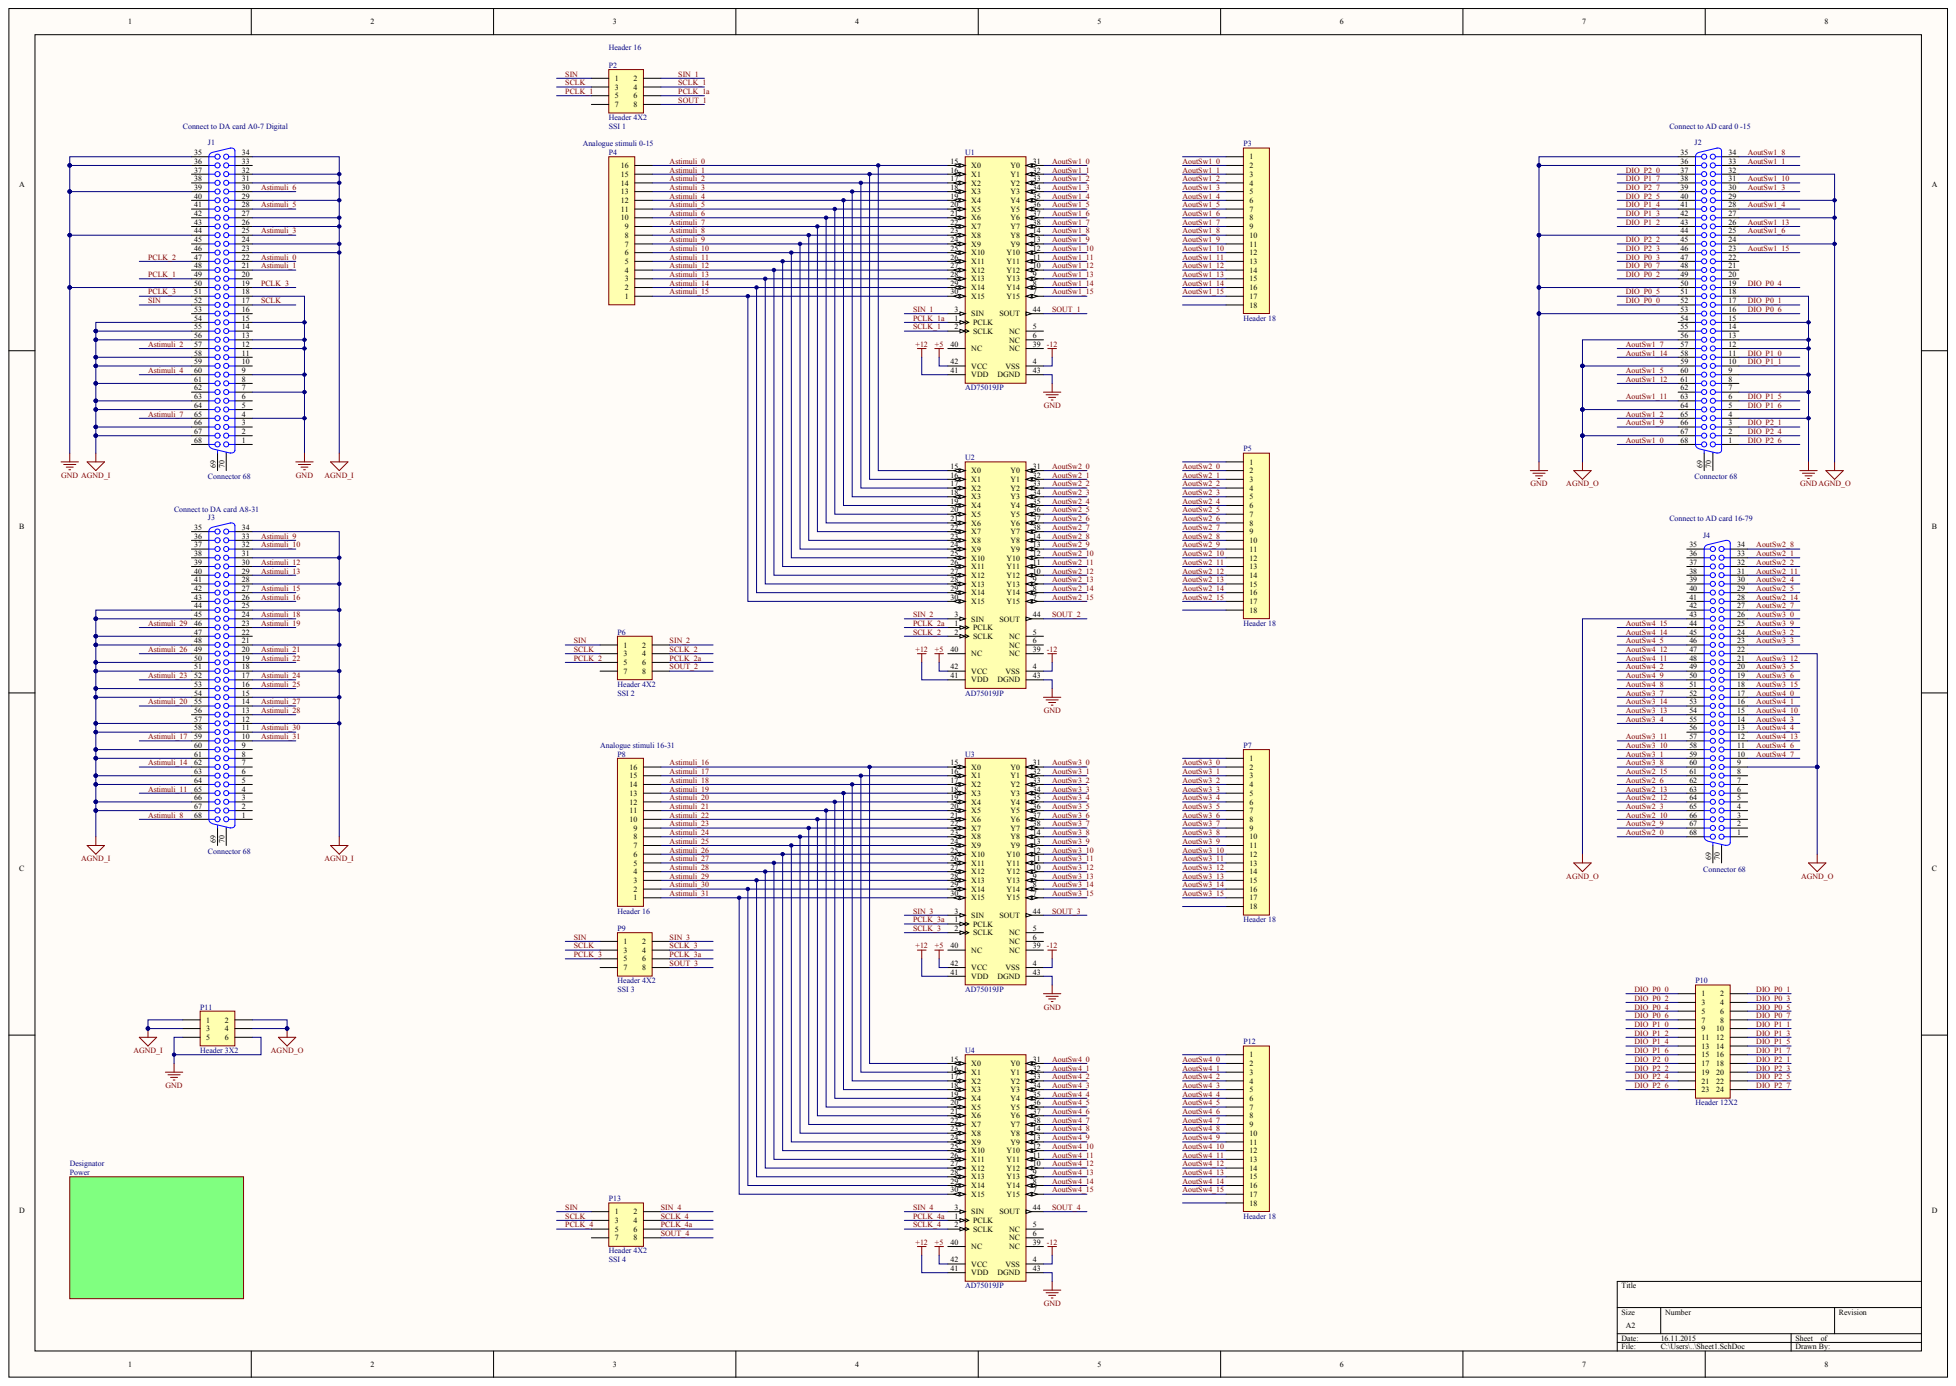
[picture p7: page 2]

Connect to DA card A8-31

Connect to AD card 16-79

Astimuli_25 | | | X9 24
Astimuli_26 | | | X10 25
Astimuli_27 | | | X11 26
Astimuli_28 | | | X12 27
Astimuli_29 | | | X13 28
Astimuli_30 | | | X14 29
Astimuli_31 | | | X15 30

SIN_3 PCLK_3a SCLK_3 +12 +5 | 3 1 2

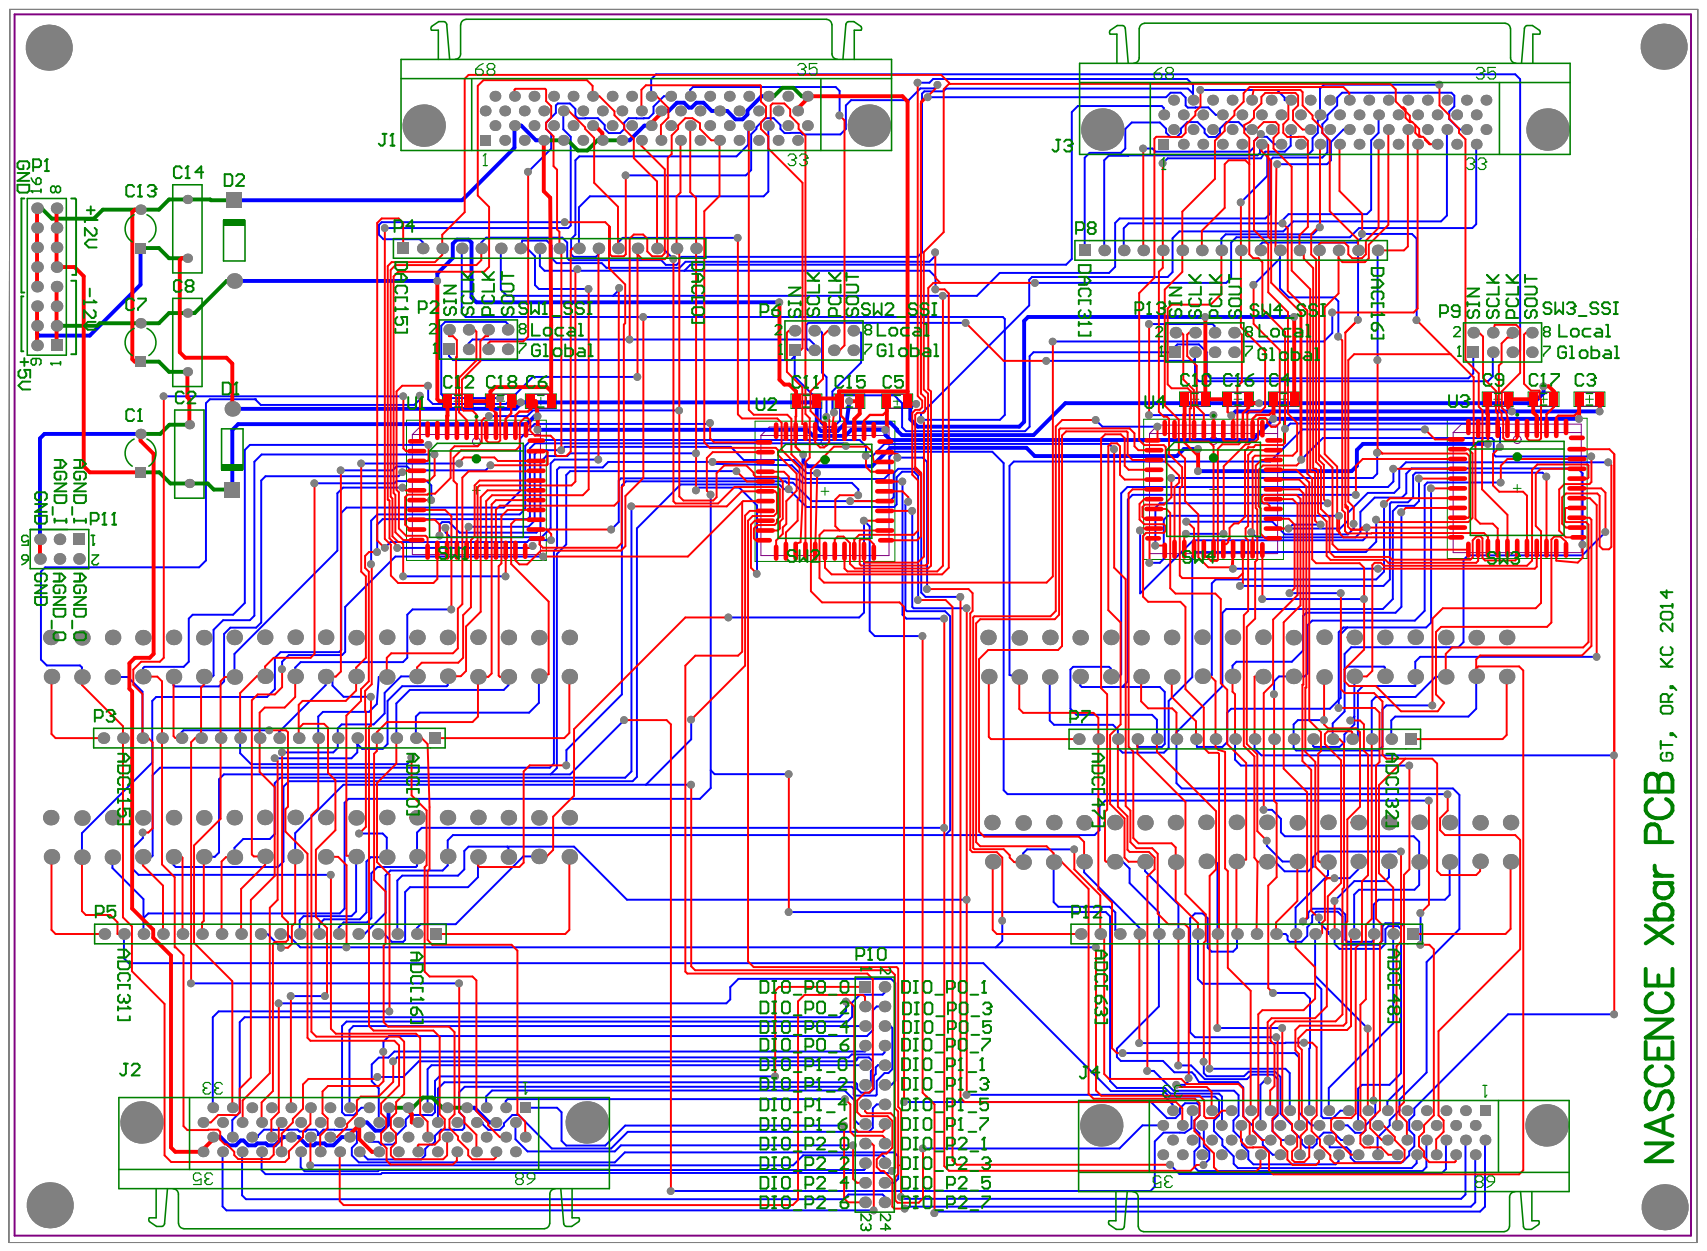
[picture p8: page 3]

Comment | Description | Designator | Footprint | LibRef | Quantity
Cap2 | Capacitor | C1, C7, C13 | CAPR5-4X5 | Cap2 | 3
Cap | Capacitor | C2, C8, C14 | RAD-0.3 | Cap | 3
Cap Semi | Capacitor (Semiconductor SIM Model) | C3, C4, C5, C6, C9, C10, C11, C12, C15, C16, C17, C18 | C1206 | Cap Semi | 12
Diode 1N4001 | 1 Amp General Purpose Rectifier | D1, D2 | DO-41 | Diode 1N4001 | 2
Connector 68 | Receptacle Header Assemby | J1, J2, J3, J4 | CHAMP1.27-2H68 | Connector 68 | 4
Header 8X2A | Header, 8-Pin, Dual row | P1 | HDR2X8_CEN | Header 8X2A | 1
Header 4X2 | Header, 4-Pin, Dual row | P2, P6, P9, P13 | HDR2X4 | Header 4X2 | 4
Header 18 | Header, 18-Pin | P3, P5, P7, P12 | HDR1X18 | Header 18 | 4
Header 16 | Header, 16-Pin | P4, P8 | HDR1X16 | Header 16 | 2
Header 12X2 | Header, 12-Pin, Dual row | P10 | HDR2X12 | Header 12X2 | 1
Header 3X2 | Header, 3-Pin, Dual row | P11 | HDR2X3 | Header 3X2 | 1
AD75019JP | 16 x 16 Crosspoint Switch Array, +/-12 V Supply, 44-pin LCC (P-44A), Tube | U1 | ADI-P-44A_L | CMP-0788-00031-1 | 1
AD75019JP | 16 x 16 Crosspoint SwitchU 2, U3, U4 | | ADI-P- 44A_ N | CMP-0788-00031-1 | 3

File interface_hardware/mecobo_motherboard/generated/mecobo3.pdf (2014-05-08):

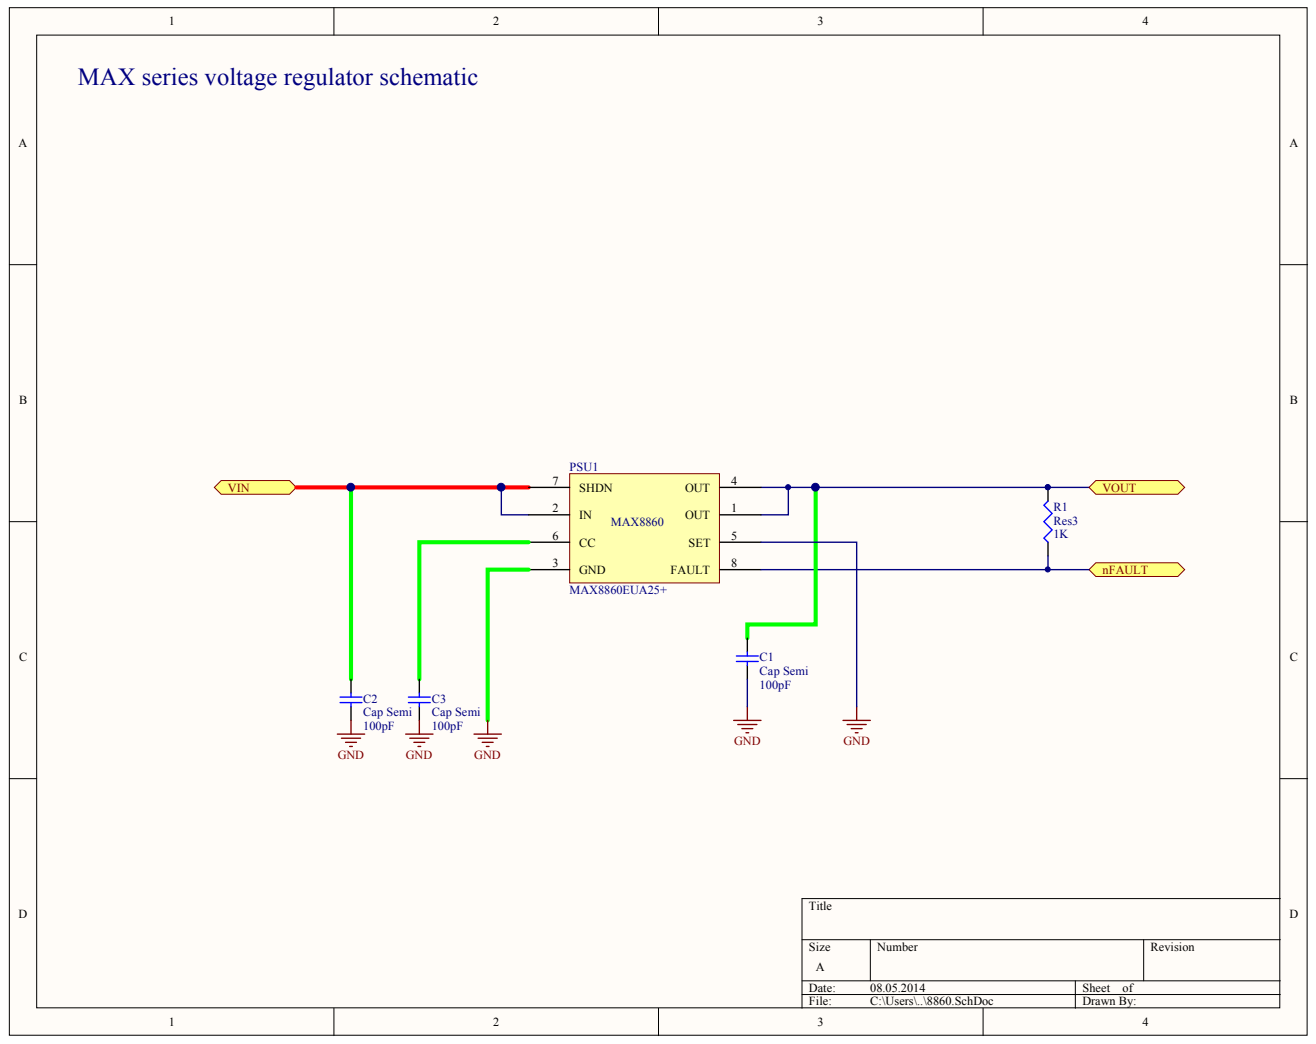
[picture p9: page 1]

X series voltage regulator schematic

A | r | R evision

Date : 08.05.2014 | She et of
File : C:\Use rs\..\8860.S chDoc | Dr awn By:

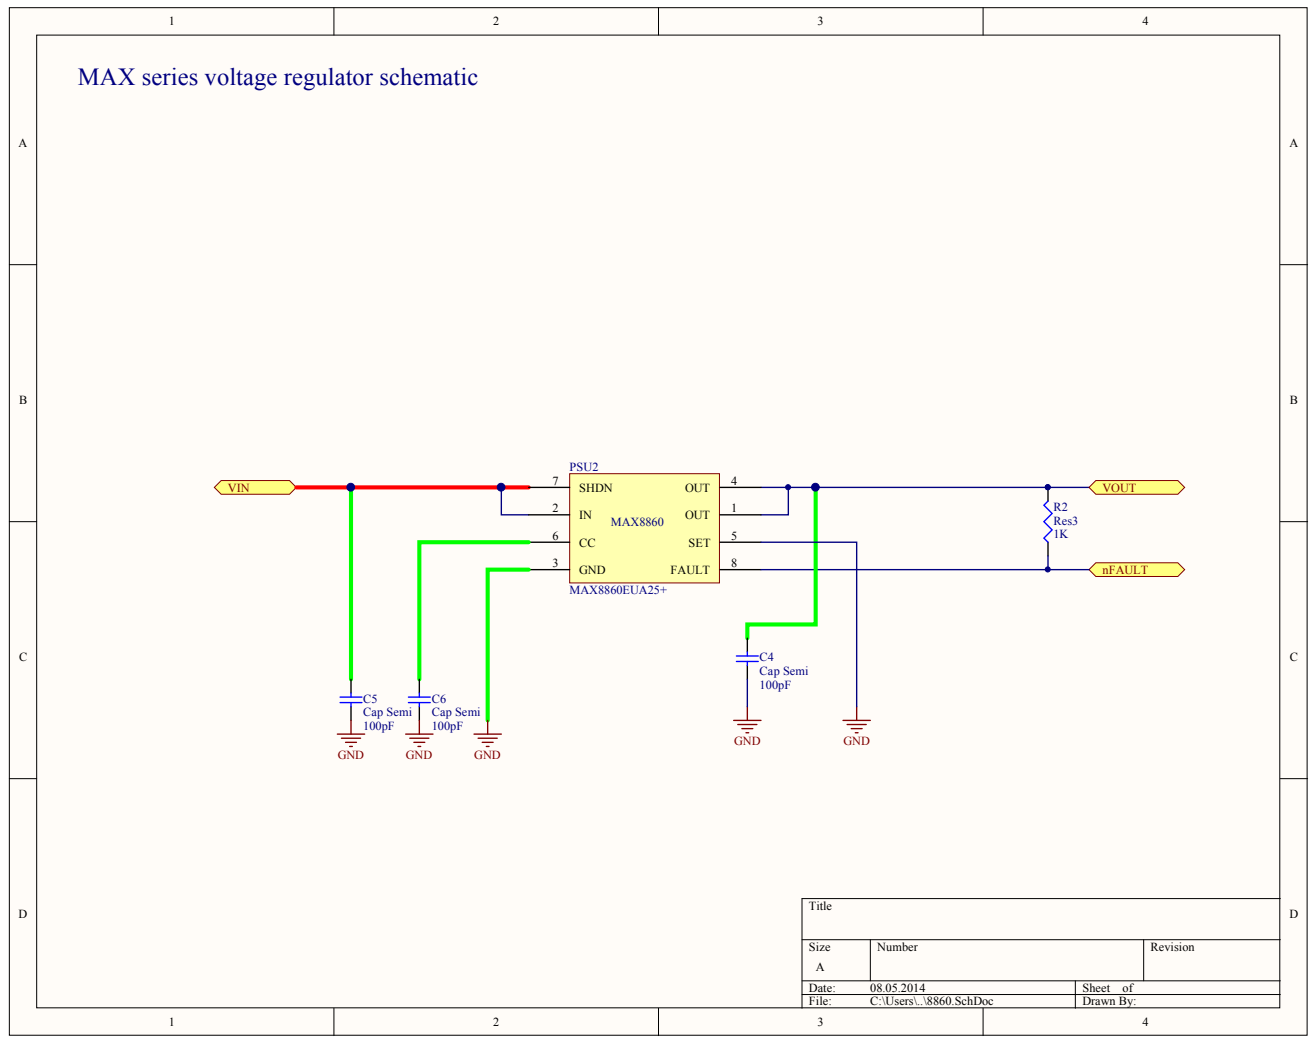
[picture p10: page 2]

X series voltage regulator schematic

r | R evision

Date
File C:\Use rs\..\8860.S chDoc | Dr awn By:

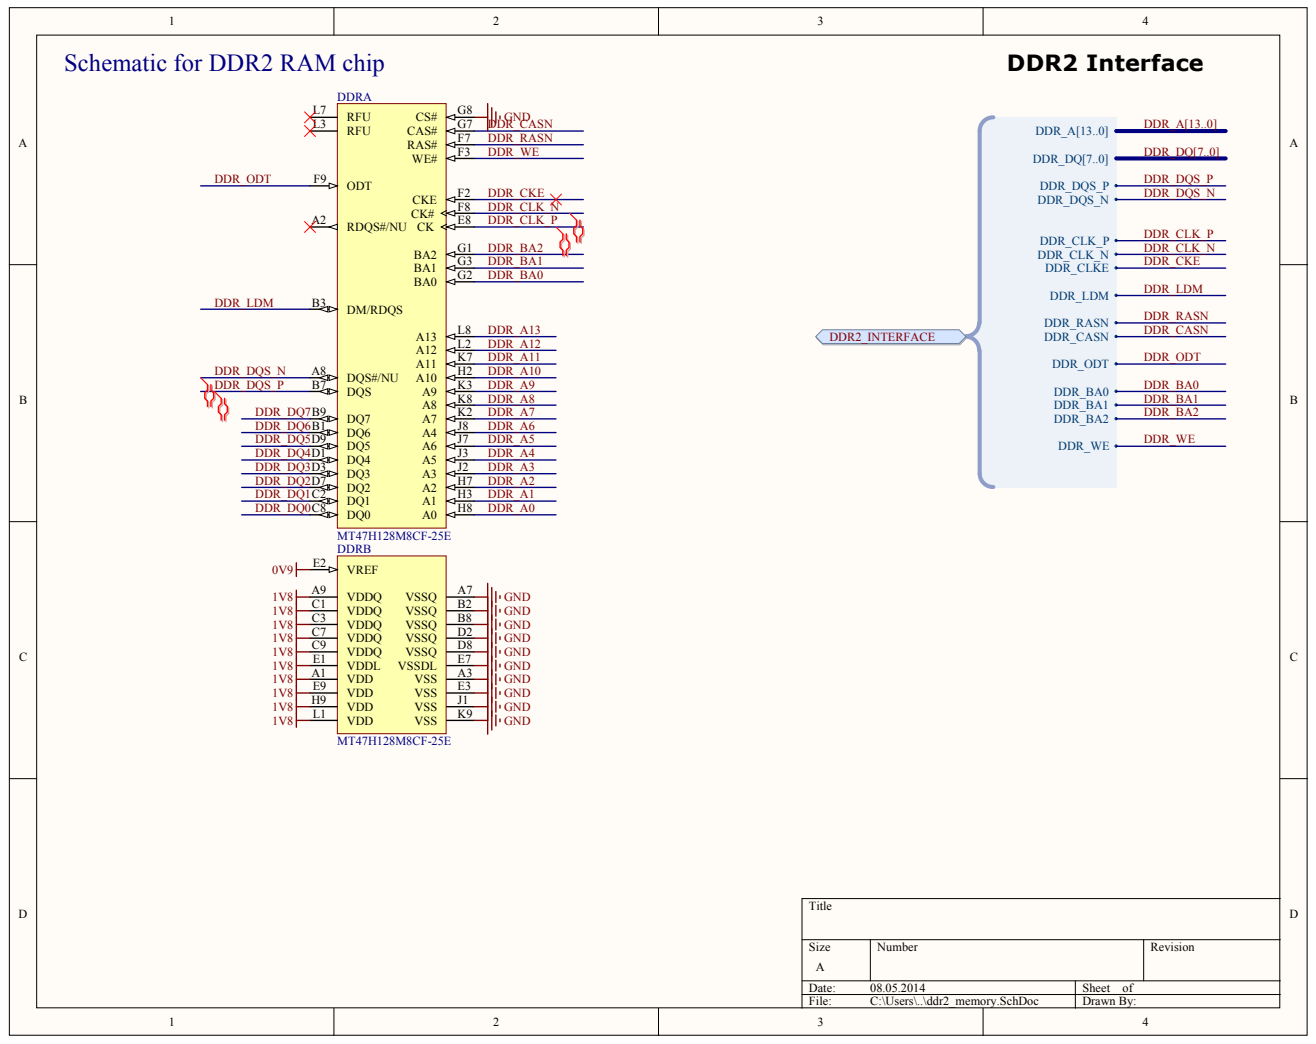
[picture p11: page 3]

C 1 | B 2
C 3 | B

r | R evision

Date
File C:\Use rs\..\ddr2_memory.S chDoc | Dr awn By:

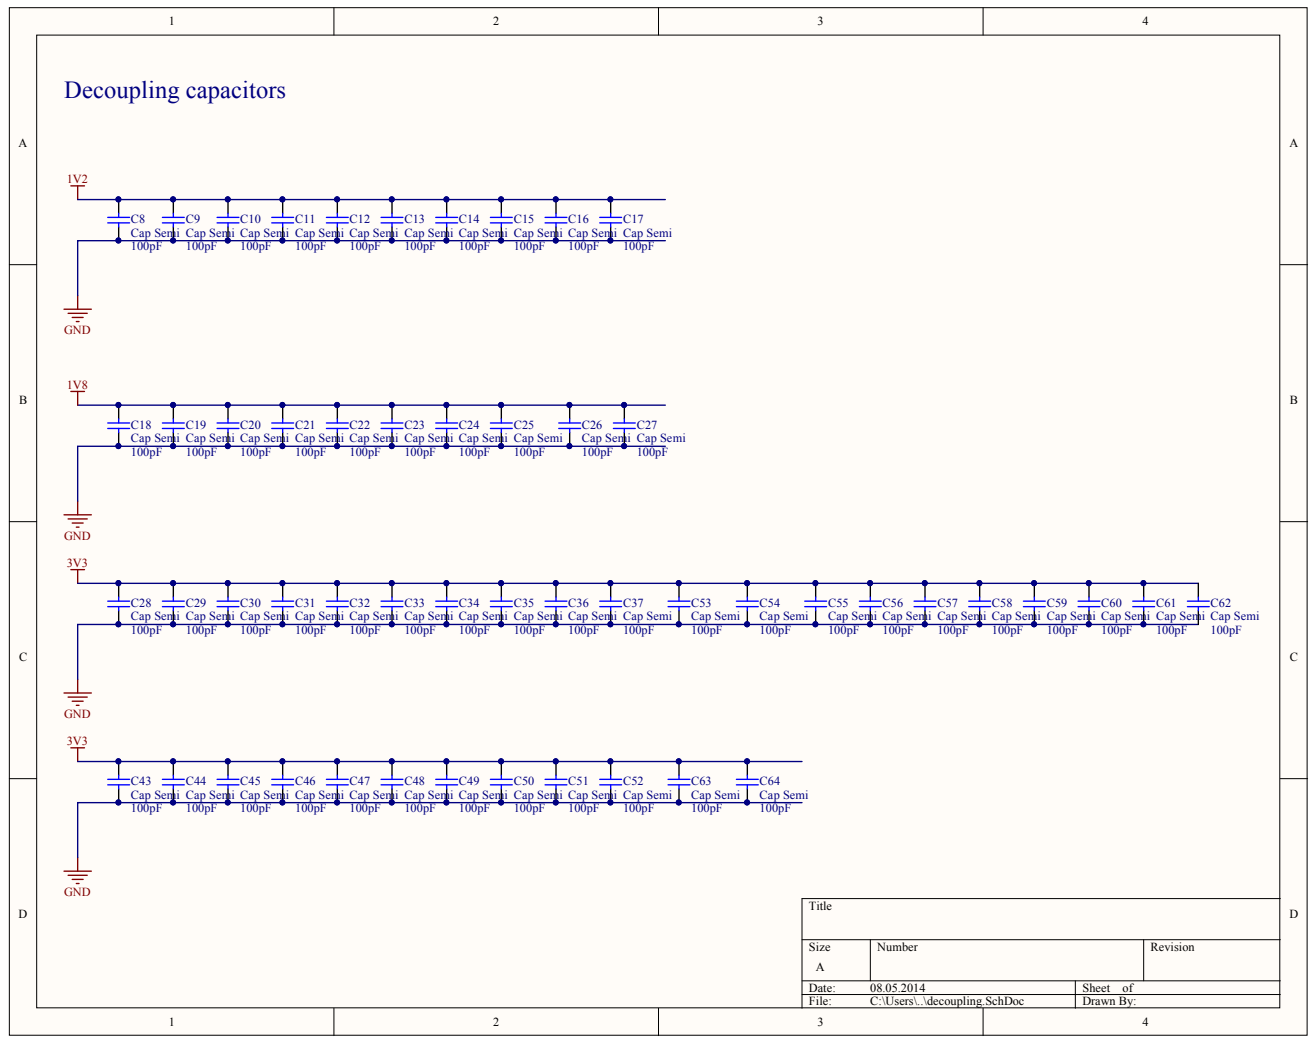
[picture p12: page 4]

Size | Number | Revision

Date: 08.05.2014 | Sheet of
File: C:\Users\..\decoupling.SchDoc | Drawn By:

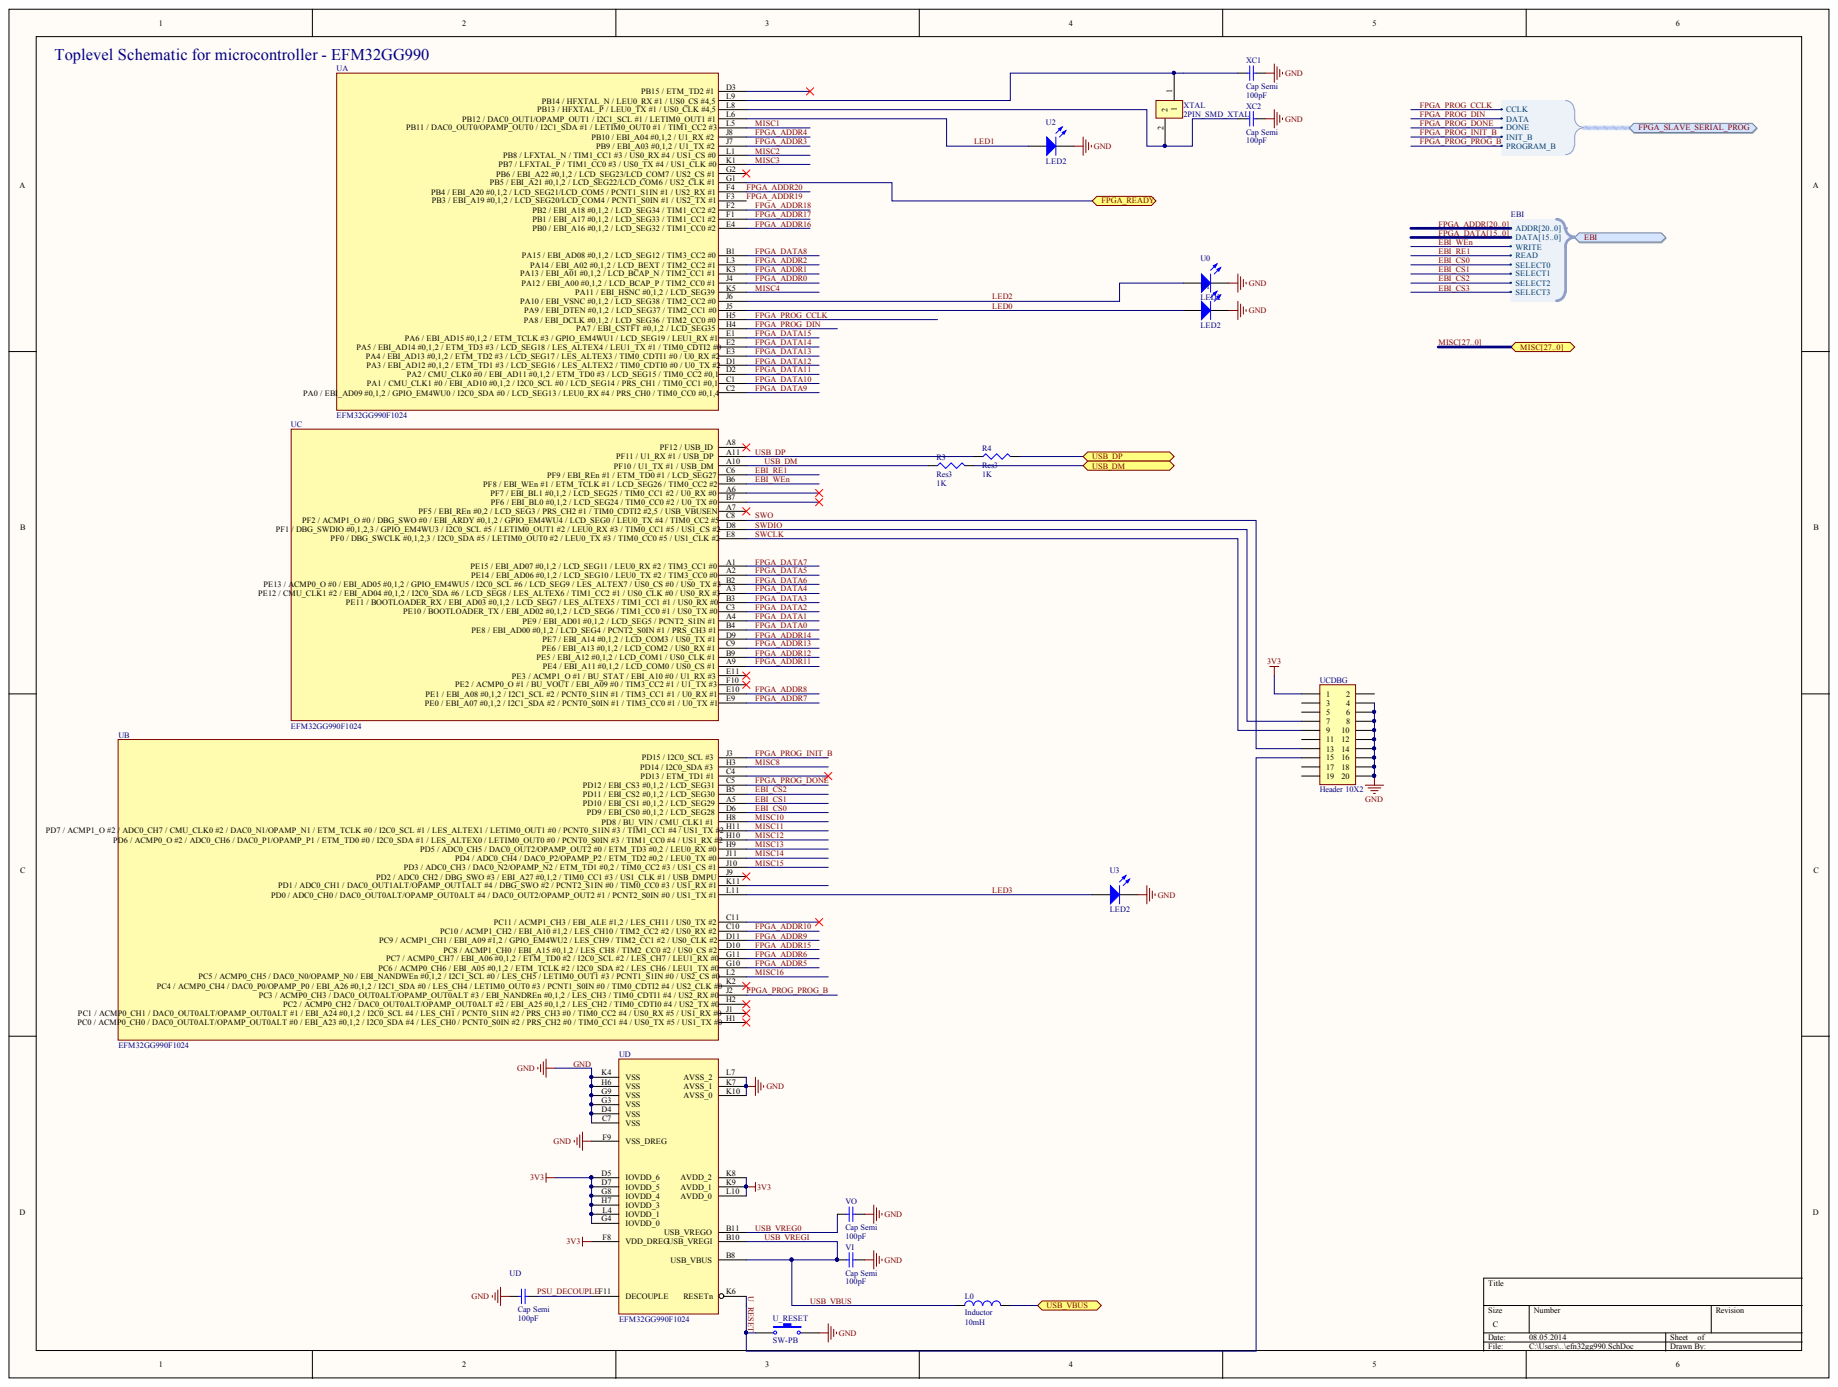
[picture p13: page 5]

U_R | S emi 100pF US B_VBUS

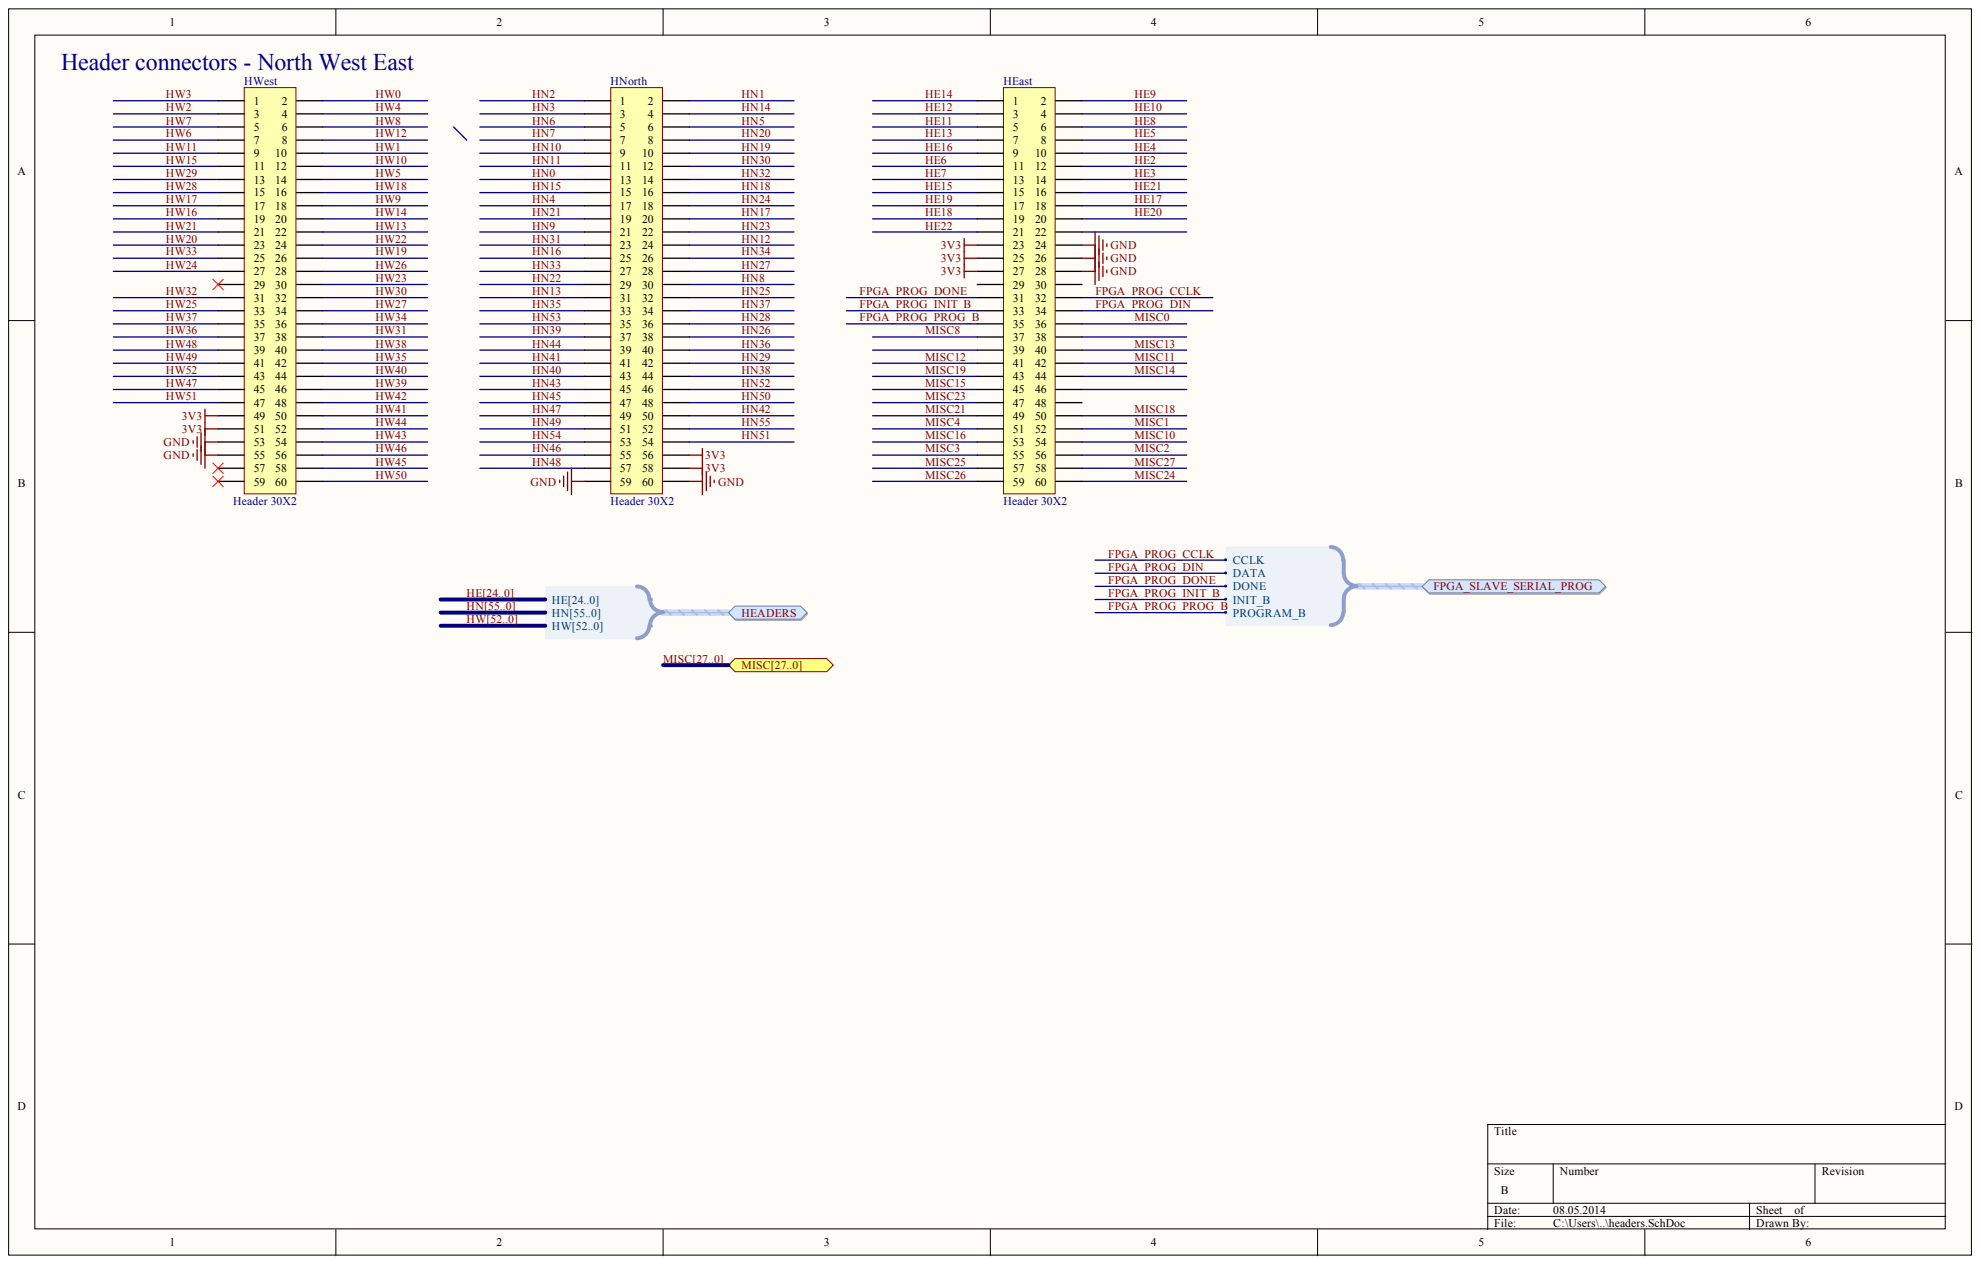
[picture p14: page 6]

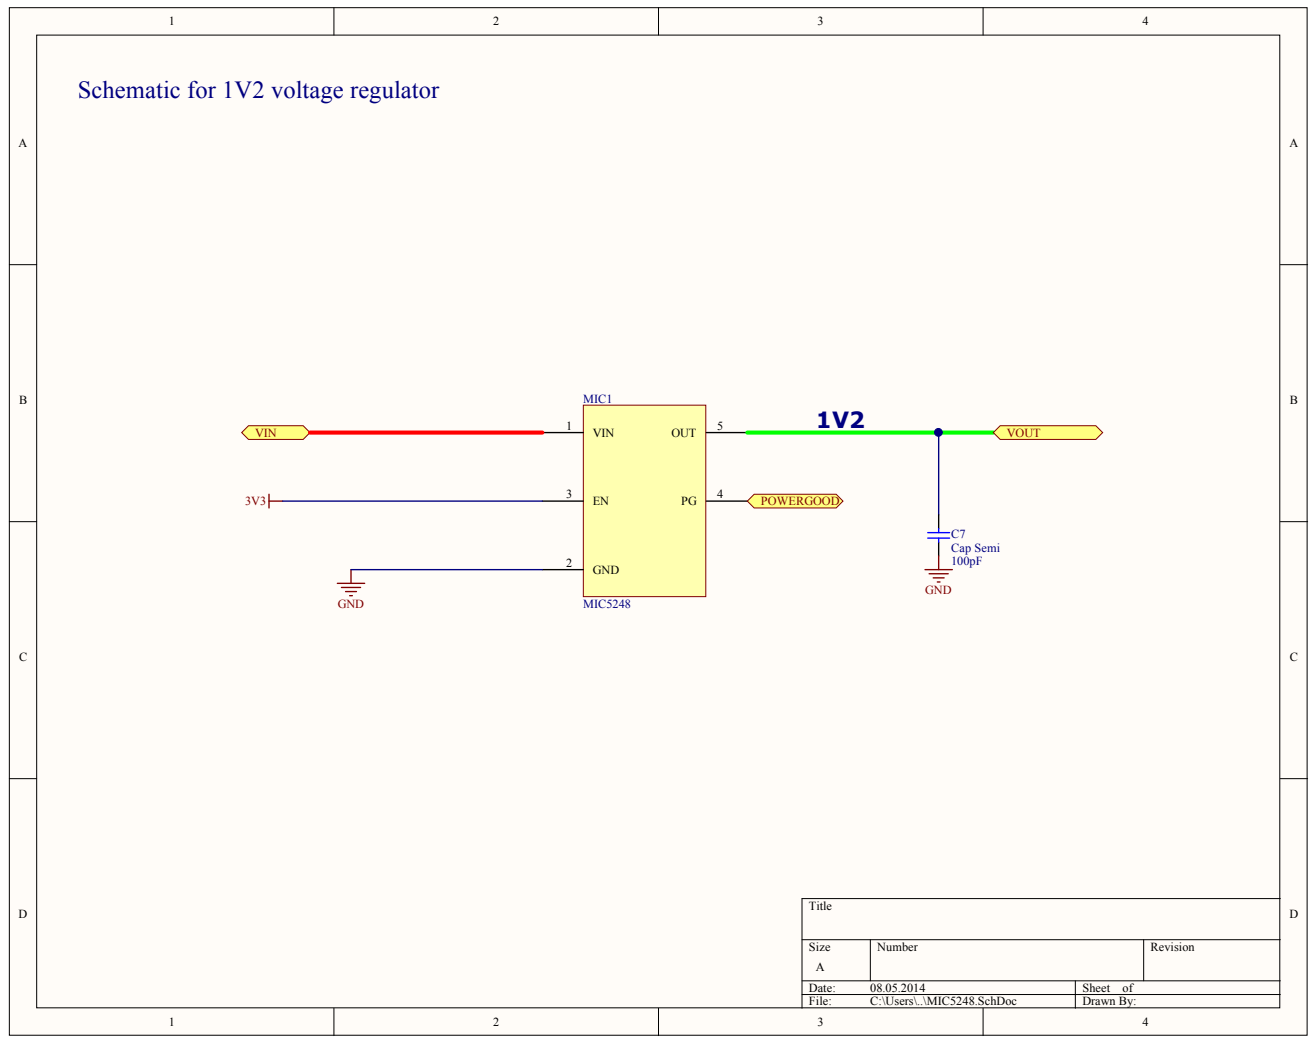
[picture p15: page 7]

Schematic for 1V2 voltage regulator

Size | Number | Revision

Date: 08.05.2014 | Sheet of
File: C:\Users\..\MIC5248.SchDoc | Drawn By:

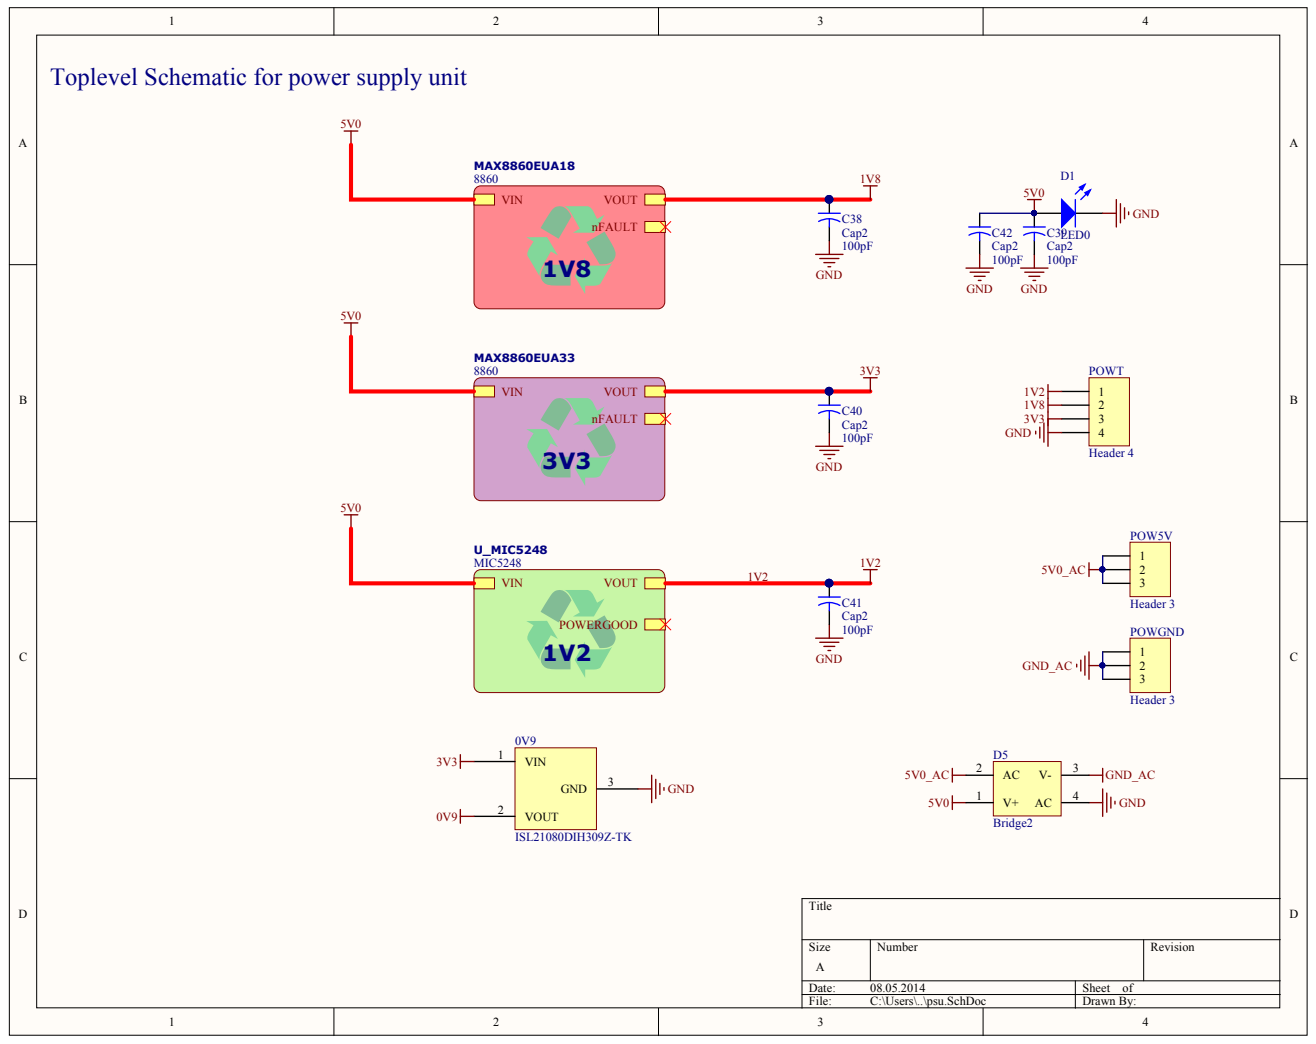
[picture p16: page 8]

Toplevel Schematic for power supply unit

Size | Number | Revision

Date: 08.05.2014 | Sheet of
File: C:\Users\..\psu.SchDoc | Drawn By:

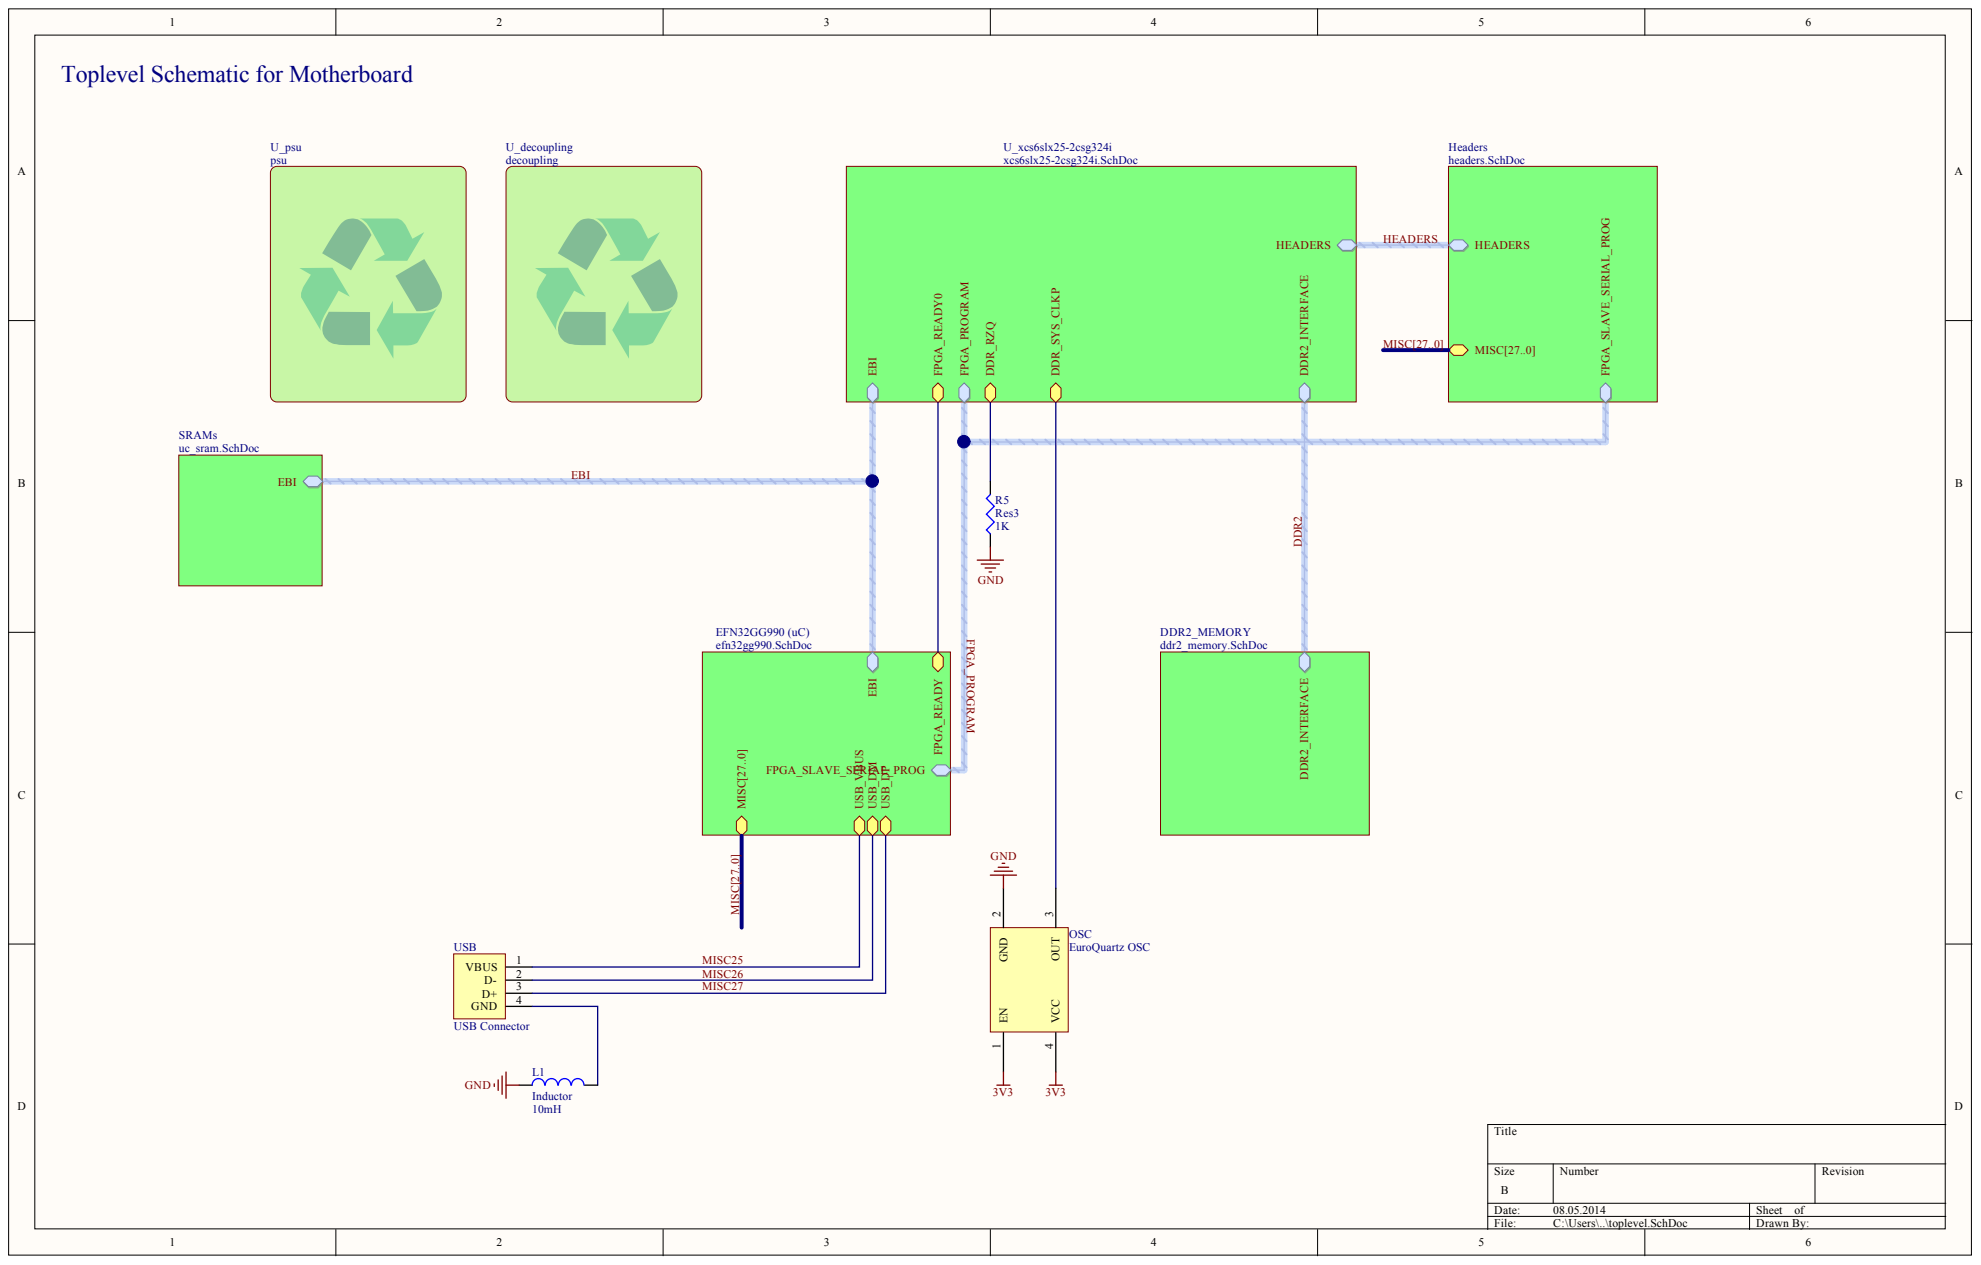
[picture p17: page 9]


r | R evision

Date
File C:\Use rs\..\uc_sr am.S chDoc | Dr awn By:


GND A1 GND A18 GND B13 GND B7 GND C16 GND C3 GND D10 GND D5 GND E15 GND G12 GND G17 GND G2 GND G5 GND H10 GND H8 GND J11 GND J15 GND J4 GND J9 GND K10 GND K8 GND L11 GND L9 GND M17 GND M2 GND M6 GND N13 GND R1 GND R14 GND R18 GND R4 GND R9 GND T16 GND U12 GND U6 GND V1 GND V18


# Board S

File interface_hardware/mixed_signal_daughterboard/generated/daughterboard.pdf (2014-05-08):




Connect_14 | | Connect_14
Connect_13 | | Connect_13
Connect_12 | | Connect_12
Connect_11 | | Connect_11

Connect_9 | | Connect_9
Connect_8 | | Connect_8
Connect_7 | | Connect_7
Connect_6 | | Connect_6
Connect_5 | | Connect_5
Connect_4 | | Connect_4
Connect_3 | | Connect_3
Connect_2 | | Connect_2
Connect_1 | | Connect_1
Connect_0 | | Connect_0


Decopling analogue output buffers

XGND | | C9 | C10

100nF | 10uF | LT1963AEQ | R18 Res3 10K | 100nF

6 | 4 | Res3 SHDN


DIN 15 SCLK 16 | 5

DOUT 18 | 9


# Board S

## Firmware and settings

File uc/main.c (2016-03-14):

////LEDS on front case (left to right):
//GPIO_PinModeSet(gpioPortD, 4, gpioModePushPull, 1);  //Led 1
//GPIO_PinModeSet(gpioPortB, 11, gpioModePushPull, 1);  //Led 2
//GPIO_PinModeSet(gpioPortD, 8, gpioModePushPull, 1);  //Led 3
//GPIO_PinModeSet(gpioPortB, 8, gpioModePushPull, 1);  //Led 4

//LEDS on board "north to south"
//A10 : U0
//A9: U1
//B12: U2
//D5: U3
//GPIO_PinModeSet(gpioPortA, 10, gpioModePushPull, 1);  //Led U0
//GPIO_PinModeSet(gpioPortA, 9, gpioModePushPull, 1);  //Led U1
//GPIO_PinModeSet(gpioPortB, 12, gpioModePushPull, 1);  //Led U2



/*
 * Listen to the interrupt! It will be raised if any of the
 * FIFOs are full, empty or any other stuff stuff happens.
 */

#include <stdio.h>

#include "em_dma.h"
#include "em_gpio.h"
#include "em_int.h"
#include "dmactrl.h"
#include "em_usb.h"
#include "em_usart.h"
#include "em_ebi.h"
#include "em_timer.h"
#include "bsp.h"
#include "bsp_trace.h"
#include "norflash.h"

#include <math.h>
#include <stdlib.h>
#include <string.h>
#include <inttypes.h>

#include "efm32.h"
#include "../mecoprot.h"
#include "mecobo.h"
#include "pinItem.h"

#include "descriptors.h"

#include "dac.h"
#include "adc.h"


#include "fifo.h"

/* USB STRUCTS */
static const USBD_Callbacks_TypeDef callbacks =
{
    .usbReset        = NULL,
    .usbStateChange  = UsbStateChange,
    .setupCmd        = NULL,
    .isSelfPowered   = NULL,
    .sofInt          = NULL
};

const USBD_Init_TypeDef initstruct =
{
    .deviceDescriptor    = &USBDESC_deviceDesc,
    .configDescriptor    = USBDESC_configDesc,
    .stringDescriptors   = USBDESC_strings,
    .numberOfStrings     = sizeof(USBDESC_strings)/sizeof(void*),
    .callbacks           = &callbacks,
    .bufferingMultiplier = USBDESC_bufferingMultiplier,
    .reserved            = 0
};



struct fifo ucCmdFifo;
struct fifo ucSampleFifo;

#define MAGIC_FPGA_BITFILE_CONSTANT 0x4242
#define USB_MAX_SAMPLES 64000/sizeof(struct sampleValue)
//#define USB_MAX_SAMPLES 1000

char * BUILD_VERSION = __GIT_COMMIT__;

int NORPollData(uint16_t writtenWord, uint32_t addr);

#define FPGA_SYSTEM_CLK_RATE 75000000  //FPGA runs at 100MHz
//override newlib function.
int _write_r(void *reent, int fd, char *ptr, size_t len)
{
    (void) reent;
    (void) fd;
    for(size_t i = 0; i < len; i++) 
        ITM_SendChar(ptr[i]);

    return len;
}

static const int FPGA_CMD_FIFO_SIZE = 2000; //actually 1024, but we'll just be conservative
static const int UC_CMD_FIFO_SIZE = 2048;

static uint16_t roomInFpgaCmdFifo = 0;
uint16_t statusReg = 0;

int timeStarted = 0; 
static uint8_t mecoboStatus = MECOBO_STATUS_READY;

/*** Typedef's and defines. ***/

static int has_daughterboard = 0;
static int xbarProgrammed = 0;
static int setupFinished = 0;


//Keeps track of number of recording units on FPGA
static int numUnits = 0;
//USB Variables

static uint32_t inBufferTop;
static uint8_t * inBuffer;

static struct mecoPack currentPack;
static struct mecoPack packToSend;
static int sendPackReady = 0;
static int sendInProgress = 0;
static int executeInProgress = 0;

static int feedFpgaCmdFifo = 1;
static int sampleFifoEmpty = 1;
static int samplesToGet = 0;

//Are we programming the FPGA
int fpgaConfigured = 0;
uint32_t bitfileOffset = 0;
uint32_t lastPackSize = 0;

static int firstSampleDiscarded = 0;

#define MAX_INPUT_CHANNELS 50
static int fpgaTableIndex = 0;
static uint16_t fpgaTableToChannel[MAX_INPUT_CHANNELS];

static volatile uint16_t * cmdInterfaceAddr = (uint16_t*)EBI_ADDR_BASE;

#define NUM_DAC_REGS 4
uint16_t DACreg[NUM_DAC_REGS];
uint8_t registersUpdated[NUM_DAC_REGS];

//Circular buffer in SRAM1, modulo MAX_SAMPLES
static const int MAX_SAMPLES = 43689; //SRAM1_BYTES/sizeof(struct sampleValue);
#define MAX_CHANNELS 150

//ADC sequencer registers
uint16_t adcSequence[4] = {0xE000,0xE000,0xE000,0xE000};


static int blinky = 0;
void TIMER1_IRQHandler(void)
{ 
    /* Clear flag for TIMER2 overflow interrupt */
    TIMER_IntClear(TIMER1, TIMER_IF_OF);

    /* Toggle LED ON/OFF */
    if (blinky<5) {
        led(BOARD_LED_U0, 0);
    }  
    if (blinky == 10) {
        led(BOARD_LED_U0, 1);
        blinky = 0;
    }
    blinky++;

    //Retrieve sample value from pin controllers and queue them for sending. 
}

void TIMER2_IRQHandler(void)
{
    TIMER_IntClear(TIMER2, TIMER_IF_OF);
}

//"Update DAC tic" == fast clock that ticks. The frequency field of the 
//in-flight items decide if they are to be updated? 

int main(void)
{

    eADesigner_Init();

    setupSWOForPrint();
    infop("Print output online\n");

    //Small check for endinanness
    uint32_t integer = 0xDEADBABE;
    uint8_t * int8 = (uint8_t*)&integer;
    if(int8[0] == 0xDE) infop("Arch is BIG ENDIAN\n");
    if(int8[0] == 0xBE) infop("Arch is LITTLE ENDIAN\n");


    //Turn on front led 1 to indicate we are setting up the system.
    led(FRONT_LED_0, 1);

    //nor in reset
    GPIO_PinModeSet(gpioPortC, 2, gpioModePushPull, 1);  
    GPIO_PinOutClear(gpioPortC, 2); //active low

    //set byte mode
    GPIO_PinModeSet(gpioPortC, 1, gpioModePushPull, 1);  
    GPIO_PinOutSet(gpioPortC, 1); //active low

    //turn off write protect
    GPIO_PinModeSet(gpioPortB, 7, gpioModePushPull, 1);  
    GPIO_PinOutSet(gpioPortB, 7); //active low

    //nor out of reset
    GPIO_PinOutSet(gpioPortC, 2); //active low


    inBuffer = (uint8_t*)malloc(128*8);
    inBufferTop = 0;

    //Put FPGA out of reset
    GPIO_PinModeSet(gpioPortB, 5, gpioModePushPull, 1);  
    GPIO_PinOutSet(gpioPortB, 5); //Reset
    GPIO_PinOutClear(gpioPortB, 5); //Reset clear


    sendPackReady = 0;

    //Make sure NOR has come up.
    for(int norwait = 0; norwait < 10000000; norwait++);


    has_daughterboard = 0;
    int skip_boot_tests= 0;

    if(!skip_boot_tests) {

        //testNOR();
        testRam();
    }



    infop("Initializing USB\n");
    USBD_Init(&initstruct);
    infop("USB Initialized.\n");
    USBD_Disconnect();
    USBTIMER_DelayMs(100);
    USBD_Connect();
    led(BOARD_LED_U3, 1);

    setupADC();
    setupDAC();
 
    infop("Cycling LEDs :-)\n");
    
//Cycle leds.
        for(int i = 0; i < 48; i++) {
            led(i%8, 1);
            USBTIMER_DelayMs(60);
            led(i%8, 0);
        }


    infop("It's just turtles all the way down.\n");
    infop("I'm the mecobo firmware running on the evolutionary motherboard 3.5new.\n");
    infop("I was built %s, git commit %s\n", __DATE__, BUILD_VERSION);
    infop("Entering main loop.\n");


    fifoInit(&ucCmdFifo, UC_CMD_FIFO_SIZE, sizeof(struct pinItem), NULL);
    fifoInit(&ucSampleFifo, 10000, sizeof(struct sampleValue), (uint8_t *)SRAM2_START);

    /* MAIN LOOP */
    resetTime();


    roomInFpgaCmdFifo = FPGA_CMD_FIFO_SIZE - cmdFifoDataCount();

    struct sampleValue sample; 
    uint16_t tableIndex;
    uint16_t data;

    for (;;) {

        //feed if fifo is more than 3/5 empty
        if(roomInFpgaCmdFifo < 1750) {
            roomInFpgaCmdFifo = FPGA_CMD_FIFO_SIZE - cmdFifoDataCount();
        }
        //We want to be able to feed the fifo even if the sequenc run is not started
        if (setupFinished && (roomInFpgaCmdFifo > 10) && (ucCmdFifo.numElements > 0)) {
            //mecoboStatus = MECOBO_STATUS_BUSY;
            // while(ucCmdFifo.numElements > 0) {
            debug("fifo feed: %u\n", roomInFpgaCmdFifo);
            void * item = NULL;
            fifoGet(&ucCmdFifo, &item);
            struct pinItem * it = (struct pinItem *)item;
            pushToCmdFifo(it);
        }

        //Check how many samples are in the FIFO, we have to get them anyway
        //so no need to check until we've gotten them anyway.

        if(timeStarted && (samplesToGet <= 0)) {
            samplesToGet = sampleFifoDataCount();
        }


        //sampleFifoDataCount();
        if ((samplesToGet>0) && timeStarted && !fifoFull(&ucSampleFifo)) {


            debug("samplesToget: %d\n", samplesToGet);
            //Push samples into fifo
            //sample.sampleNum = numSamples++;
            //for(int i = 0; i < samplesToGet; i++) {

             //   if(!fifoFull(&ucSampleFifo)) {
                    if(!firstSampleDiscarded) {
                        firstSampleDiscarded = 1;
                        ebir(6);
                    } else {
                        data = ebir(6);
                        
                        int tableIndexShift = has_daughterboard ? 13 : 1;   //the 1 is for just looking at the controller ID
                        tableIndex = (data >> tableIndexShift); //top 3 bits of word is index in fpga controller fetch table

                        sample.channel = has_daughterboard ? fpgaTableToChannel[tableIndex] : tableIndex;
                        sample.value = (int16_t)data;
                        fifoInsert(&ucSampleFifo, &sample);  
                        samplesToGet--;
                        debug("d %x s %x, ch %x, v %d i %u sh %d\n", data, sample.sampleNum, sample.channel, sample.value, tableIndex, tableIndexShift);
                    }
                  //  }
            //}



        }
    }
}


void softReset()
{
    ebiw(7, 0xD00D);
    infop("Soft system reset.\n");
}


void runTime()
{
    ebiw(7, 0xDEAD);
    infop("T run, tim: %x\n", cmdInterfaceAddr[9]);
}

void resetTime()
{
    ebiw(7, 0xBEEF);
    infop("T res, tim: %x\n", cmdInterfaceAddr[9]);
}

int UsbHeaderReceived(USB_Status_TypeDef status,
        uint32_t xf,
        uint32_t remaining) 
{
    (void) remaining;
    int gotHeader = 0;

    //idle while send finishes if we're doing that.
    //This is supposed to fix the race where this routine would be called
    //before we were finished with freeing data from the old 
    //package.
    while(sendInProgress && executeInProgress);

    if ((status == USB_STATUS_OK) && (xf > 0)) {
        //Got some data, check if we have header.
        if (xf == 8) {
            uint32_t * inBuffer32 = (uint32_t *)inBuffer;
            currentPack.size = inBuffer32[0]; 
            currentPack.command = inBuffer32[1];
            currentPack.data = NULL;
            gotHeader = 1;
        } else {
            debug("Expected header of size 8, got %u.\n", (unsigned int)xf);
        }
    }

    //Check that we're still good, and get some data for this pack.
    if (USBD_GetUsbState() == USBD_STATE_CONFIGURED) {
        if(gotHeader) {
            if(currentPack.size > 0) {
                //Go to data collection.
                currentPack.data = (uint8_t*)malloc(currentPack.size);
                if(currentPack.data == NULL) {
                    debug("currentPack.data malloc null :( \n");
                } 

                USBD_Read(CDC_EP_DATA_OUT, currentPack.data, currentPack.size, UsbDataReceived);
            } else {
                //Only header command, so we can parse it, and will not wait for data.
                execCurrentPack();
                //And wait for new header.
                if (USBD_GetUsbState() == USBD_STATE_CONFIGURED) {
                    USBD_Read(CDC_EP_DATA_OUT, inBuffer, 8, UsbHeaderReceived); //get new header.
                }
            }
        } else {
            USBD_Read(CDC_EP_DATA_OUT, inBuffer, 8, UsbHeaderReceived);
        }
    }

    return USB_STATUS_OK;
}


//Set up callback to always wait for a new pack of 8 bytes
int UsbDataReceived(USB_Status_TypeDef status,
        uint32_t xf,
        uint32_t remaining) 
{
    (void) remaining;
    if ((status == USB_STATUS_OK) && (xf > 0)) {
        execCurrentPack();
    }

    //Check that we're still good, and wait for a new header.
    if (USBD_GetUsbState() == USBD_STATE_CONFIGURED) {
        USBD_Read(CDC_EP_DATA_OUT, inBuffer, 8, UsbHeaderReceived); //get new header.
    }
    return USB_STATUS_OK;
}




int UsbDataSent(USB_Status_TypeDef status,
        uint32_t xf,
        uint32_t remaining)
{
    (void) remaining;

    if ((status == USB_STATUS_OK) && (xf > 0)) {
        //we probably sent some data :-)
        //don't free this command it just sends back a status
        //    if(packToSend.command != USB_CMD_STATUS) {
        if(packToSend.data != NULL) {
            free(packToSend.data);
        } else {
            debug("Tried to free NULL-pointer\n");
        }

    }
    sendInProgress = 0;

    return USB_STATUS_OK;
}

void UsbStateChange(USBD_State_TypeDef oldState, USBD_State_TypeDef newState)
{
    (void) oldState;
    if (newState == USBD_STATE_CONFIGURED) {
        USBD_Read(CDC_EP_DATA_OUT, inBuffer, 8, UsbHeaderReceived);
    }

}

void ebiw(uint32_t addr, uint16_t data) {
    *(cmdInterfaceAddr + addr) = data;
    trace("w %x %x\n", (uint32_t)(addr), data);
}

uint16_t ebir(uint32_t addr) {
    uint16_t d = cmdInterfaceAddr[addr];
    trace("r %x %x\n", addr, d);
    return d;
}


void setupInput(FPGA_IO_Pins_TypeDef channel, int sampleRate, uint32_t startTime, uint32_t endTime)
{
    mecoboStatus = MECOBO_STATUS_BUSY;

    //Hack to avoid start time 0 which is a special sentinent value that indicates 
    //that no recording has been scheduled on that pin.
    if(startTime == 0) {
        startTime = 1;
        endTime++;
    }
    //We are in setup phase. maybe ok.

    command(0, SAMPLE_COLLECTOR_ADDR, SAMPLE_COLLECTOR_REG_NEW_UNIT, channel);  //set up the sample collector to this channel
    fpgaTableToChannel[fpgaTableIndex] = (uint16_t)channel;
    debug("Rec Channel %u added, index %u, table entry %d\n", channel, fpgaTableIndex, (uint16_t)fpgaTableToChannel[fpgaTableIndex]);

    command(0, SAMPLE_COLLECTOR_ADDR, SAMPLE_COLLECTOR_REG_NUM_UNITS, ++numUnits);  //set up the sample collector to this channel
    //How many samples?
    //The overflow register is what decides this.
   
    infop("sampleRate in: %d\n", sampleRate);
    double overflow = 0;
    if (sampleRate != 0) {
        overflow = (float)FPGA_SYSTEM_CLK_RATE/(float)sampleRate;   //this is the period length of the 100MHz sample rate counter clock
        infop("Overflow register: %f\n", overflow);
    } else {
        debug("SampleRate is 0. Set to 1000\n");
        overflow = 1000.0;
    }
    fpgaTableIndex++;

    //If it's a ADC channel we set up the ADC here in stead of all this other faff.
    if ((AD_CHANNELS_START <= channel) && (channel <= (AD_CHANNELS_END))) {

        //find the ADC's internal number for the channel to program it.
        uint16_t boardChan = channel - AD_CHANNELS_START;
        //board 0
//        if(boardChan < 16) {
            //Program sequence register with channel.
            adcSequence[0] |= 0xE000 | (1 << (12 - boardChan));
            debug("ADCregister write channel %x, %x\n", boardChan, adcSequence[0]);

            command(0, channel, AD_REG_OVERFLOW, (uint32_t)overflow);
            command(0, channel, AD_REG_ENDTIME, (uint32_t)endTime);
            command(0, channel, AD_REG_REC_START_TIME, (uint32_t)startTime);
            //command(0, channel, AD_REG_DIVIDE, (uint32_t)1);

            command(0, channel, AD_REG_PROGRAM, 0x10000|(uint32_t)adcSequence[0]);

            //Program the ADC to use this channel as well now. Result in two comp, internal ref.
            //sequencer on.
            //Control register
            command(0, channel, AD_REG_PROGRAM, 0x18014);

            debug("ADC programmed to new sequences\n");
 //       }
    }

    //Digital channel.
    else {
        debug("Recording dig ch: %x\n", channel);
        command(0, channel, PINCONTROL_REG_LOCAL_CMD, PINCONTROL_CMD_RESET);  //reset pin controller to put it in idle
        command(0, channel, PINCONTROL_REG_SAMPLE_RATE, (uint32_t)overflow);
        command(0, channel, PINCONTROL_REG_END_TIME, (uint32_t)endTime);
        command(0, channel, PINCONTROL_REG_REC_START_TIME, (uint32_t)startTime);
    }


}


inline void startInput()
{
    command(0, SAMPLE_COLLECTOR_ADDR, SAMPLE_COLLECTOR_REG_LOCAL_CMD, SAMPLE_COLLECTOR_CMD_RES_SAMPLE_FIFO);  //this sends STAT SAMPLING COMMAND
    infop("Starting sampling\n");
    command(0, SAMPLE_COLLECTOR_ADDR, SAMPLE_COLLECTOR_REG_LOCAL_CMD, SAMPLE_COLLECTOR_CMD_START_SAMPLING);  //this sends STAT SAMPLING COMMAND
}
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

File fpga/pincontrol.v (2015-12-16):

module pincontrol ( clk,
reset,
enable,
addr,
data_wr,
data_rd,
data_in,
data_out,
pin,
output_sample,
channel_select,
sample_data,
current_time, 
global_clock_running,
busy
);



input clk;
input reset;
input enable;
input [15:0] addr;
input   [31:0] data_in;
//(* tristate2logic = "yes" *)
output reg [15:0] data_out;
inout pin;

input data_wr;
input data_rd;

input [31:0] current_time;
input global_clock_running;

input output_sample;
input [7:0] channel_select;
output reg [31:0] sample_data;
output reg busy;


parameter [14:0] POSITION = 0;

reg sample_register = 0;
reg [15:0] sample_cnt = 16'h0000;
reg [31:0] nco_counter = 32'h00000000;
reg [31:0] nco_pa = 0;
reg [31:0] end_time = 0;
reg [31:0] rec_start_time = 0;


wire pin_input;
wire enable_in = (enable & (addr[15:8] == POSITION[7:0]));
/*Input, output: PWM, SGEN, CONST */



/*These are byte addresses. */
localparam
ADDR_GLOBAL_CMD = 0,
ADDR_NCO_COUNTER = 1,
ADDR_END_TIME = 2,
ADDR_LOCAL_CMD =  3,
ADDR_SAMPLE_RATE =  4,
ADDR_SAMPLE_REG =  5,
ADDR_REC_START_TIME = 6,
ADDR_SAMPLE_CNT =  7,
ADDR_STATUS_REG =  8,
ADDR_LAST_DATA = 9;


localparam
CMD_CONST = 2,
CMD_CONST_NULL = 6,
CMD_SQUARE_WAVE = 3,
CMD_INPUT_STREAM = 4,
CMD_RESET = 5;

reg [31:0] command = 0;
reg [31:0] sample_rate = 0;
reg [31:0] cnt_sample_rate = 0;


/*outputs from state machine */
reg res_sample_counter = 0;
reg dec_sample_counter = 0;
reg update_data_out    = 0;
reg update_sample_cnt = 0;
reg enable_pin_output = 0;
reg const_output_null = 0;
reg const_output_one = 0;

localparam [4:0] 
idle =            5'b00001,
const =           5'b00010,
input_stream =    5'b00100,
enable_out =      5'b01000,
const_null =      5'b10000;

reg [4:0] state, nextState;


/* Command bus data output */
always @ (posedge clk) begin
    if(reset) begin
        sample_data <= 0;
        data_out <= 0;
    end else begin

        if (enable_in & data_rd) begin
            if (addr[7:0] == ADDR_SAMPLE_REG) 
                data_out <= {15'b0, sample_register};
            else if (addr[7:0] == ADDR_SAMPLE_CNT) 
                data_out <= sample_cnt;
            else if (addr[7:0] == ADDR_STATUS_REG)
                data_out <= POSITION;
            else
                data_out <= 16'b0;
        end else
            data_out <= 16'b0;

        if (data_out_valid & output_sample & (channel_select == POSITION)) 
            sample_data <= {sample_cnt, POSITION, sample_register};
        else 
            sample_data <= 0;

    end
end


/* Drive output pin from MSB of nco_pa statemachine if output is enabled. */
assign pin = (enable_pin_output) ? nco_pa[31] : 1'bZ; /*Z or 0 */
assign pin_input = pin;


/* ------------------ CAPTURE FROM COMMAND BUS ---------*/

reg reset_cmd = 1'b0;
reg reset_rec_time_register = 1'b0;
reg reset_sample_registers = 1'b0;

always @ (posedge clk) begin
    if (reset) begin
        nco_counter <= 0;
        sample_rate <= 0;
        end_time <= 0;
        rec_start_time <= 0;
    end else begin
        /* This is special handling of the command register and it's kinda wonky.
        *  Problems can happen if two consequtive writes happen close in time 
        *  so that the state machine is transitioning from an execute state
        *  to idle state while a new transaction comes in.
        *
        *  The resolution is to guarantee a hold time of 1 cycle for the 
        *  command bus so that the state machine has time to reset the 
        *  command register AND realize that there is new data available.
        */
        if (reset_cmd)
            command <= 0;
        else if (enable_in & data_wr) begin
            if (addr[7:0] == ADDR_LOCAL_CMD)
                command <= data_in;   //always fetch this.
            else if (addr[7:0] == ADDR_SAMPLE_RATE)
                sample_rate[31:0] <= data_in;
            else if (addr[7:0] == ADDR_NCO_COUNTER)
                nco_counter[31:0] <= data_in;
            else if (addr[7:0] == ADDR_END_TIME)
                end_time[31:0] <= data_in;
        end

        if (reset_rec_time_register)
            rec_start_time <= 0;
        else if (enable_in & data_wr) begin
            if (addr[7:0] == ADDR_REC_START_TIME)
                rec_start_time[31:0] <= data_in;
        end

    end
end


//Say time start is 2, end time is 4. This is a period
//of 4 - 2 = 2. 
//Since we test for end time MORE than end time, end condition will happen at 5.
//but start condition happens at 3. 5-3 = 2. So we have the same period and
//we're good.
wire end_condition = current_time > end_time;
wire start_condition = rec_start_time < current_time;
wire data_out_valid = sample_cnt != 0;


/* CONTROL LOGIC STATE MACHINE */

always @ (posedge clk) begin
    if (reset) state <= idle;
    else state <= nextState;
end
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

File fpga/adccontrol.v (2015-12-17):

// Two clock domains: //  CK1 The controller domain (runs at system clock)
//  CK2 The the ADC domain; which is the serial clock in/out to the chip.
// 
// CK1 is used for access to the EBI interface and is also used for the state 
// machine that updates access_reg every clock cycle.
// CK2 is used for for clocking the DOUT and DIN lines as well as the shift reg that eats DIN
// and DOUT.

module adc_control (
    input clk,   //main system clock (75Mhz?)
    input sclk,  //clocks the serial interface.
    input reset,

    input [15:0] addr,
    input [31:0] data_in,
    input enable,
    input re,
    input wr,
    output reg [15:0] data_out,
    output reg busy,

    input output_sample,
    input [7:0] channel_select,
    output reg [31:0] sample_data,

    // interfacing the chip.
    output reg cs,
    //data line into the cip.
    output adc_din,
    //serial data from chip
    input adc_dout,

    input [31:0] current_time,
    input time_running
);



//---------- State machine control outputs 

reg [3:0] adc_clocktick_counter = 0;
//Control lines from controlling state machine to data path
reg res_adc_clocktick_counter;
reg res_outreg;
reg inc_adc_clocktick_counter;
reg shift_out; //shift out to ADC
reg shift_in; //shift into FPGA
reg copy_to_tmp;
reg load_shift_out_reg;
reg reset_current_command;
reg reset_rec_time;

//---------------------------------------------

//                          |offset                | channel| command
//Address layout: [18,17,16,15,14,13,12 | 11,10,9,8| 7,6,5,4,3,2,1,0]
parameter MIN_CHANNEL = 0;
parameter MAX_CHANNEL = 1;

wor  controller_enable_ch;
wor  channels_selected;
genvar ch;
for (ch = MIN_CHANNEL; ch <= MAX_CHANNEL; ch = ch + 1) begin : enable_for_generator
    assign controller_enable_ch = (addr[15:8] == ch);
    assign channels_selected = (channel_select == ch);
end
//assign controller_enable = enable & ((MIN_CHANNEL <= addr[15:8]) & (addr[15:8] <= MAX_CHANNEL));
assign controller_enable = enable & controller_enable_ch;


wire [3:0] chan_idx = channel_select-MIN_CHANNEL;
wire [3:0] int_chan_idx = addr[15:8]-MIN_CHANNEL;

reg [31:0] current_command = 0;
reg [31:0] last_executed_command = 0;

//Assumes 8 ADC channels, which is why a lot of these have second indices
//These registers 
reg [31:0] overflow_register [0:7];
reg [31:0] fast_clk_counter [0:7];

reg [15:0] sequence_number [0:7]; //Holds sequence number.

reg [15:0] shift_out_register;   //Register that holds the data that is to be shifted into the ADC
reg [15:0] shift_in_register;    //Data from the ADC. Every 16th clock cycle this will be clocked into tmp_register.

reg [15:0] tmp_register [0:7];   //Holds stored values ready to be harvested by the 'fast' timed state machine
reg [15:0] sample_register [0:7];   //Holds the actual samples from each channel

reg [31:0] end_time [0:7];
reg [31:0] rec_start_time [0:7];


integer q;
initial begin
    for(q = 0; q < 8; q = q + 1) begin
        tmp_register[q] = 0;
        sample_register[q] = 0;
        sequence_number[q] = 0;
        fast_clk_counter[q] = 1;
    end
end




localparam [3:0] 
PROGRAM  = 8'h04,
DIVIDE   = 8'h02,
ENDTIME  = 8'h03,
SAMPLE   = 8'h07,
SEQUENCE = 8'h08,
ID_REG   = 8'h09,
BUSY     = 8'h0A,
LAST     = 8'h0B,
REC_START_TIME = 8'hC,
OVERFLOW = 8'h0D;

localparam ADC_CMD_NEW_VALUE = 1;

//Data capture from EBI
//--------------------------------------------------------------------
integer c;

wire end_condition = end_time[chan_idx] < current_time; 
wire start_condition = rec_start_time[chan_idx] < current_time;

reg[31:0] ebi_capture_reg = 0;
always @ (posedge clk) begin
    if (reset)  begin
        data_out <= 0;
        sample_data <= 0;
        for (c = 0; c < 8; c = c+1) begin
            overflow_register[c] <= 1;
            end_time[c] <= 0;
            rec_start_time[c] <= 0;
        end
        current_command <= 0;
    end else begin
        if (output_sample & channels_selected) begin
            //sample_data <= {sequence_number[chan_idx], sample_register[chan_idx]};
	    //note: not logical comparison
            if ((rec_start_time[chan_idx] != 0) & start_condition & !end_condition)
                sample_data <= {sequence_number[chan_idx], sample_register[chan_idx]};
            else
                sample_data <= 0;
        end
 
        //As per protocol, there will be at least one cycle after a new command 
        //comes in to give the controller time to enter the correct state AND 
        //reset the incomming command register.

        if(reset_current_command)
            current_command <= 0;
        else begin 
            if (controller_enable & wr) begin
                //Decode the command field.
                if (addr[7:0] == PROGRAM) begin
                    current_command <= data_in;
                end
            end
        end

        //recording time is a special register that allows one to 
        //start recording at some predetermined time.
        //Since we depart from idle state using this register,
        //it needs similar logic as a command, which is another 
        //way of leaving idle.
        if (reset_rec_time) begin
            for (c = 0; c < 8; c = c+1) begin
                rec_start_time[c] <= 0;
            end
        end else begin
            if (controller_enable & wr) begin
                if (addr[7:0] == REC_START_TIME) begin
                    rec_start_time[int_chan_idx] <= data_in;
                end
            end
        end

        //The other registers can be written to whenever. 
        if (controller_enable & wr) begin
            //Data driving
            if (addr[7:0] == OVERFLOW) begin
                overflow_register[int_chan_idx] <= data_in;
            end

            if (addr[7:0] == ENDTIME) begin
                end_time[int_chan_idx] <= data_in;
            end
        end

        //Driving output bus.
        if(controller_enable & re) begin
            //Getting sample values.
            if (addr[7:0] == SAMPLE) begin
                data_out <= sample_register[int_chan_idx];
            end

            if (addr[7:0] == SEQUENCE) begin
                data_out <= sequence_number[int_chan_idx];
            end


            //Getting sample values.
            if (addr[7:0] == ID_REG) begin
                data_out <= 16'h0ADC;
            end

            if (addr[7:0] == LAST) begin
                data_out <= last_executed_command;
            end

        end else
            data_out <= 0;

    end //reset ifelse enmd
end //always end





//Take top-most bit of shift_out_register and hook it directly to ADC input.
assign adc_din = shift_out_register[15];
//----------------------------------------------------------------------------
parameter NUM_STATES    = 5;
parameter init          = 5'b00001;
parameter program_adc   = 5'b00010;
parameter get_values    = 5'b00100;
parameter copy          = 5'b01000;
parameter writeback     = 5'b10000;
//parameter reset_ebi     = 5'b10000;
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

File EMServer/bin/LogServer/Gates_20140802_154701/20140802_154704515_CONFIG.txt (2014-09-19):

{
  "Sequence": {
    "SequenceItem0": {
      "Pin": "System.Collections.Generic.List`1[System.Int32]"
    },
    "SequenceItem1": {
      "Pin": "System.Collections.Generic.List`1[System.Int32]"
    },
    "SequenceItem2": {
      "Pin": "System.Collections.Generic.List`1[System.Int32]"
    },
    "SequenceItem3": {
      "Pin": "System.Collections.Generic.List`1[System.Int32]"
    },
    "SequenceItem4": {
      "Pin": "System.Collections.Generic.List`1[System.Int32]"
    },
    "SequenceItem5": {
      "Pin": "System.Collections.Generic.List`1[System.Int32]"
    },
    "SequenceItem6": {
      "Pin": "System.Collections.Generic.List`1[System.Int32]"
    },
    "SequenceItem7": {
      "Pin": "System.Collections.Generic.List`1[System.Int32]"
    },
    "SequenceItem8": {
      "Pin": "System.Collections.Generic.List`1[System.Int32]"
    },
    "SequenceItem9": {
      "Pin": "System.Collections.Generic.List`1[System.Int32]"
    },
    "SequenceItem10": {
      "Pin": "System.Collections.Generic.List`1[System.Int32]"
    },
    "SequenceItem11": {
      "Pin": "System.Collections.Generic.List`1[System.Int32]"
    }
  },
  "Results": {
    "Case 0": " TESTCASE 0  True ,True =>False False PASS",
    "Case 1": " TESTCASE 1  False,True =>True  False FAIL",
    "Case 2": " TESTCASE 2  True ,True =>False False PASS",
    "Case 3": " TESTCASE 3  True ,False=>True  False FAIL",
    "Case 4": " TESTCASE 4  False,False=>True  False FAIL",
    "Case 5": " TESTCASE 5  True ,False=>True  False FAIL",
    "Case 6": " TESTCASE 6  True ,False=>True  False FAIL",
    "Case 7": " TESTCASE 7  True ,True =>False False PASS",
    "Case 8": " TESTCASE 8  False,True =>True  False FAIL",
    "Case 9": " TESTCASE 9  False,False=>True  False FAIL",
    "Case 10": " TESTCASE 10 False,False=>True  False FAIL",
    "Case 11": " TESTCASE 11 True ,False=>True  False FAIL",
    "Case 12": " TESTCASE 12 False,False=>True  False FAIL",
    "Case 13": " TESTCASE 13 False,True =>True  False FAIL",
    "Case 14": " TESTCASE 14 True ,True =>False False PASS",
    "Case 15": " TESTCASE 15 False,True =>True  False FAIL"
  },
  "Fitness": "0.25",
  "Evaluation index": "0"
}

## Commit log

2013-06-24 Added pin LOCs for EBI addr and data
2013-06-27 double free is instant crash
    [main.c]
2013-07-03 Added state machine and supporting logic for reading a pin
2013-07-17 too much has changed I have no idea what I've done anymore
    [main.c, mecoprot.h]
2013-07-17 too much has changed.
    [pincontrol.v]
2013-07-23 Was missing some reset logic. Works better now
    [pincontrol.v]
2013-07-23 cleaned up the config pin a bit
2013-07-25 memcpy to wrong packet what the hell is wrong with me
    [main.c]
2013-07-30 fixed sample rate counters reset signal
    [pincontrol.v]
2013-08-30 fixed pin-reset signal before pin reuse in pincontroller, added support for 0-length anti-duty in const
    [main.c, pincontrol.v]
2013-11-15 Working on-board scheduling
2013-11-25 changed to using external SRAM for sample buffers. katt
2013-11-26 changed to void pointer for sampleBuffer
2013-12-18 inital commit of adc control logic module
2014-01-04 Added a lot of ADC testing stuff
2014-02-27 Added support for several boards in one server
2014-03-17 added option to skip boot tests
    [main.c]
2014-04-30 Added USB drivers for Windows
    Windows usb drivers
2014-04-30 Add support for Pin as list
    Add support for changes to data struct for switch matrix
2014-04-30 added adc
2014-05-08 giant commit of v3.5 of the schematics and such
    [8860.SchDoc, EFM32GG_Library.SchLib, MIC5248.SchDoc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]
2014-05-08 giant commit of daughterboard
    [Connector.SchDoc, GT_Schlib1.SchLib, PCB_Project1.PrjPCB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]
2014-05-09 joinSequences() now working. runSequences() will no longer block.
    [Mecobo.cpp]
2014-05-09 Removed compiler warning and fixed up firmware files
    [main.c, mecoprot.h]
2014-05-14 BUSY in the AD controller now depends also on ebi_capture_reg. This will be reset by AD clock path eventually, so it should be safe
    [Mecobo.cpp, adccontrol.v]
2014-05-15 Added support for digital inputs and ouputs. Untested so it doesn't work.
    [Mecobo.cpp, main.c, mecoprot.h]
2014-05-19 Digital pins now output correct square waves
    [Mecobo.cpp]
2014-05-19 throw error on > 100 items
    [main.c]
2014-05-19 Removed some old no longer used commands and removed some debug printing
    [main.c, mecoprot.h]
2014-05-20 redid xbar. does not work :
    [xbar_control.v]
2014-05-21 open digital switches when not using analogue
2014-05-21 Various XBAR bugfixes and DAC register test
    [main.c]
2014-05-28 Moved some initialization code out to efm32.c, and also remembered to reset all the timers on reset
    [main.c]
2014-05-28 fixes for inf runtime
    [main.c]
2014-06-19 invert leds
2014-06-24 fixed bug that mismapped AD channels to Xbar pins, and also fixed max number of IO channels
    [Mecobo.cpp, main.c]
2014-06-24 no more printing
2014-08-26 data logger
    and some tests
    [embedder.obj, make.cfg]
2014-08-28 Debug print
2014-09-10 Bugfixes and some files added
    [main.c, mecoprot.h]
2014-09-10 fixed toplevel for pin reroute with daughterboard
2014-09-18 Fixed starting time bug where items with t!=0 never got started
    [main.c]
2014-09-18 Fixed scheduling bug; DAC did not reset it's value when item was killed
    [main.c]
2014-09-19 Added support for several boards
2014-09-19 Big big commit, forgive me
    [20140802_154704515_CONFIG.txt, 20140802_154707919_CONFIG.txt, 20140802_154711284_CONFIG.txt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]
2014-12-17 This removes the 'duty cycle' stuff, and replaces it with a NCO
    [adccontrol.v, pincontrol.v]
2014-12-17 Uncompiled commit of the software fixes for the updated frequency fixing
    [Mecobo.cpp, main.c, mecoprot.h]
2015-01-23 Transaction bug fixed -- now detecting edges more or less sanely with a double set of FFs
    [adccontrol.v, pincontrol.v]
2015-01-26 Enabled higher amounts of sample collections, the max number of samples is now 65000
2015-01-27 fixed receving longer usb sample buffers
    [Mecobo.cpp, main.c]
2015-01-28 Fixed constant output from digital pin controllers
    [pincontrol.v]
2015-01-30 Introduced DEBUG printing define.
2015-04-13 Fixed bug when assigning channel number to pin, DA -> AD :)
2015-04-13 All done with fixing annoying bad silly working on wrong branch argh
    [mecoprot.h]
2015-04-14 farting about with the NOR, doesn't even work
    [Mecobo.cpp, efm32.c, main.c]
2015-05-11 Changes that do not work
    [efm32.c, main.c]
2015-05-11 still not working nor
    [efm32.c, main.c]
2015-05-13 Added new firmare and updated toplevel file for FPGA to match the new board
2015-06-10 Fixed compilation errors and updated synthesized bitfile
    [ebi.v]
2015-06-10 changed behaviour of interrupts
2015-06-24 well, it synthesizes again due to fixes here
    [pincontrol.v]
2015-06-25 fixed lots of port size mismatches
    [ebi.v, scheduler.v]
2015-06-25 try to get around padding issue by rearrangig struct
    [main.c, pincontrol.v, scheduler.v]
2015-06-26 Reorganized pincontrol module and added a reset-time command on address 0xFFFF
    [main.c, pincontrol.v, scheduler.v]
2015-06-26 stupid mistake in address widths
    [main.c, pincontrol.v, scheduler.v]
2015-06-29 new module! the sample collector, based on mem.v
2015-06-29 coregen sample fifo
2015-06-29 implemented sample fetching
2015-06-30 indent fail, but fixed signals
    [main.c]
2015-06-30 weird mistake in code
    [main.c, pincontrol.v]
2015-06-30 updated to support new pin controllers
2015-06-30 rewrote sample collector to 2-state state machine without testing.
2015-07-01 reset now happens on EBI
    [ebi.v, main.c, scheduler.v]
2015-07-01 trying to fix the clock
    [ebi.v, main.c]
2015-07-02 small fix to make the reset happy
    [ebi.v]
2015-07-02 Special case for end time = 0 in pin controller
2015-07-03 command is wrong way around
    [ebi.v, main.c]
2015-07-03 trying to avoid rogue time resets
    [ebi.v]
2015-07-06 added wait state in scheduler to allow command bus to capture data. possible bug?
    [scheduler.v]
2015-07-06 added reset for sample_reg register
    [main.c, pincontrol.v]
2015-07-06 removed silly command reset logic stuff
    [main.c, pincontrol.v, scheduler.v]
2015-07-07 Rewrote sample_collector interface
2015-07-07 added sample fifo reset command
    [main.c]
2015-08-07 added test and fixed waiting bug
    [Mecobo.cpp, main.c, scheduler.v]
2015-08-11 added end time register to adc controller per channel
2015-10-09 added end time condition to pin controller recording
2015-10-19 think i fixed the pincontroller recording stuff
    [ebi.v, pincontrol.v, scheduler.v]
2015-10-28 removed annoying reset waits
    [main.c]
2015-11-10 Reordered stdio.h include to avoid some idiotic printf warnings
    [main.c]
2015-11-16 Added schematics for the national instruments breakout board
    [Power.SchDoc, Sheet1.SchDoc, crossBarNIPCB_Project2.PrjPCB]
2015-11-19 table index shift wrong
    [main.c]
2015-11-19 added setup code for AD and DA. doesn't matter if it runs even though a card is not connected
    [main.c]
2015-11-24 fixed ADC scaling issue
    [Mecobo.cpp, main.c]
2015-11-24 critical fix of fpga west header shit
    [main.c]
2015-11-26 Unit tests for analog input
    Add several tests for the ADC:
    * Analog read of constant digital output
    * Analog read of constant analog output
    * Analog read of digital frequency output
    * Analog read of linear analog signal
    * Analog read of sine wave analog signal
    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
2015-11-26 Unit tests for digital input
    Add several tests for digital sampling:
    * Digital read of constant digital output
    * Digital read of constant analog output
    * Digital read of digital frequency output
    * Digital read of linear analog signal
    * Digital read of sine wave analog signal
    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
2015-11-27 added led to indicate time running
2015-11-27 sample controller now returns beef as default, not ffff
2015-12-02 Sample time rounded down in tests
2015-12-07 only pin 3 not working
    [Mecobo.cpp, main.c]
2015-12-07 FPGA more or less working, but still unsatisfactory weird sample count variation
2015-12-07 potential fix for zeroes in sample buffer in pincontrol digital sampling
    [pincontrol.v]
2015-12-07 change from big less-than-OR-equal to less-than in adc recording-start conditional check
2015-12-08 fixed unvalid samples at start of sample collection by not starting sampling before sample counter has increased
    [pincontrol.v, scheduler.v]
2015-12-09 added reset check for xbar. jsut silly
    [Mecobo.cpp, main.c]
2015-12-09 This introduces a wait in the reset() of the microcontroller. I have no idea why it's needed. Timing is hard :(
    [Mecobo.cpp, main.c]
2015-12-10 failed timing fix. channelselect off by 1?
    [adccontrol.v, pincontrol.v, scheduler.v]
2015-12-14 added new_unit register on FPGA. this is the corresponding fix that sets this reg when doing setupInput()
    [main.c]
2015-12-15 Fix n_samples calculations in all tests
    Fixes some errors due to rounding up of sample_time
    Adjust tests accordingly as MSEs are lower
2015-12-15 new bitfile with daughterboard fix
    [ebi.v]
2015-12-15 Terrible big fixing in pincontrol to fix 0-constant output
    [pincontrol.v]
2015-12-16 fixes issue with > 256 commands, but you must run with 30us separation
    [main.c]
2015-12-17 Fixed bug for assigning ADC pins to XBAR
    [main.c]
2015-12-17 Add 1us to sample_time to ensure we get enough samples
2015-12-17 Avoid 1.5V (threshold) for digital constant test
2016-02-01 maximum pin-number issue possibly fixed
2016-03-14 Added the magic printfs that make the NOR work... :(
